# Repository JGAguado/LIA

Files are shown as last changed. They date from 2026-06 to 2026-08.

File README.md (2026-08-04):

[](LICENSE)
[][maintenance]
[][meshtastic]
[][docs]

<p align="center">
    <picture>
      <source media="(prefers-color-scheme: dark)" srcset="https://raw.githubusercontent.com/JGAguado/LIA/main/website/src/assets/brand/Primary%20dark.png">
      <source media="(prefers-color-scheme: light)" srcset="https://raw.githubusercontent.com/JGAguado/LIA/main/website/src/assets/brand/Primary%20light.png">
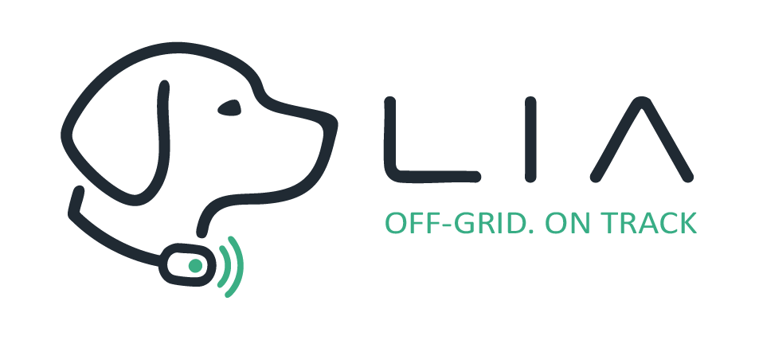
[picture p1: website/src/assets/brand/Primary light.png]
LIA logo
      
    </picture>
</p>

**LIA** is an open-source, low-power pet and asset tracker built on top of [Meshtastic](https://meshtastic.org/) and LoRa mesh networking. It's designed to be a compact, long-range, subscription-free tracking device that keeps working off-grid — no cell coverage, no monthly fee, no cloud dependency.

📖 **[Read the full documentation](https://jgaguado.github.io/LIA/)**

<p align="center">
    <a href="https://youtu.be/8NeL7x7pOoo">
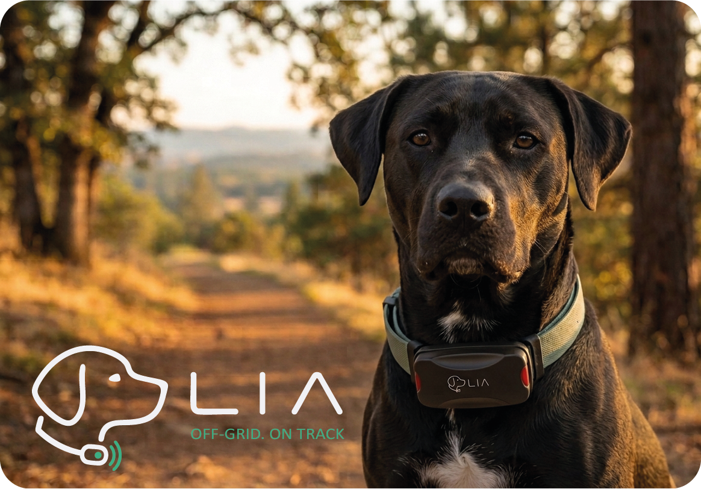
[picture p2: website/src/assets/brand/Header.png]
LIA demo video — click to watch on YouTube
      
    </a>
</p>

---

## Features

- Long-range LoRa communication over the open Meshtastic protocol
- GPS/GNSS location tracking, sent only as a direct message to a predefined target node — not visible to the wider public mesh
- A physical 3-position mode switch: continuous tracking (LED on, position every 30s), a low-power sleep cycle (wake roughly once a minute, get a fix, report it, sleep again), or fully OFF (cuts power to the MCU while still allowing the battery to charge)
- A text-command interface over the mesh: query position/battery on demand, toggle charge/motion notifications, override the status LED — see [Meshtastic Configuration](https://jgaguado.github.io/LIA/docs/firmware/meshtastic-configuration/)
- Deep-sleep, low-power firmware with real hardware wake sources (timer, mode-switch flip, charger plug-in)
- Subscription-free — no cloud backend required
- Fully open hardware: schematics, PCB layout, BOM, and enclosure CAD
- Compact, collar-mountable, waterproof-by-design enclosure — in three variants, see below

## Hardware Stack

**Core components**

- ESP32-S3-MINI-1 (MCU, Wi-Fi/BLE)
- SX1262 LoRa transceiver
- u-blox SAM-M10Q GNSS module
- MAX17048 battery fuel gauge

**Two hardware revisions, one firmware**

Both revisions carry the same reworked LSM6DSOXTR 6-axis IMU and run the identical `lia_v1` firmware — the only difference is the battery/enclosure:

- **V1.0** — 18650 Li-ion cell (3500 mAh) with magnetic pogo charging.
- **V1.1** — a 50×37×4 mm pouch cell (1000 mAh) instead, trading capacity for a much more compact enclosure.

**Antennas**

- Internal FPC LoRa antenna, or alternatively a standard omnidirectional linear 868/915 MHz antenna (e.g. [Seeed's LoRa Antenna Kit](https://www.seeedstudio.com/LoRa-Antenna-Kit-for-reTerminal-DM-p-5714.html))
- Ceramic GNSS patch antenna

See [Hardware documentation](https://jgaguado.github.io/LIA/docs/hardware/pcb/) for full details, and [Enclosure](https://jgaguado.github.io/LIA/docs/hardware/enclosure/) for the enclosure variants that pair with these boards.

## Software Stack

- [Meshtastic](https://meshtastic.org/) firmware
- [Astro](https://astro.build/) + [Starlight](https://starlight.astro.build/) + [Tailwind CSS](https://tailwindcss.com/) for this documentation site (fully static, no backend, no analytics, no cookies)

## Repository Structure

```
LIA/
├── website/       Astro + Starlight documentation & marketing site
├── firmware/       Meshtastic-based firmware (board variants, services, drivers, build tooling)
├── hardware/       KiCad project, PCB renders, schematics, BOM, production files
├── enclosure/       Enclosure CAD (gitignored native files), STEP/STL exports, renders — V1.0-Detachable/, V1.0-Fixed/, V1.1-Fixed/
├── mobile/         Companion mobile app (planned)
├── scripts/       Repo maintenance and tooling scripts
├── .github/       CI/CD workflows, issue & PR templates
├── LICENSE
├── CONTRIBUTING.md
├── CODE_OF_CONDUCT.md
└── README.md
```

## Quick Start

**Browse the docs:** https://jgaguado.github.io/LIA/

**Run the website locally:**

```sh
cd website
npm install
npm run dev
```

**Hardware:** open [`hardware/kicad/LIA.kicad_pro`](hardware/kicad/LIA.kicad_pro) in [KiCad](https://www.kicad.org/) 8+.

**Enclosure:** three versions — [`enclosure/V1.0-Detachable/`](enclosure/V1.0-Detachable), [`enclosure/V1.0-Fixed/`](enclosure/V1.0-Fixed), [`enclosure/V1.1-Fixed/`](enclosure/V1.1-Fixed) — each with its own `step/`/`stl/` exports and `drawings/`; no CAD license required to view or print them. See [Enclosure docs](https://jgaguado.github.io/LIA/docs/hardware/enclosure/) for what differs between them.

**Firmware:** see [`firmware/README.md`](firmware/README.md) and the [Getting Started guide](https://jgaguado.github.io/LIA/docs/getting-started/).

## Contributing

Contributions are welcome across hardware, firmware, mechanical design, and documentation. See [CONTRIBUTING.md](CONTRIBUTING.md) for how to get set up, and [CODE_OF_CONDUCT.md](CODE_OF_CONDUCT.md) for community guidelines.

## License

LIA is released under **[CC BY-NC-SA 4.0](LICENSE)** (Attribution-NonCommercial-ShareAlike). Personal, educational, and community use is welcome; commercial use requires permission from the maintainers. See the [License page](https://jgaguado.github.io/LIA/docs/license/) for details.

## Roadmap
- [x] Draft project requirements and design goals
- [x] Complete first hardware revision (V1.0) and a second, more compact revision (V1.1)
- [x] Complete first enclosure revisions — V1.0-Detachable, V1.0-Fixed, and V1.1-Fixed
- [x] Manufacture and assemble first batch of boards
- [x] Smoke-test and validate hardware (radio, GPS, charging, battery gauge, IMU)
- [x] Release first firmware — see [Development History](https://jgaguado.github.io/LIA/docs/development-history/) for the phase-by-phase log
- [x] Release initial documentation
- [x] Field trial: real-world tracking validation over an extended period
- [x] Measured (not estimated) battery runtime numbers

## Disclaimer

LIA is an experimental open-source project and should not be considered a guaranteed real-time safety tracking solution.

[license-shield]: https://img.shields.io/badge/License-CC%20BY--NC--SA%204.0-lightgrey.svg?style=for-the-badge
[maintenance-shield]: https://img.shields.io/badge/maintainer-J.%20G.%20Aguado-2e48a7.svg?style=for-the-badge
[maintenance]: https://github.com/JGAguado
[meshtastic-shield]: https://img.shields.io/badge/Powered%20by-Meshtastic-67EA94.svg?style=for-the-badge
[meshtastic]: https://meshtastic.org/
[docs-shield]: https://img.shields.io/badge/Documentation-online-2e48a7.svg?style=for-the-badge
[docs]: https://jgaguado.github.io/LIA/

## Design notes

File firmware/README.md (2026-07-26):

# LIA Firmware

Meshtastic-based firmware for the LIA pet tracker (ESP32-S3-MINI-1-N8). See
[`AGENTS.md`](AGENTS.md) for the full hardware spec, architecture, and
phase-by-phase roadmap, [`docs/phase-status.md`](docs/phase-status.md) for
detailed, evidence-quoted validation notes against that roadmap, and the
[Development History](https://jgaguado.github.io/LIA/docs/development-history/)
page on the docs site for the same story told chronologically.

## One board variant, two hardware revisions

There is a single firmware/board variant, `lia_v1`, and it's the correct
build for every LIA board. It requires a solder rework crossing `SDA`/`SCL`
back on the LSM6DSOXTR IMU's connection (miswired as manufactured, which
caused I2C bus errors) before I2C -- and therefore the IMU and the MAX17048
battery gauge -- can be enabled; both hardware revisions in circulation now
have that rework done. Do not assume I2C works on an unreworked board.

The two hardware revisions, **V1.0** and **V1.1**, are a **battery/enclosure
distinction only** (see
[Battery](https://jgaguado.github.io/LIA/docs/firmware/battery/) and
[Enclosure](https://jgaguado.github.io/LIA/docs/hardware/enclosure/)) -- V1.0
takes an 18650 3500mAh cell, V1.1 a 5023450 1000mAh cell. Nothing about the
firmware differs between them; there is no `lia_v2` variant.

## Repository layout

```
firmware/
├── AGENTS.md                        Hardware spec, architecture, and roadmap (read this first)
├── board/                           LiaBoard: peripheral power, RED LED, BMS switch, charger status
├── drivers/                         ImuMotionDriver -- talks to the LSM6DSOXTR directly (see below)
├── services/
│   ├── MeshTargets.h                Shared target NodeNum (kLiaTargetNode) -- see "Provisioning" below
│   ├── TrackerService.h/.cpp        Position broadcasts + the BMS state machine + manual LED override
│   ├── ChargeStatusService.h/.cpp   "Charging"/"Device charged" notifications
│   └── CommandService.h/.cpp        Text-command interface -- GPS, BATTERY, IMU/CHG/STB/LED ON/OFF, HELP
├── docs/                            Phase validation notes
├── tools/
│   ├── build.ps1                    Build/flash helper (-Upload -Port)
│   ├── gps_test/                    Standalone GPS bring-up test (no Meshtastic)
│   └── battery_test/                Standalone MAX17048 bring-up test (no Meshtastic)
└── meshtastic/                       Overlay applied on top of a Meshtastic firmware checkout
    ├── boards/lia_v1.json
    ├── variants/esp32s3/lia_v1/    (variant.h, pins_arduino.h, platformio.ini)
    └── extra_variants/lia_v1/     (variant.cpp -- init hooks + deep-sleep wake sources)
```

Meshtastic's own firmware (`meshtastic/firmware` on GitHub) is **not**
vendored into this repository — it's a large, independently-versioned
project. Building for LIA means applying the files under `meshtastic/`,
`board/`, `drivers/`, and `services/` on top of a checkout of it, the same
way any out-of-tree Meshtastic board variant is built.

## Building

`tools/build.ps1` automates the steps below (clone-if-missing, checkout the
pinned tag, copy the overlay, `pio run`). From a **native PowerShell**
session (not Git Bash/MSYS -- the ESP-IDF toolchain this platform pulls in
refuses to run under MSYS):

```powershell
cd firmware/tools
./build.ps1                              # builds lia_v1 -- correct for both V1.0 and V1.1 boards
./build.ps1 -Upload -Port COM7            # build and flash in one step
```

Or manually:

1. Clone Meshtastic's firmware repository and check out a tagged release
   (`main` is a moving development branch):

   ```powershell
   git -c core.longpaths=true clone --recurse-submodules --depth 1 `
     --branch v2.7.26.54e0d8d https://github.com/meshtastic/firmware.git meshtastic-firmware
   ```

   `core.longpaths=true` is required on Windows -- some paths inside this
   repo exceed 260 characters.

2. Copy this repo's overlay into the checkout:

   ```powershell
   Copy-Item firmware/meshtastic/boards/lia_v1.json meshtastic-firmware/boards/
   New-Item -ItemType Directory -Force meshtastic-firmware/variants/esp32s3/lia_v1
   Copy-Item firmware/meshtastic/variants/esp32s3/lia_v1/* meshtastic-firmware/variants/esp32s3/lia_v1/
   New-Item -ItemType Directory -Force meshtastic-firmware/src/platform/extra_variants/lia_v1
   Copy-Item firmware/meshtastic/extra_variants/lia_v1/* meshtastic-firmware/src/platform/extra_variants/lia_v1/
   New-Item -ItemType Directory -Force meshtastic-firmware/src/lia
   Copy-Item firmware/board/*.h, firmware/board/*.cpp meshtastic-firmware/src/lia/
   Copy-Item firmware/drivers/*.h, firmware/drivers/*.cpp meshtastic-firmware/src/lia/
   New-Item -ItemType Directory -Force meshtastic-firmware/src/lia/services
   Copy-Item firmware/services/*.h, firmware/services/*.cpp meshtastic-firmware/src/lia/services/
   ```

3. Build:

   ```powershell
   cd meshtastic-firmware
   pio run -e lia_v1
   ```

4. Flash:

   ```powershell
   pio run -e lia_v1 -t upload --upload-port <PORT>
   ```

## Provisioning

Set `device.role = TRACKER`. Everything LIA-specific (position broadcasts,
charge-status messages, and every `CommandService` command/reply) is a
direct message to a single hardcoded target node (`MeshTargets.h`'s
`kLiaTargetNode`, derived from that node's MAC), not a channel broadcast --
building your own copy means editing that constant to your own target
node's NodeNum first. See
[Meshtastic Configuration](https://jgaguado.github.io/LIA/docs/firmware/meshtastic-configuration/)
for why.

## Standalone bring-up tests

Two small, Meshtastic-free PlatformIO projects under `tools/` isolate
specific hardware questions from the rest of the firmware's complexity:

- **`tools/gps_test/`** -- powers the GNSS module and prints whatever it's
  decoded every 10 seconds.
- **`tools/battery_test/`** -- prints the MAX17048's charge percentage and
  cell voltage every 2 seconds via two independently-computed read paths
  side by side. This is what isolated a real gauge-reading bug (see
  [Battery](https://jgaguado.github.io/LIA/docs/firmware/battery/)).

Each has its own `platformio.ini` and README.

## Resolved hardware assumptions

These were open questions at some point during development and are noted
here for anyone reading history/commits rather than the current code:

- **BMS switch polarity** -- resolved in favor of `AGENTS.md`'s convention
  (HIGH = continuous, LOW = sleep-cycle) over an earlier, differently-worded
  planning doc.
- **Charger status polarity** (`CHG`/`STBY`) -- resolved against the actual
  TP4056 wiring: `CHG` active-low while charging, `STBY` pulled high
  externally while charging and pulled low by an internal switch on
  completion.
- **RED LED polarity** -- resolved against real hardware: the channel
  lights when driven high, not low as originally assumed.
- **I2C bus errors on `lia_v1`** -- resolved via a solder rework crossing
  `SDA`/`SCL` back on the IMU's connection; see "One board variant, two
  hardware revisions" above.

Still open: **SX1262 DIO2/DIO3** (`SX126X_DIO2_AS_RF_SWITCH`,
`SX126X_DIO3_TCXO_VOLTAGE 1.8`) are inherited from the Wio-SX1262 module's
reference design, not independently confirmed against LIA's own schematic.

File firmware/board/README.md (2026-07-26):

# LiaBoard

Hardware abstraction for the peripherals on LIA's board that stock Meshtastic
has no concept of. Sits between the `lia_v1` board variant and the rest of
the firmware, per `firmware/AGENTS.md`'s architecture:

```
Meshtastic Core -> Board Definition -> LiaBoard -> Drivers -> TrackerService
```

## What it owns

| Method | Backing pin | Notes |
| --- | --- | --- |
| `enablePeripherals()` / `disablePeripherals()` | `LIA_PIN_PPC` (GPIO21) | Gates power to the SX1262 and SAM-M10Q. Must be enabled before either is touched. |
| `setRedLed(uint8_t)` | `LIA_PIN_LED_RED` (GPIO40) | Active-high PWM, 0 = off / 255 = full brightness (see "Open questions"). |
| `isCharging()` | `LIA_PIN_CHG` (GPIO1) | TP4056 `CHRG`, open-drain active-low. |
| `isChargeComplete()` | `LIA_PIN_STBY` (GPIO2) | True when `STBY` reads LOW -- pulled HIGH externally while charging, pulled LOW by an internal N-MOSFET on completion (confirmed 2026-07-22, see "Open questions" below). |
| `isBmsHigh()` | `LIA_PIN_BMS` (GPIO15) | Mode-switch reading. HIGH = continuous/no-sleep, LOW = wake-every-minute sleep cycle -- see `TrackerService` (Phase 6). The switch is physically 3-position; the third (OFF) cuts power to the regulator feeding the ESP32-S3 entirely (battery still charges), so there's no firmware state for it -- `isBmsHigh()` only ever runs while the switch is already in one of the other two positions. |

It deliberately does **not** touch the SX1262 or SAM-M10Q themselves (that's
stock Meshtastic, driven by the pin `#define`s in
[`variant.h`](../meshtastic/variants/esp32s3/lia_v1/variant.h)), and never
touches the green/blue LED channels -- unavailable on this PCB revision (see
`firmware/AGENTS.md` "Hardware Constraints"). It also doesn't touch I2C: no
LIA-specific code is needed there either -- see "Open questions" below and
`firmware/services/README.md` for how the MAX17048 battery gauge (and the
LSM6DSOXTR IMU) get picked up automatically by stock Meshtastic.

## Wiring into Meshtastic

`LiaBoard` is a Meyer's singleton (`LiaBoard::instance()`) rather than a
global, per the "No globals" coding standard. It's driven from
[`extra_variants/lia_v1/variant.cpp`](../meshtastic/extra_variants/lia_v1/variant.cpp):

- `earlyInitVariant()` calls `begin()` then `enablePeripherals()`. This runs
  *before* `initSPI()` and before Meshtastic's own radio/GPS init (which
  happens later, inside `setupModules()`) -- PPC must already be high by
  then, so this cannot be done from `lateInitVariant()` (confirmed against
  `src/main.cpp` and `src/platform/extra_variants/README.md` in the
  Meshtastic checkout: `lateInitVariant()` runs *after* the LoRa radio is
  initialized).
- Deep-sleep power-down (`disablePeripherals()`) is wired to Meshtastic's
  `notifyDeepSleep` observable (Phase 6). This fires for any deep sleep path
  system-wide, not just `TrackerService`'s own `doDeepSleep()` calls --
  confirmed this actually runs for LIA: Meshtastic only *skips* calling
  `notifyDeepSleep` when `shouldLoraWake()` is true, which is only the case
  for `ROUTER`/`ROUTER_LATE` roles (`sleep.cpp`), not `TRACKER`.
  **Registration point matters**: `RadioInterface::init()` and
  `GPS::setup()` *each also* register their own `notifyDeepSleep` observer
  (to command the SX1262/GNSS to standby gracefully over SPI/UART while
  still powered), both before `lateInitVariant()` runs. `Observable` fires
  observers in registration order, so `armDeepSleepHook()` (which does the
  actual `.observe()` call) must be called from `lateInitVariant()`, *not*
  from `begin()`/`earlyInitVariant()` -- registering earlier cuts PPC before
  those graceful commands can reach the hardware. Confirmed by a real crash
  (`SX126xInterface::setStandby()` failing with `RadioLib err=-707` once PPC
  had already gone low first) before this was fixed.

## Open questions

- ~~**I2C bus errors.**~~ As-manufactured, SDA/SCL were crossed on the
  LSM6DSOXTR IMU's connection, causing bus errors -- `variant.h` originally
  forbade defining `I2C_SDA`/`I2C_SCL` at all. This unit has since had a
  solder rework crossing them back (2026-07-22); `variant.h` now defines
  those macros (GPIO4/5). **This does not apply to an unreworked board** --
  don't assume I2C works without the same rework.
- ~~**RED LED polarity.**~~ Resolved 2026-07-22: `setRedLed()` was assumed
  common-anode (channel lights when driven LOW) and inverted its duty cycle
  accordingly. Real hardware showed the LED ON while BMS read LOW (which
  calls `setRedLed(0)`, intending OFF) -- the channel actually lights when
  driven HIGH, so the inversion was removed. Confirmed against
  `TrackerService`'s already-independently-confirmed BMS branching (send
  cadence, sleep triggering), so the mismatch was isolated to the LED driver,
  not the BMS read.
- ~~**BMS polarity.**~~ Resolved 2026-07-19: follow `firmware/AGENTS.md`
  (Phase 6) as the authoritative source -- BMS HIGH is continuous/no-sleep,
  BMS LOW is the wake-every-minute sleep cycle. `MOD.md`'s opposite polarity
  ("BMS high = Tracker mode" = the sleepy behaviour) is not used.
- ~~**Charger status polarity.**~~ Resolved 2026-07-22: `isCharging()` is
  `CHG` active-low (an internal N-MOSFET pulls it low while charging;
  external pull-up otherwise) -- matches the original datasheet assumption,
  unchanged. `isChargeComplete()` is `STBY` active-low (external pull-up
  holds it HIGH while charging; an internal N-MOSFET pulls it LOW on
  completion) -- this briefly went through an incorrect active-HIGH flip
  earlier in Phase 7 (per an instruction that didn't match the actual
  wiring) before being corrected back to active-low against the real board
  behaviour.
- **GPS fix-wait timeout for the BMS-low sleep cycle** (`TrackerService.h`'s
  `kFixWaitTimeoutMs`, currently 90s) is a real tradeoff (battery vs. fresh
  position) not yet validated against actual cold/warm-fix timing outdoors --
  see the website's power-management.md "GPS fix timeout" note.

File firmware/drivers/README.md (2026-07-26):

# Drivers

## ImuMotionDriver

Talks to the LSM6DSOXTR IMU (`lia_v1` only) directly via `Adafruit_LSM6DSOX`,
bypassing Meshtastic's own `AccelerometerThread`/motion-sensor support:
`ScanI2CTwoWire` resolves this chip's `WHO_AM_I` (`0x6C`) to its `QMI8658`
device type, which `AccelerometerThread` has no `case` for at all -- it
silently falls through to `disable()`, so stock Meshtastic never actually
drives this sensor. `Adafruit_LSM6DSOX` is the correct match instead: `0x6C`
is exactly that class's expected chip ID.

Owned by `CommandService` (not a Meyer's singleton like `LiaBoard` -- nothing
else needs to reach it), which starts/stops it on the `IMU ON`/`IMU OFF`
commands (see `../services/README.md`). Arms a real hardware interrupt on
`LIA_PIN_IMU_INT` rather than polling the sensor's status register: the ISR
only sets a flag (I2C isn't interrupt-safe), consumed from a normal task
context to send the actual "Activity detected" mesh message.

## What's still handled elsewhere

- **SX1262 radio** and **SAM-M10Q GNSS** -- stock Meshtastic behaviour,
  switched on purely by the pin `#define`s in
  [`../meshtastic/variants/esp32s3/lia_v1/variant.h`](../meshtastic/variants/esp32s3/lia_v1/variant.h).
  Meshtastic already contains a full SX1262 (RadioLib) and NMEA/UBX GPS
  stack.
- **Peripheral power, status LED, mode switch, charger status** -- owned by
  [`../board/LiaBoard.*`](../board/README.md), since none of them are stock
  Meshtastic concepts but all are simple enough (plain GPIO/PWM) not to
  warrant a separate driver class.
- **MAX17048 battery gauge** -- no dedicated driver class; `CommandService`
  reads it directly with `Adafruit_I2CDevice`/`Adafruit_BusIO_Register` (see
  `../services/README.md` for why, and `../tools/battery_test/` for the
  standalone test that isolated a real reading bug).

If a future phase needs a peripheral that doesn't fit either of those
buckets, it belongs here as its own subdirectory with a `README.md`,
`examples`, and `tests`, per `firmware/AGENTS.md`'s repository layout.

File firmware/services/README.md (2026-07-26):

# Services

## Battery gauge + IMU (I2C)

`variant.h` defines `I2C_SDA`/`I2C_SCL`, which is enough for stock
Meshtastic's `Wire.begin(I2C_SDA, I2C_SCL)` + `i2cScanner->scanPort()`
(`src/main.cpp`) to detect both parts at boot -- confirmed via the boot log
(`MAX17048 found at address 0x36`, `QMI8658 found at address 0x6b`, `2 I2C
devices found`). This only works because of a solder rework crossing
SDA/SCL back on the IMU's connection (2026-07-22) -- see `board/README.md`
"Open questions" for why the bus was unusable before that.

Detection stops there for the IMU, though: `ScanI2CTwoWire` resolves the
LSM6DSOXTR's `WHO_AM_I` (0x6C) to its `QMI8658` device type, and
`AccelerometerThread` (`motion/AccelerometerThread.h`) has no `case` for
that type at all -- it silently falls through to `disable()`. So unlike the
gauge, stock Meshtastic never actually drives this IMU. `CommandService`'s
`ImuMotionDriver` (`drivers/ImuMotionDriver.*`) talks to it directly instead,
via `Adafruit_LSM6DSOX` (0x6C matches that class's expected chip ID exactly,
unlike the `Adafruit_LSM6DS3TRC` class Meshtastic's own `LSM6DS3Sensor.cpp`
uses for a different chip ID).

Similarly, `CommandService`'s `BATTERY` command reads the `Adafruit_MAX1704X`
gauge directly rather than through `powerStatus->getBatteryChargePercent()`:
`Power::setup()` runs its own battery-source detection *before* `main.cpp`'s
I2C scan populates the sensor map that detection depends on, so it always
sees "not ready yet" at boot and locks in a 101% ("no battery, external
power") fallback that never gets corrected later -- confirmed on real
hardware (2026-07-22), even though the gauge is genuinely present and
working.

## MeshTargets.h

Shared configuration used by every service that reports to the configured
target node: `kLiaTargetNode` (NodeNum, per `firmware/AGENTS.md` "Target
Node") lives in `MeshTargets.h` -- the one place it's defined, so
`TrackerService`, `ChargeStatusService`, and `CommandService` can't drift
apart. Everything LIA-specific is a direct message (`p->to = kLiaTargetNode`)
to this node, never a channel broadcast -- per explicit instruction
(2026-07-26), superseding an earlier design that routed everything through a
channel found by name (`kLiaChannelName`/`ChannelLookup.h/.cpp`, both
removed). That design worked but required out-of-band channel setup and
failed closed silently when misconfigured; a direct message already
requires knowing/pairing with the target node and is commonly
PKI-encrypted by the official app to that node's identity key, so it isn't
a weaker bar than possessing a channel's PSK.

## TrackerService

Owns periodic mesh transmissions and the tracker/beacon state machine, per
`firmware/AGENTS.md`'s architecture. Sends the current GPS position
(`meshtastic_Position`, port `POSITION_APP`) as a unicast, built from the
global `localPosition` (`NodeDB.h`) the same way stock `PositionModule.cpp`
does -- skips the send if there's no fix yet (lat/lon both zero) rather than
sending a meaningless (0,0). The destination is `kLiaTargetNode`
(`MeshTargets.h`).

### Direct-message targeting

Position packets are sent as a direct message to `kLiaTargetNode`, never a
broadcast on any channel. Meshtastic encrypts per-channel (not
per-recipient) and `PositionModule` processes any overheard position packet
promiscuously regardless of its `to` field, so broadcasting on any channel
would let *any* node holding that channel's PSK map this device -- a direct
message to a specific node, commonly PKI-encrypted by the official
app/firmware, restricts visibility to that one node instead, per explicit
instruction (2026-07-26; see "MeshTargets.h" above for why this replaced an
earlier private-channel design).

Behaviour switches on `LiaBoard::instance().isBmsHigh()` (Phase 6):

- **HIGH ("continuous")**: RED LED solid on, send every 30s
  (`kContinuousIntervalMs`), never sleeps.
- **LOW ("sleep-cycle")**: send once, then deep sleep for a minute
  (`kSleepCycleMs`) via `doDeepSleep()`. `LiaBoard`'s `notifyDeepSleep`
  observer cuts PPC (both SX1262 and GPS power, shared rail) before power-off.
  The next wake is a full reboot -- construction and `runOnce()` start fresh,
  so no state survives between wakes except what's in `localPosition`
  (persisted by the GPS subsystem, not us). Waits up to `kFixWaitTimeoutMs`
  (90s) for a fix before giving up on the cycle and sleeping anyway, rather
  than hunting indefinitely and draining the battery.

### Manual LED override

`setManualLed(bool on)` (reached via `TrackerService::instance()`, used by
`CommandService`'s `LED ON`/`LED OFF`) sets the LED immediately and a
one-way flag that makes `runOnce()` stop driving it from BMS state from then
on. There is no "back to automatic" command -- a fresh boot (e.g. after the
BMS-LOW sleep cycle's reboot) starts back in automatic mode, since the flag
isn't persisted.

Requires the device to be configured with `device.role = TRACKER` (not the
default) for the sleep behaviour to work as intended -- confirmed against
`PowerFSM.cpp` and `sleep.cpp`: stock Meshtastic only auto-adds its own
competing light-sleep timers for non-tracker roles ("sleep will be initiated
through the modules" for trackers), and `notifyDeepSleep` (which
`LiaBoard` needs to cut PPC) is only skipped for `ROUTER` roles. Setting the
role is a runtime app/CLI config change, not something this firmware hardcodes
(matching "configurable through the official Meshtastic application").

Phase history: Phase 2 introduced it inline in
`extra_variants/lia_v1/variant.cpp` as a fixed "LIA Radio Test" text payload;
Phase 3.5 moved it here as a proper `SinglePortModule` + `OSThread`; Phase 5
replaced the text payload with the real position; Phase 6 added the BMS
state machine and deep sleep.

Constructed once from `lateInitVariant()` (`new TrackerService();`) --
nothing else needs to reference the instance, so no global pointer is kept
(MeshModule/OSThread both self-register on construction).

## ChargeStatusService

Reports `LiaBoard`'s charger status to `kLiaTargetNode` as a direct message
(`TEXT_MESSAGE_APP`) -- Phase 7, per explicit instruction (2026-07-22) to
send messages instead of the RED LED breathing/off behaviour
`firmware/AGENTS.md` originally specified for this phase (see
`firmware/AGENTS.md` "Phase 7").

Polls `LiaBoard::instance().isCharging()` / `isChargeComplete()` every 3s
(`kPollIntervalMs`) and sends edge-triggered, not on every poll: `"Charging"`
once when `isCharging()` goes false->true, `"Device charged"` once when
`isChargeComplete()` goes false->true. Neither message repeats while its
condition stays asserted.

`isChargeComplete()`'s `STBY` read is active-low (see `board/README.md`
"Open questions" for the actual pull-up/N-MOSFET wiring) -- it briefly went
through an incorrect active-HIGH flip earlier in this phase before being
corrected back against the real board behaviour.

Constructed once from `lateInitVariant()` (`new ChargeStatusService();`) --
same self-registration pattern as `TrackerService`, no global pointer kept.

## CommandService

Responds to short text commands, per explicit instruction (2026-07-22).

Accepts a command only if it arrives as a direct message addressed to us
specifically (`mp.to == nodeDB->getNodeNum()`) -- per explicit instruction
(2026-07-26), superseding an earlier design that also (or instead) gated on
a private channel found by name. A DM sent through the official app is
commonly PKI-encrypted, which bypasses the channel/PSK system entirely and
reports `channel=0` no matter which channel was open when it was sent --
confirmed on real hardware (2026-07-22). Being addressed directly to our
node already requires the sender to know/have paired with us, and PKI
authenticates to their actual identity key, so this isn't a weaker bar than
channel-PSK possession.

Commands (case-insensitive and whitespace-normalized -- extra/mixed spaces
or tabs between the two words of an ON/OFF command still match, e.g. "led
 off" or "Led  Off" both match `LED OFF`; unrecognized text is silently
ignored, since a DM to this device may carry normal chat too):

| Command | Behaviour |
| --- | --- |
| `GPS` | Replies with the current `localPosition` lat/lon, or "No GPS fix yet". |
| `BATTERY` | Replies with the MAX17048's charge percentage (see "Battery gauge + IMU" above for why this reads the gauge directly). |
| `IMU ON` | Starts `ImuMotionDriver` (begin()s the sensor + arms its GPIO interrupt on first use) and polls it every 250ms; sends "Activity detected" once per motion event as a direct message to `kLiaTargetNode` (same destination `TrackerService`/`ChargeStatusService` use, not a reply to whoever sent `IMU ON`). |
| `IMU OFF` | Detaches the interrupt; stops polling. |
| `CHG ON` / `CHG OFF` | Toggles `ChargeStatusService::instance()->setChargingNotificationsEnabled()`. |
| `STB ON` / `STB OFF` | Toggles `ChargeStatusService::instance()->setChargeCompleteNotificationsEnabled()`. |
| `LED ON` / `LED OFF` | Calls `TrackerService::instance()->setManualLed()` -- see `TrackerService`'s own doc below for the one-way-override caveat. |
| `HELP` | Replies with the command list. |

Commands originally used an underscore (`IMU_ON`) and were briefly
concatenated with no separator (`IMUON`) before settling on a space, per
explicit instruction (2026-07-24) -- real usage showed people naturally
type "Led off" with a space.

Replies to a command go back as a direct message to whoever sent it
(`isPromiscuous = true` so the module sees all traffic on its port, but only
messages addressed directly to us are acted on -- see above).

`ChargeStatusService::instance()`/`TrackerService::instance()` are
self-registering static pointers set in each class's own constructor (not a
lazily-constructed Meyer's singleton like `LiaBoard`, since their
construction *timing* matters -- both must happen from `lateInitVariant()`,
in a specific order (`TrackerService`, then `ChargeStatusService`, then
`CommandService`) -- the same pattern Meshtastic's own globals (`nodeDB`,
`service`, `screen`, ...) already use.

Constructed once from `lateInitVariant()`, after `TrackerService` and
`ChargeStatusService` (`new CommandService();`) -- no global pointer kept,
nothing else needs to reach this one.

### Battery gauge reading confirmed correct (2026-07-24)

`BATTERY` kept reporting ~0-1% even after the no-reset fix above. Built a
standalone `firmware/tools/battery_test/` project (no Meshtastic -- see its
README) to compare the no-reset raw register read against the stock
`Adafruit_MAX17048` library side by side, isolated from any
Meshtastic-specific interaction. Both paths agreed exactly and neither
improved over ~28s of samples (ruling out "just needs time to reconverge
after reset"), while `VCELL` read a stable ~2.95-2.96V -- confirmed
independently with a multimeter at ~3.0V, within normal measurement
tolerance. A LiPo cell at ~3.0V is close to a typical low-voltage cutoff, so
a near-0% state of charge is a genuinely correct reading, not a bug -- no
further code change was needed.

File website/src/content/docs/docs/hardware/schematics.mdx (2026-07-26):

---
title: Schematics
description: Full schematic PDF for the LIA main board.
---

import PdfEmbed from '../../../../components/PdfEmbed.astro';

The schematic below is exported directly from the KiCad project in [`hardware/kicad/`](https://github.com/JGAguado/LIA/tree/main/hardware/kicad).

<PdfEmbed src="/LIA/files/LIA-schematic.pdf" title="LIA schematic" />

## Reference designs

Some subcircuits (battery charging, buck-boost regulation) are adapted from published reference designs. Source references are kept locally under `hardware/schematics/references/`, which isn't published in the repository (third-party datasheets/reference material, not LIA's own original work).

:::caution
The schematic is a work in progress and has not yet been through a formal design review. If you build from it, double-check power and charging circuitry before connecting a battery.
:::

See also: [PCB](/LIA/docs/hardware/pcb/) and [BOM](/LIA/docs/hardware/bom/).

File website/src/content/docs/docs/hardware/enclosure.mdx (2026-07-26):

---
title: Enclosure
description: LIA's enclosure designs — three collar-mounted, gasket-sealed shells for the two board revisions.
---

import { Tabs, TabItem } from '@astrojs/starlight/components';
import Gallery from '../../../../components/Gallery.astro';
import StlViewer from '../../../../components/StlViewer.astro';

import v10dAssembly1 from '../../../../../../enclosure/V1.0-Detachable/renders/assembly-1.jpg';
import v10dAssembly2 from '../../../../../../enclosure/V1.0-Detachable/renders/assembly-2.jpg';
import v10dExplode from '../../../../../../enclosure/V1.0-Detachable/renders/explode-view.jpg';
import v10fAssembly1 from '../../../../../../enclosure/V1.0-Fixed/renders/assembly-1.jpg';
import v10fAssembly2 from '../../../../../../enclosure/V1.0-Fixed/renders/assembly-2.jpg';
import v10fExplode from '../../../../../../enclosure/V1.0-Fixed/renders/explode-view.jpg';
import v11fAssembly1 from '../../../../../../enclosure/V1.1-Fixed/renders/assembly-1.jpg';
import v11fAssembly2 from '../../../../../../enclosure/V1.1-Fixed/renders/assembly-2.jpg';
import v11fExplode from '../../../../../../enclosure/V1.1-Fixed/renders/explode-view.jpg';

There are three enclosure designs, tracking two board revisions and two mounting styles. All three clip onto a standard collar strap and have a separate window over the status LED.

:::note
**V1.0** and **V1.1** are identical at the firmware/electronics level. The only difference between them is the battery they're built around (see [Battery](/LIA/docs/firmware/battery/)), which is what actually drives the enclosure split below.
:::

| Version | Fits board | Battery | Mounting |
| --- | --- | --- | --- |
| **V1.0-Detachable** | V1.0 | 18650 Li-ion, 3500 mAh | Detachable — clips onto a separate collar piece via a plug-latch mechanism |
| **V1.0-Fixed** | V1.0 | 18650 Li-ion, 3500 mAh | Fixed — mounts directly on the collar, not easily detachable |
| **V1.1-Fixed** | V1.1 | 50×37×4 mm pouch cell, 1000 mAh | Fixed — mounts directly on the collar, same style as V1.0-Fixed |

The bigger 18650 cell needs more internal volume, which is what the V1.0 designs are sized for; V1.1-Fixed is built around the smaller, thinner pouch cell instead, trading capacity for a noticeably more compact shell. V1.0-Fixed and V1.1-Fixed share the fixed, non-detachable mounting style — V1.0-Detachable is the only one with the separate, detachable collar piece.

<Tabs>
  <TabItem label="V1.0-Detachable">

Detachable: the board enclosure clips onto a separate collar piece through a plug-latch mechanism, so the tracker can be removed from the collar without undoing the collar strap itself. Sized for the 18650 cell.

<Gallery
  id="enclosure-v10d-renders"
  images={[
    { src: v10dAssembly1, alt: 'V1.0-Detachable enclosure assembly render, closed' },
    { src: v10dAssembly2, alt: 'V1.0-Detachable enclosure assembly render, alternate angle' },
    { src: v10dExplode, alt: 'V1.0-Detachable enclosure exploded view showing internal parts' },
  ]}
/>

Drag to rotate, scroll to zoom.

<div style="display: grid; grid-template-columns: repeat(auto-fit, minmax(14rem, 1fr)); gap: 1.5rem; margin: 1.5rem 0;">
  <StlViewer src="/LIA/generated/stl/v1.0-detachable/Top_enclosure.stl" label="Top shell" />
  <StlViewer src="/LIA/generated/stl/v1.0-detachable/Bottom_enclosure.stl" label="Bottom shell" />
  <StlViewer src="/LIA/generated/stl/v1.0-detachable/Window.stl" label="Window" />
  <StlViewer src="/LIA/generated/stl/v1.0-detachable/Top_collar.stl" label="Collar top" />
  <StlViewer src="/LIA/generated/stl/v1.0-detachable/Bottom_collar.stl" label="Collar bottom" />
  <StlViewer src="/LIA/generated/stl/v1.0-detachable/Latch.stl" label="Latch" />
</div>

  </TabItem>
  <TabItem label="V1.0-Fixed">

Compatible with the V1.0 board (same 18650 cell), but the shell mounts directly on the collar instead of clipping onto a separate detachable piece — no plug-latch mechanism, no separate collar part.

<Gallery
  id="enclosure-v10f-renders"
  images={[
    { src: v10fAssembly1, alt: 'V1.0-Fixed enclosure assembly render, closed' },
    { src: v10fAssembly2, alt: 'V1.0-Fixed enclosure assembly render, alternate angle' },
    { src: v10fExplode, alt: 'V1.0-Fixed enclosure exploded view showing internal parts' },
  ]}
/>

Drag to rotate, scroll to zoom.

<div style="display: grid; grid-template-columns: repeat(auto-fit, minmax(14rem, 1fr)); gap: 1.5rem; margin: 1.5rem 0;">
  <StlViewer src="/LIA/generated/stl/v1.0-fixed/Top_enclosure.stl" label="Top shell" />
  <StlViewer src="/LIA/generated/stl/v1.0-fixed/Bottom_enclosure.stl" label="Bottom shell" />
  <StlViewer
    src="/LIA/generated/stl/v1.0-fixed/Bottom_enclosure_2.stl"
    label="Bottom shell, alternate"
  />
  <StlViewer src="/LIA/generated/stl/v1.0-fixed/Window.stl" label="Window" />
  <StlViewer src="/LIA/generated/stl/v1.0-fixed/Top_collar.stl" label="Collar top" />
  <StlViewer src="/LIA/generated/stl/v1.0-fixed/Bottom_collar.stl" label="Collar bottom" />
  <StlViewer src="/LIA/generated/stl/v1.0-fixed/Latch.stl" label="Latch" />
  <StlViewer src="/LIA/generated/stl/v1.0-fixed/Antenna_elbow.stl" label="Antenna elbow" />
</div>

  </TabItem>
  <TabItem label="V1.1-Fixed">

Compatible with the V1.1 board and its smaller 50×37×4 mm / 1000 mAh pouch cell, which allows a noticeably more compact shell than the 18650-based V1.0 designs — the tradeoff is less capacity, so shorter runtime between charges (see [Power Management](/LIA/docs/firmware/power-management/)). Mounts directly on the collar, same fixed style as V1.0-Fixed.

<Gallery
  id="enclosure-v11f-renders"
  images={[
    { src: v11fAssembly1, alt: 'V1.1-Fixed enclosure assembly render, closed' },
    { src: v11fAssembly2, alt: 'V1.1-Fixed enclosure assembly render, alternate angle' },
    { src: v11fExplode, alt: 'V1.1-Fixed enclosure exploded view showing internal parts' },
  ]}
/>

Drag to rotate, scroll to zoom.

<div style="display: grid; grid-template-columns: repeat(auto-fit, minmax(14rem, 1fr)); gap: 1.5rem; margin: 1.5rem 0;">
  <StlViewer src="/LIA/generated/stl/v1.1-fixed/Top_enclosure.stl" label="Top shell" />
  <StlViewer src="/LIA/generated/stl/v1.1-fixed/Bottom_enclosure.stl" label="Bottom shell" />
  <StlViewer src="/LIA/generated/stl/v1.1-fixed/Window.stl" label="Window" />
  <StlViewer src="/LIA/generated/stl/v1.1-fixed/Collar_bridge.stl" label="Collar bridge" />
  <StlViewer src="/LIA/generated/stl/v1.1-fixed/Antenna_elbow.stl" label="Antenna elbow" />
</div>

  </TabItem>
</Tabs>

See also: [Assembly](/LIA/docs/hardware/assembly/) and [Downloads](/LIA/docs/downloads/).

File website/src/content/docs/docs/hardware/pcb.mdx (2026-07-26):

---
title: PCB
description: LIA's main board — layout, renders, and design files.
---

import Gallery from '../../../../components/Gallery.astro';
import isometric1 from '../../../../../../hardware/pcb/renders/Isometric_1.png';
import isometric2 from '../../../../../../hardware/pcb/renders/Isometric_2.png';
import top from '../../../../../../hardware/pcb/renders/Top.png';
import bottom from '../../../../../../hardware/pcb/renders/Bottom.png';
import layout from '../../../../../../hardware/pcb/renders/Layout.png';

LIA's main board is designed in [KiCad](https://www.kicad.org/) and built around an ESP32-S3-MINI-1 module, an SX1262 LoRa transceiver, and a u-blox SAM-M10Q GNSS module.

<Gallery
  id="pcb-renders"
  images={[
    { src: layout, alt: 'PCB component layout' },
    { src: top, alt: 'PCB top copper layer' },
    { src: bottom, alt: 'PCB bottom copper layer' },
    { src: isometric1, alt: 'PCB isometric render, front' },
    { src: isometric2, alt: 'PCB isometric render, angled' },
  ]}
/>

## Core components

| Function | Part |
| --- | --- |
| MCU + Wi-Fi/BLE  | ESP32-S3-MINI-1-N8 |
| LoRa transceiver | [Wio-SX1262](https://www.seeedstudio.com/Wio-SX1262-LF-Wireless-Module-p-6659.html) |
| GNSS | u-blox SAM-M10Q |
| Power | 18650 (V1.0) or 5023450 pouch cell (V1.1) Li-ion + USB-C charging — see [Battery](/LIA/docs/firmware/battery/) |

## Antennas

- YFNF868F3AM FPC LoRa antenna (868MHz), the default on-board option — or alternatively, a standard omnidirectional linear antenna for the 868/915MHz band, plugged into the same connector on the SX1262 module (see [Assembly](/LIA/docs/hardware/assembly/)), such as [Seeed's LoRa Antenna Kit](https://www.seeedstudio.com/LoRa-Antenna-Kit-for-reTerminal-DM-p-5714.html)
- Ceramic GNSS patch antenna

## Design files

The full KiCad project lives under [`hardware/kicad/`](https://github.com/JGAguado/LIA/tree/main/hardware/kicad) in the repository, and a 3D model export is available at [`hardware/pcb/LIA_PCB.step`](https://github.com/JGAguado/LIA/tree/main/hardware/pcb). See [Downloads](/LIA/docs/downloads/) for direct links.

See also: [Schematics](/LIA/docs/hardware/schematics/) and [BOM](/LIA/docs/hardware/bom/).

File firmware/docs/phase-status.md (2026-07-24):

# Phase status

Tracks each roadmap phase in `../AGENTS.md` against its Definition of Done
(deliverables complete, user validation pass, no regressions, docs updated).
"User validation" always requires physical hardware and is out of reach for
an AI agent -- those boxes can only be checked by whoever has the board in
hand.

| Phase | Code deliverables | User validation |
| --- | --- | --- |
| 0 -- Board Bring-up | Done, flashed and confirmed booting on real hardware (COM4) | Done (agent-verified via serial log; see below) |
| 1 -- PPC Validation | Done -- indirectly confirmed: GPS and radio both respond over their buses, which requires PPC/power to be up (see below) | Multimeter check still pending, but functionally demonstrated |
| 2 -- SX1262 Integration | Done, verified end-to-end on real hardware (see below) | Done -- user paired via the official app, set the region, and confirmed receiving "LIA Radio Test" on the destination node |
| 3 -- Radio Validation | N/A (physical range/sleep-wake test only) | Stable RF communication confirmed (real TX + real RX with rxSNR=6/rxRSSI=-49 from a 39-node mesh, see Phase 5 notes); range/sleep-wake walk test still pending |
| 3.5 -- TrackerService | Done, confirmed sending every 30s on real hardware (see below) | N/A |
| 4 -- SAM-M10Q Integration | Done -- nothing to build, stock Meshtastic auto-detects the module (`GNSS_MODEL_UBLOX10`) and handles NMEA/UBX via the Phase 0 pin config | Cold/warm fix timing and PPC power-cycling still need outdoor testing |
| 5 -- GPS + Meshtastic | Done, `TrackerService` now sends real `meshtastic_Position` packets (see below) | GPS icon / actual position receipt still pending an outdoor fix |
| 6 -- Tracker Behaviour | Done, both BMS-HIGH and BMS-LOW paths confirmed on real hardware across multiple full sleep/wake cycles (see below) | Toggle-without-reflashing confirmed for BMS LOW; HIGH<->LOW toggle-while-running not yet explicitly re-tested |
| 7 -- Charging Behaviour | Not started | Pending |
| 8 -- Deep Sleep | Partially done as a side effect of Phase 6 (RTC-timer wake via `doDeepSleep`, confirmed repeatable); BMS-wake and USB-wake sources still pending | Pending |
| 9 -- Power Validation | N/A (physical measurement only) | Pending |
| 10 -- Field Trial | N/A (physical trial only) | Pending |

## Phase 0 notes

- PlatformIO `lia_v1` environment created under `../meshtastic/`.
- `LiaBoard` singleton created under `../board/`, wired via
  `earlyInitVariant()` so PPC is high before Meshtastic's own SPI/radio init
  runs.
- Build verified clean against a fresh `meshtastic/firmware @
  v2.7.26.54e0d8d` checkout: `pio run -e lia_v1` succeeded (4m36s), producing
  a flashable `firmware-lia_v1-2.7.26.54e0d8d.factory.bin`. RAM 40.3% (132024
  / 327680 B), Flash 62.8% (2098013 / 3342336 B). One fix was needed along
  the way: `pins_arduino.h` had to declare `SDA`/`SCL` pin constants even
  though I2C is unused, because Arduino-ESP32's `Wire.cpp` references them
  unconditionally at compile time -- this does not initialize or scan the
  bus (see the comment in `pins_arduino.h`).
- **Flashed to real hardware and confirmed booting**, via the agent (see
  `AGENTS.md` "Flashing & Validation Workflow"): a board was connected on
  COM4 (ESP32-S3, 8MB flash, USB-Serial/JTAG, MAC 38:44:be:c8:16:84 -- matches
  our board config exactly). `pio run -e lia_v1 -t upload --upload-port COM4`
  succeeded, and a serial capture showed a clean boot: NodeInfo broadcast,
  packet history, AES128 key expansion, and the radio subsystem correctly
  gating TX with `lora tx disabled: Region unset` (expected -- no region
  configured yet). No crash, no reboot loop.

## Phase 2 notes

- Added `LiaTestModule` (`SinglePortModule` + `OSThread`, in
  `extra_variants/lia_v1/variant.cpp`) sending "LIA Radio Test" as a unicast
  to NodeNum `0xDCE6D663` (the low 32 bits of target MAC `E7:25:DC:E6:D6:63`,
  matching `NodeDB.cpp`'s own derivation) every 30s, instantiated from
  `lateInitVariant()`.
- **First on-device test crashed** (`Guru Meditation Error: LoadProhibited`,
  reboot loop). Diagnosed with `xtensa-esp32s3-elf-addr2line` against the
  built `.elf` rather than guessing from logs alone:
  1. First fix (necessary but not sufficient): `runOnce()` dereferenced the
     global `airTime` before it's constructed. `lateInitVariant()` runs
     right after `initLoRa()` in `main.cpp`, but `airTime = new AirTime()`
     doesn't happen until ~40 lines later -- `router` and `service` are
     already valid by then, `airTime` isn't. Added a null guard.
  2. Real root cause (found after the crash persisted, addr2line pointed
     straight at it): `earlyInitVariant()`'s `LOG_INFO(...)` call was crashing
     in `RedirectablePrint::log()`. `earlyInitVariant()` is the *second* call
     in `setup()` (right after `waitUntilPowerLevelSafe()`), well before the
     console/logging subsystem is up -- logging that early isn't safe on this
     platform. Removed the log call from `earlyInitVariant()`; moved the
     equivalent confirmation line into `lateInitVariant()`, which is known-
     good (Phase 0's boot log already showed plenty of successful logging
     from that point on).
- Both fixes are in and the build is clean. On-device confirmation was
  temporarily blocked by 4 consecutive esptool write-timeouts on COM4 (the
  Windows USB/serial stack got wedged by the rapid crash/reboot cycling, not
  a build or hardware fault) -- a physical USB replug (user's step) cleared
  it immediately, same port/serial number.
- **Confirmed working on real hardware** after the replug: clean boot, no
  crash, and the serial log shows the full pipeline succeeding:
  ```
  [LiaTest] Setting next hop for packet with dest dce6d663 to 0
  [LiaTest] send - lora tx disabled: Region unset
  [LiaTest] LiaTestModule: sent "LIA Radio Test" to 0xdce6d663
  ```
  Destination NodeNum matches the derivation exactly. Gated on "Region
  unset" is correct/expected Meshtastic behavior, not a bug -- actual RF
  transmission needs a region set first (regulatory, see `firmware`'s
  lora.md-equivalent guidance) which hasn't been done since that's a
  real-world RF-emission decision, not a build step.
- Bonus signal for Phase 1/4: the log also shows the GPS module actively
  responding over UART (NAK on a powersave command, but real two-way
  traffic, then "GNSS module configuration saved!") -- since GPS is on the
  PPC-gated rail alongside the SX1262, this is de facto evidence PPC control
  is working, ahead of an actual multimeter check.
- **User confirmed real end-to-end delivery**: paired with the official
  Meshtastic app, set the region, and received "LIA Radio Test" on the
  destination node (MAC `E7:25:DC:E6:D6:63`). This is genuine, independent
  confirmation from the receiving side of the link, not just our own serial
  log.

## Phase 3.5 notes

- Moved the sender out of `extra_variants/lia_v1/variant.cpp` into
  `services/TrackerService.{h,cpp}` (same `SinglePortModule` + `OSThread`
  logic, renamed `LiaTestModule` -> `TrackerService`, module name "Tracker").
  `lateInitVariant()` now just does `new TrackerService();`. Build succeeded
  clean (including both new files) on the first try -- no new bugs, since
  this was a pure move/rename of already-verified code.
- On-device reflash hit a *different* USB hiccup first: `ClearCommError
  failed (PermissionError...)` on connect. `Get-PnpDevice` showed the board's
  USB composite device and JTAG/serial debug interface both `Status: OK`,
  but the `Ports` (COM4) sub-interface specifically `Status: Unknown` -- same
  class of Windows USB-serial wedge as the Phase 2 episode, not a build
  problem. Cleared by another physical replug.
- **Confirmed working on real hardware**: two sends 31s apart
  (`uptime 31.307s` then `62.211s`, matching the 30000ms return from
  `runOnce()`), both logged as `[Tracker] TrackerService: sent "LIA Radio
  Test" to 0xdce6d663`. No crash.
- New (unrelated to our code) warning observed in this capture:
  `SX126x AGC reset: calibration did not complete within 50ms`, from stock
  RadioLib. Not a crash and didn't block the send, but worth watching once a
  region is set and real RF is active -- possibly related to the Wio-SX1262
  TCXO timing assumption already flagged in `variant.h` for Phase 2.

## Phase 4 notes

No new code. `src/gps/GPS.cpp` already auto-probes and identifies the
SAM-M10Q as `GNSS_MODEL_UBLOX10`, then runs stock NMEA/UBX handling -- all
switched on purely by the `GPS_RX_PIN`/`GPS_TX_PIN`/`HAS_GPS` defines already
in `variant.h` since Phase 0. The "powersave" NAK observed in earlier
captures is a benign quirk in that stock code path (not ours to patch, per
"never edit Meshtastic core").

## Phase 5 notes

- `TrackerService`'s constructor now uses `meshtastic_PortNum_POSITION_APP`
  instead of `TEXT_MESSAGE_APP`. `runOnce()` builds a `meshtastic_Position`
  from the global `localPosition` (`NodeDB.h`, kept current by the GPS
  subsystem) and `pb_encode_to_bytes`s it into the packet payload, matching
  stock `PositionModule.cpp`'s own pattern exactly. Skips the send (logging
  `TrackerService: no GPS fix yet, skipping send`) when latitude/longitude
  are both still zero -- the same guard stock Meshtastic uses, since a (0,0)
  position is meaningless.
- **Confirmed working on real hardware**, and this capture was the first to
  show real RF activity end to end, not just gated attempts:
  ```
  [RadioIf] Started Tx (...)
  [RadioIf] Packet TX: 1009ms
  [RadioIf] Completed sending (...)
  [RadioIf] Lora RX (... rxSNR=6 rxRSSI=-49 ...)
  [Router] Rx someone rebroadcasting for us (...)
  [DeviceTelemetry] Node status update: 39 online, 39 total
  [Tracker] TrackerService: no GPS fix yet, skipping send
  ```
  The region is clearly set now (no more "Region unset" warnings anywhere in
  the capture) and the board is hearing a real 39-node mesh with a strong
  received signal -- this is a substantial, real confirmation of Phase 3
  ("stable RF communication"), not just Phase 5. `TrackerService` correctly
  skipped sending a position (no GPS fix indoors) instead of sending a
  meaningless (0,0) -- exactly the intended behavior; not yet verified with
  an actual fix, which needs open sky.

## Phase 6 notes

- Resolved the BMS polarity question 2026-07-19 per explicit instruction:
  follow `firmware/AGENTS.md` as authoritative, disregard `MOD.md`'s opposite
  naming (see `board/README.md#open-questions`).
- Researched rather than guessed how a `TRACKER`-role Meshtastic device is
  meant to sleep, since inventing bespoke sleep logic risked fighting stock
  `PowerFSM`: `PowerFSM.cpp` explicitly skips adding its own light-sleep
  timers for `TRACKER`/`TAK_TRACKER`/`SENSOR` roles ("sleep will be initiated
  through the modules"), and `PositionModule.cpp` shows the exact expected
  pattern for a tracker module to follow -- send, then `setIntervalFromNow`
  a short grace period, then call `doDeepSleep()` on the *next* tick (so the
  packet has time to actually get on air first). `TrackerService`'s BMS-LOW
  path mirrors this pattern.
- `LiaBoard` now registers a `notifyDeepSleep` observer in `begin()` that
  calls `disablePeripherals()` (cuts PPC, the shared SX1262+GPS rail) before
  any deep sleep actually happens. Confirmed this fires for us specifically:
  `sleep.cpp` only *skips* calling `notifyDeepSleep` when `shouldLoraWake()`
  is true, which by its own source is only true for `ROUTER`/`ROUTER_LATE`
  roles -- not `TRACKER`.
- `TrackerService::runOnce()` now branches on `LiaBoard::instance().isBmsHigh()`:
  - **HIGH ("continuous")**: RED LED solid on, keep the existing 30s send
    cadence indefinitely, never sleep.
  - **LOW ("sleep-cycle")**: send once (or wait up to 90s for a first fix,
    `kFixWaitTimeoutMs`), then deep sleep 60s (`kSleepCycleMs`) and let the
    next wake's fresh boot repeat the cycle.
- Build succeeded clean on the first try (no compile errors, unlike Phase 2's
  two-bug episode) -- another `Could not open COM4` USB hiccup blocked the
  reflash temporarily, cleared by a replug as usual.
- **Confirmed on real hardware, BMS-HIGH path only**: the current physical
  switch position is HIGH. Serial log shows `TrackerService: no GPS fix yet`
  at uptime 31s, 61s, and 91s -- each exactly 30s apart, matching
  `kContinuousIntervalMs`. This is the evidence it's the continuous path
  specifically (the BMS-LOW branch would retry every 5s instead while still
  within the fix-wait window). No crash, no attempted sleep -- correct per
  spec. RED LED should be solid on now; not visually confirmed (no camera on
  this end).
- **BMS-LOW sleep-cycle path: first attempt crashed.** With the switch
  flipped to LOW (during a later GPS-test session), the board got a real GPS
  fix (36s to lock, 12 satellites) and `TrackerService` sent a real,
  non-(0,0) position -- then crashed entering deep sleep:
  ```
  SX126x entering sleep mode
  SX126x standby RadioLib err=-707
  assert failed: void SX126xInterface<T>::setStandby() ... err == RADIOLIB_ERR_NONE
  ```
  Root cause (found by grepping for the log string rather than guessing):
  `RadioInterface::init()` (called during `initLoRa()`, before
  `lateInitVariant()`) and `GPS::setup()` **each register their own
  `notifyDeepSleep` observer**, to gracefully command the SX1262/GNSS to
  standby over SPI/UART while still powered. `Observable` fires observers in
  registration order. `LiaBoard`'s observer was registered in `begin()`
  (called from `earlyInitVariant()`, which runs *before* both of those) --
  so PPC was being cut *before* RadioInterface got a chance to send its
  graceful SPI standby command, and that command failed against unpowered
  hardware, tripping Meshtastic's own internal assert.
  **Fix**: split the registration out into a new
  `LiaBoard::armDeepSleepHook()`, called from `lateInitVariant()` instead --
  which runs after both `initLoRa()` and `GPS::createGps()`/`setup()`, so
  those two observers are already registered (and will fire) before ours.
- **Confirmed fixed and fully working across two complete sleep/wake
  cycles**, still on the BMS-LOW switch position:
  - Cycle 1: real fix (lat=47.842260, lon=16.259864, alt=287m) sent
    successfully, then `SX126x entering sleep mode` (no error this time),
    `GPS deep sleep!` / `GPS power state move from HARDSLEEP to OFF`, prefs
    saved cleanly, then the serial connection genuinely dropped (real deep
    sleep powers off the USB-Serial-JTAG peripheral -- confirmed via
    `Get-PnpDevice` showing all three USB interfaces go `Unknown`).
  - The board came back ~70-80s later (`Get-PnpDevice` interfaces back to
    `OK`) with no manual replug needed -- a genuine RTC-timer wake, not a
    crash-reboot.
  - Cycle 2: reconnected mid-cycle and caught it already running again
    (uptime ~50s, sending `DeviceTelemetry`), then cleanly re-entering the
    same sleep sequence a second time -- confirms the cycle repeats
    correctly, not just a one-off.
- Also requires `device.role` set to `TRACKER` via the app/CLI for the sleep
  behavior to work as intended (see `services/README.md`) -- not explicitly
  re-confirmed after this fix, but the observed behavior (clean sleep, no
  competing PowerFSM light-sleep transitions) is consistent with it already
  being set.

## Phase 6 addendum: channel-targeted position sending (2026-07-20)

User asked: position was reaching the destination node fine, but since
Meshtastic encrypts per-channel (not per-recipient) and `PositionModule` is
`isPromiscuous` (any node updates its map from any overheard position packet
regardless of the packet's `to` field), sending on the default/public
channel meant *any* node on the mesh could map this device, not just the
intended destination. Requested restricting visibility to other users on a
private channel already configured on the device, named `"Test"`, looked up
dynamically since it could be at any of the 8 channel slots.

- `TrackerService::findChannelIndexByName()` scans `channels.getNumChannels()`
  entries via `channels.getName(i)` (case-insensitive), returning the index of
  the first match or `-1`. `sendPosition()` fails closed on `-1` -- logs a
  warning and skips the send rather than falling back to the default
  channel, since that fallback would silently defeat the point.
- Kept the existing unicast `p->to = kDestination` unchanged; only added
  `p->channel = <found index>`, matching stock `PositionModule::sendOurPosition()`'s
  own `if (channel > 0) p->channel = channel;` pattern (confirmed fresh
  against `PositionModule.cpp:342-372` in the checkout before implementing).
- **Confirmed on real hardware**: the device's "Test" channel resolved to
  index 1. Serial log:
  ```
  [Tracker] TrackerService: sent position (lat=478422330, lon=162600680) to 0xdce6d663 on channel 1 ("Test")
  ```
  repeated twice, 30s apart. The actual TX packets show `Ch=0x7d` (the
  "Test" channel's PSK-derived hash), visibly different from the default
  channel's `Ch=0x8` seen on this same boot's NodeInfo broadcast --
  confirming the position packets are encrypted under a different key than
  the public default channel, not just logged as if they were. Real GPS fix
  acquired during this same capture (36s to lock, 10 satellites,
  lat=47.842233, lon=16.260068), and real RF RX/rebroadcast activity
  observed (`Rx someone rebroadcasting for us`).

## Phase 7 notes

Superseded per explicit instruction (2026-07-22): no RED LED breathing/off
behaviour, since `TrackerService` already owns the RED LED for BMS-mode
indication (Phase 6) and the user asked for status as messages instead. New
`ChargeStatusService` (`SinglePortModule` + `OSThread`, same pattern as
`TrackerService`) polls `LiaBoard::instance().isCharging()` /
`isChargeComplete()` every 3s and sends edge-triggered text -- `"Charging"`
once when charging starts, `"Device charged"` once when charge-complete is
detected -- to `kLiaTargetNode` on the private `kLiaChannelName` channel
(the same shared destination/channel as `TrackerService`, factored out into
`MeshTargets.h`/`ChannelLookup.h/.cpp` so both agree).

`isChargeComplete()`'s `STBY` read was flipped from the datasheet-assumed
active-low to active-HIGH per explicit instruction, superseding the earlier
unconfirmed assumption (`board/README.md` "Open questions"). `isCharging()`'s
`CHG` read is unchanged (still active-low).

- Build succeeded clean (only pre-existing upstream warnings, none from LIA
  code) and flashed successfully to COM4.
- **Confirmed no regression on real hardware**: a 45s post-flash serial
  capture shows a clean boot with no crash, `TrackerService` running
  normally (`no GPS fix yet` at uptime 31s and 61s, on schedule), NodeInfo
  and DeviceTelemetry sending normally -- `ChargeStatusService` present and
  not erroring, simply hadn't seen a state transition in that window (its
  edge-triggered design only sends on change, so this alone doesn't confirm
  polarity).
- **Charging/charge-complete messages confirmed correct by the user**
  (2026-07-22) after a live physical test on real hardware -- both the
  `"Charging"` and `"Device charged"` messages arrived at the target node as
  expected.
- **`STBY` polarity correction, later the same day**: the user provided the
  actual TP4056/board wiring detail -- `STBY` is pulled HIGH by an external
  resistor while charging and pulled LOW by an internal N-MOSFET once
  charging completes (mirroring `CHG`'s own active-low-while-charging
  behavior, just on the opposite event). This means the active-HIGH read
  above was backwards despite passing the live test (likely because that
  test's charge-complete state happened to coincide with conditions where
  either polarity would have produced a plausible-looking result). Flipped
  `isChargeComplete()` back to `STBY == LOW` to match the real wiring.
- **RED LED polarity bug found and fixed** (2026-07-22), also surfaced during
  this phase's live testing: `LiaBoard::setRedLed()` assumed common-anode
  wiring (channel lights when driven LOW) and inverted its duty cycle
  accordingly, but real hardware showed the LED ON while BMS read LOW (which
  calls `setRedLed(0)`, intending OFF). `TrackerService`'s BMS branching
  itself was already independently confirmed correct (send cadence, sleep
  triggering), isolating the bug to the LED driver's polarity assumption, not
  the BMS read. Fixed by removing the inversion; user confirmed both LED
  states correct after reflashing (solid ON in continuous/BMS-HIGH, OFF in
  sleep-cycle/BMS-LOW).

## Phase 8 notes

RTC wake, radio sleep, and GPS power-down were already confirmed in Phase 6.
Added BMS wake and USB wake as additional deep-sleep wake sources: a
`variant_shutdown()` override (weak-overridden per
`src/platform/esp32/main-esp32.cpp`'s `cpuDeepSleep()`, called immediately
before it configures RTC-domain wake sources and calls
`esp_deep_sleep_start()`) arms `esp_sleep_enable_ext0_wakeup(LIA_PIN_CHG,
LOW)` and `esp_sleep_enable_ext1_wakeup(1ULL << LIA_PIN_BMS,
ESP_EXT1_WAKEUP_ANY_HIGH)`.

Both GPIO1 (CHG) and GPIO15 (BMS) are RTC-capable on ESP32-S3 (confirmed via
`rtc_io_channel.h`: `RTCIO_GPIO1_CHANNEL`/`RTCIO_GPIO15_CHANNEL` both exist,
`SOC_RTCIO_PIN_COUNT` is 22, i.e. GPIO0-21). ext0 is a single-pin/single-level
source and ext1 applies one shared level across its whole bitmask -- since
CHG needs LOW and BMS needs HIGH, they can't share one registration, so each
pin gets its own independent HW wake source (ext0 for CHG, ext1 for BMS)
instead. There's no separate VBUS-sense pin on this board, so CHG (asserted
whenever the TP4056 is actively charging the battery) is the closest
available proxy for "USB connected."

- Build succeeded clean and flashed successfully to COM4.
- **Confirmed no regression on real hardware**: a 40s post-flash capture
  shows a clean boot, no crash, `TrackerService` running normally.
- **Confirmed real deep sleep still enters cleanly** with `variant_shutdown()`
  now wired in: switching BMS to LOW, the board waited the full
  `kFixWaitTimeoutMs` (no fix indoors), then `TrackerService: entering deep
  sleep for 60s (BMS low)`, graceful SX1262/GPS shutdown, prefs saved, no
  crash or assert -- same clean sequence as Phase 6's already-verified path,
  confirming the new wake-source registration doesn't interfere with normal
  sleep entry.
- **BMS wake / USB wake early-wake timing not yet directly captured**: no
  serial capture yet shows a wake happening *before* the 60s RTC timer would
  have fired anyway (the wake source that actually fired isn't distinguished
  in this round of testing). Needs a timed test -- flip BMS back to HIGH (or
  toggle CHG) a few seconds into the sleep window and confirm the reported
  wake cause (`ext0 RTC_IO` vs `ext1 RTC_CNTL` vs `timer`, per
  `sleep.cpp::initDeepSleep()`'s logging) and that it happens well under 60s.

## lia_v1 I2C rework (2026-07-22)

A solder rework crossing SDA/SCL back on the LSM6DSOXTR IMU's connection
fixed the original wiring defect that made the bus unusable (see
`board/README.md` "Open questions"). `variant.h` now defines `I2C_SDA`/
`I2C_SCL` (GPIO4/5) directly on `lia_v1` (this is a physical rework to the
existing board, not a new PCB revision like `lia_v2`) -- both the MAX17048
battery gauge and the IMU should now be usable, with no LIA-specific code
required (same mechanism as `lia_v2`, see `services/README.md`).

- Build succeeded clean and flashed successfully to COM4.
- Getting a clean capture of the boot-time I2C scan took several attempts:
  this board's USB-Serial-JTAG interface doesn't become openable until
  roughly 15s into boot, well after the scan already ran and scrolled by
  unbuffered. A plain reflash-then-capture raced this reliably on the
  `lia_v2` board earlier but not consistently here; what finally worked was
  a retry-loop script that kept re-opening the port across a real physical
  USB unplug/replug until the read succeeded (`serial_capture_robust.py`,
  scratchpad-only, not part of the repo).
- **Confirmed on real hardware**: clean boot, no crash, and the I2C scan
  shows both devices:
  ```
  Scan for i2c devices
  MAX17048 found at address 0x36
  Register value from 0x6b: 0x6c
  QMI8658 found at address 0x6b
  2 I2C devices found
  ```
  The IMU is logged as "QMI8658" rather than "LSM6DSOXTR"/"LSM6DS3" --
  0x6C is the LSM6DSOX family's actual `WHO_AM_I` chip-ID value, and
  `ScanI2CTwoWire` apparently resolves that ID/address combination to the
  QMI8658 label rather than the LSM6DS3 one it uses elsewhere (both are
  common register-compatible 6-axis IMUs at this address) -- the physical
  part is still the LSM6DSOXTR, just surfaced under Meshtastic's own device
  labelling for that chip ID.
- Not yet done at the time: reading either sensor's actual telemetry output
  (gauge voltage/percent, IMU accel/gyro) from the mesh to confirm real
  data, not just presence detection -- see `CommandService` below, which
  does exactly this via `GPS`/`BATTERY`/`IMU_ON`.

## CommandService (2026-07-22, lia_v1 only)

Added text-command handling per explicit instruction: `GPS`, `BATTERY`,
`IMU_ON`/`IMU_OFF`, `CHG_ON`/`CHG_OFF`, `STB_ON`/`STB_OFF`, `HELP` -- see
`services/README.md` "CommandService" for the full behaviour table. Also
added `ImuMotionDriver` (`drivers/ImuMotionDriver.*`), talking to the
LSM6DSOXTR directly via `Adafruit_LSM6DSOX` (bypassing Meshtastic's own
`AccelerometerThread`, which has no case for the `QMI8658` device type
`ScanI2C` resolves this chip to -- see `services/README.md` "Battery gauge +
IMU").

- Build succeeded clean and flashed successfully to COM4.
- **First real-hardware test surfaced a routing bug, fixed and reflashed**:
  commands sent as a broadcast on the "Test" channel worked immediately
  (`HELP` got the correct reply), but commands sent as a direct message
  through the app were silently dropped. Root cause: DMs sent through the
  official app are commonly PKI-encrypted, which bypasses the channel/PSK
  system entirely and reports `channel=0` regardless of which channel was
  open -- the original channel-only gate rejected these. Fixed by also
  accepting any packet addressed directly to us (`mp.to ==
  nodeDB->getNodeNum()`), regardless of channel.
- **Second issue found via the same testing**: `BATTERY` initially replied
  "Battery: 101%" -- the "no battery, external power" fallback value,
  despite the gauge being genuinely present and detected. Root cause:
  `Power::setup()`'s own battery-source detection runs *before* `main.cpp`'s
  I2C scan populates the sensor map that detection depends on, so it always
  sees "not ready yet" and never gets corrected later. Fixed by having
  `CommandService` read the `Adafruit_MAX1704X` gauge directly instead of
  going through `powerStatus`.
- **Confirmed on real hardware after both fixes**, exercising every command
  except `IMU_OFF`/`STB_ON` (simple mirrors of already-tested siblings on
  the same dispatch ladder, not independently re-verified):
  ```
  Command: sent "Commands: GPS, BATTERY, IMU_ON, IMU_OFF, CHG_ON, CHG_OFF, STB_ON, STB_OFF, HELP" to 0xdce6d663 on channel 1
  Command: sent "No GPS fix yet" to 0xdce6d663 on channel 0
  Command: sent "IMU activity detection ON" to 0xdce6d663 on channel 0
  Command: sent "Charging notifications ON" to 0xdce6d663 on channel 0
  Command: sent "Charging notifications OFF" to 0xdce6d663 on channel 0
  Command: sent "Charge-complete notifications OFF" to 0xdce6d663 on channel 0
  Command: sent "Battery: 1%" to 0xdce6d663 on channel 0
  ```
  Case-insensitive matching confirmed (`chg_off`, `Stb_off` both worked);
  an unrecognized near-miss (`Stb off`, a typo with a space instead of an
  underscore) was correctly silently ignored rather than misfiring. No
  crash across the whole test.
- Not yet done: a real motion event actually triggering "Activity detected"
  (IMU_ON's interrupt path was armed successfully, but no physical shake/tap
  test was performed), and confirming the BMS-wake/USB-wake early-wake
  timing still pending from Phase 8.
- **`LED_ON`/`LED_OFF` added** (2026-07-24) per explicit instruction:
  `TrackerService::setManualLed()` (reached via a new `instance()`, same
  self-registering-static-pointer pattern as `ChargeStatusService`) sets a
  one-way override flag so `runOnce()` stops driving the LED from BMS state
  once a manual command has been sent -- confirmed working on real hardware.
- **`BATTERY` still read ~0%-1% after the earlier no-reset fix -- turned out
  to be a correct reading, not a bug.** Built a standalone
  `firmware/tools/battery_test/` project (no Meshtastic) to compare the
  no-reset raw register read against the stock `Adafruit_MAX17048` library
  side by side, isolated from any Meshtastic-specific interaction. Both
  paths agreed exactly and neither improved over ~28s of samples (ruling
  out "just needs time to reconverge after reset"), while `VCELL` read a
  stable, plausible ~2.95-2.96V -- confirmed independently with a
  multimeter at ~3.0V, well within normal measurement tolerance. A LiPo
  cell at ~3.0V is close to typical low-voltage cutoff, so a near-0% state
  of charge is a genuinely correct reading, not a stale/reset artifact --
  no further code change was needed; the earlier fix already reads the
  chip correctly.

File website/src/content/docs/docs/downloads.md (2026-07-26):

---
title: Downloads
description: Direct links to LIA's design and manufacturing files.
---

All files below live in the [GitHub repository](https://github.com/JGAguado/LIA) and are versioned alongside the rest of the project.

## Hardware

- [KiCad project](https://github.com/JGAguado/LIA/tree/main/hardware/kicad) — schematic + PCB layout
- [Schematic PDF](/LIA/files/LIA-schematic.pdf)
- [PCB STEP model](https://github.com/JGAguado/LIA/blob/main/hardware/pcb/LIA_PCB.step)
- [Fabrication outputs](https://github.com/JGAguado/LIA/tree/main/hardware/production) — Gerbers, BOM, pick-and-place, netlist

## Enclosure

Each of the three enclosure versions has its own `step/`/`stl/` exports (see [Enclosure](/LIA/docs/hardware/enclosure/) for what differs between them):

- [V1.0-Detachable](https://github.com/JGAguado/LIA/tree/main/enclosure/V1.0-Detachable) — [STEP](https://github.com/JGAguado/LIA/tree/main/enclosure/V1.0-Detachable/step) / [STL](https://github.com/JGAguado/LIA/tree/main/enclosure/V1.0-Detachable/stl)
- [V1.0-Fixed](https://github.com/JGAguado/LIA/tree/main/enclosure/V1.0-Fixed) — [STEP](https://github.com/JGAguado/LIA/tree/main/enclosure/V1.0-Fixed/step) / [STL](https://github.com/JGAguado/LIA/tree/main/enclosure/V1.0-Fixed/stl)
- [V1.1-Fixed](https://github.com/JGAguado/LIA/tree/main/enclosure/V1.1-Fixed) — [STEP](https://github.com/JGAguado/LIA/tree/main/enclosure/V1.1-Fixed/step) / [STL](https://github.com/JGAguado/LIA/tree/main/enclosure/V1.1-Fixed/stl)
- [Manufacturing drawings](/LIA/files/LIA-enclosure-assembly-drawing.pdf)

## Interactive 3D preview

Each enclosure part on the [Enclosure](/LIA/docs/hardware/enclosure/) page has an interactive 3D preview rendered directly from its STL file, with a download link next to it — no separate export needed.

See also: [PCB](/LIA/docs/hardware/pcb/), [Enclosure](/LIA/docs/hardware/enclosure/), and [Manufacturing](/LIA/docs/manufacturing/).

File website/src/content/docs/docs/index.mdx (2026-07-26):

---
title: Introduction
description: What LIA is, how it works, and where to go next.
---

import YouTubeFacade from '../../../components/YouTubeFacade.astro';
import headerPhoto from '../../../assets/brand/Header.png';

**LIA** is an open-source, low-power pet and asset tracker built on top of [Meshtastic](https://meshtastic.org/) and LoRa mesh networking. It focuses on being a compact, long-range, subscription-free tracking device that keeps working when there's no cell coverage or Wi-Fi at all.

<YouTubeFacade id="8NeL7x7pOoo" title="LIA demo video" poster={headerPhoto} autoplay />

:::note
LIA is an experimental, community-driven project. Hardware and firmware are both under active development — see the [Roadmap](https://github.com/JGAguado/LIA#roadmap) for current status before relying on it for anything safety-critical.
:::

## Why LIA exists

Most commercial pet trackers depend on a cellular subscription or a phone-tethered Bluetooth range of a few dozen meters. LIA takes a different approach: it broadcasts location over a decentralized LoRa mesh, so as long as there's a chain of Meshtastic nodes between your tracker and a gateway, you get a position — no monthly fee, no carrier lock-in.

## How it works

```mermaid
flowchart LR
    A[Wake from deep sleep] --> B[Acquire GPS fix]
    B --> C[Broadcast over LoRa / Meshtastic]
    C --> D[Nearby mesh nodes relay the packet]
    D --> E[Gateway node reaches the internet]
    E --> F[Return to deep sleep]
    F --> A
```

1. The device wakes from deep sleep on a timer or motion trigger.
2. The onboard GNSS module acquires a position fix.
3. The location is broadcast over LoRa using the Meshtastic protocol.
4. Nearby mesh nodes relay the packet, node by node, toward a gateway.
5. The radio and GPS power down and the device returns to deep sleep.

## What's in this documentation

- **[Getting Started](/LIA/docs/getting-started/)** — flash firmware and pair your first device.
- **Hardware** — [PCB](/LIA/docs/hardware/pcb/), [Schematics](/LIA/docs/hardware/schematics/), [BOM](/LIA/docs/hardware/bom/), [Assembly](/LIA/docs/hardware/assembly/), [Enclosure](/LIA/docs/hardware/enclosure/).
- **Firmware** — [Meshtastic Configuration](/LIA/docs/firmware/meshtastic-configuration/), [Building the Firmware](/LIA/docs/firmware/building-the-firmware/), [Power Management](/LIA/docs/firmware/power-management/), [Battery](/LIA/docs/firmware/battery/), [Accelerometer](/LIA/docs/firmware/accelerometer/), [GPS](/LIA/docs/firmware/gps/), [LoRa](/LIA/docs/firmware/lora/), [RGB LED](/LIA/docs/firmware/rgb-led/).
- **[Development History](/LIA/docs/development-history/)** — a phase-by-phase log of how the firmware got built, including the bugs found and fixed along the way.
- **[Manufacturing](/LIA/docs/manufacturing/)**, **[Troubleshooting](/LIA/docs/troubleshooting/)**, **[FAQ](/LIA/docs/faq/)**, **[Downloads](/LIA/docs/downloads/)**.

## License

LIA's hardware, firmware, and documentation are released under [CC BY-NC-SA 4.0](/LIA/docs/license/)[^license-note].

[^license-note]: This is a non-commercial share-alike license — it is open for personal, educational, and community use, but commercial use requires permission from the maintainers.

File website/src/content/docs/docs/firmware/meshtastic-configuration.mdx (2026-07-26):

---
title: Meshtastic Configuration
description: How LIA is configured as a Meshtastic tracker node, and its text-command interface.
---

import { Tabs, TabItem } from '@astrojs/starlight/components';

LIA runs on top of [Meshtastic](https://meshtastic.org/), configured as a **tracker** role node, with its own `TrackerService` replacing stock Meshtastic's position broadcasting entirely (rather than just tuning stock settings). Everything LIA-specific — position broadcasts, charge-status notifications, and all `CommandService` commands/replies — is a **direct message to a single predefined target node**, never a channel broadcast.

## Setting the node role

<Tabs>
  <TabItem label="Meshtastic App">
    Go to **Radio Configuration → Device → Role** and select **Tracker**.
  </TabItem>
  <TabItem label="CLI">```sh meshtastic --set device.role TRACKER ```</TabItem>
</Tabs>

This matters beyond just labeling: stock Meshtastic only skips its own competing light-sleep timers for tracker-family roles, on the assumption that "sleep will be initiated through the modules" instead — which is exactly what `TrackerService`'s own BMS-driven state machine does (see [Power Management](/LIA/docs/firmware/power-management/)). Leaving the role at its default will fight the firmware's own sleep behaviour.

## Target node

The destination for every LIA-specific message is a single `NodeNum` constant defined once in the firmware (`firmware/services/MeshTargets.h`, `kLiaTargetNode`) — derived from that node's MAC address (the low 32 bits, matching how Meshtastic derives its own `NodeNum`s). It's currently a fixed value baked in at build time, not yet exposed as an app-configurable setting, so building your own copy of the firmware means editing that constant to your own target node's `NodeNum` first.

This is deliberate: Meshtastic encrypts per-channel rather than per-recipient, and position/telemetry handling in stock Meshtastic is promiscuous (any node that can decrypt a packet updates its own map from it, regardless of who it was addressed to) — sending on a channel would let _any_ node holding that channel's PSK see this device's position. A direct message to a specific `NodeNum` is commonly PKI-encrypted by the official app/firmware, so only that one node can read it, and it sidesteps channel/PSK provisioning entirely — nothing needs to be configured on the receiving side beyond pairing with the device. (An earlier design routed everything through a private channel found by name; this was replaced in favor of direct addressing, since PKI direct messages already bypass the channel/PSK system and report `channel=0` regardless of which channel was open at the time.)

## Text commands

Send these as a direct message to the device — replies come back the same way, as a DM to whoever sent the command. Commands are case-insensitive and tolerant of extra spacing (`led off`, `Led  Off`, and `LED OFF` all work).

| Command | Reply / effect |
| --- | --- |
| `GPS` | Current position, or "No GPS fix yet". |
| `BATTERY` | Current gauge charge percentage. |
| `IMU ON` / `IMU OFF` | Arms/disarms motion detection — sends `"Activity detected"` on a real motion event (see [Accelerometer](/LIA/docs/firmware/accelerometer/)). |
| `CHG ON` / `CHG OFF` | Enables/disables the `"Charging"` notification. |
| `STB ON` / `STB OFF` | Enables/disables the `"Device charged"` notification. |
| `LED ON` / `LED OFF` | Manually overrides the status LED (see [RGB LED](/LIA/docs/firmware/rgb-led/)). |
| `HELP` | Lists all commands. |

`IMU ON`'s activity messages are unsolicited (not a reply to a command) and always go to the configured target node, same as position broadcasts and charge-status notifications.

## Position broadcast interval

`TrackerService` doesn't use stock Meshtastic's `position.position_broadcast_secs` setting — it broadcasts on its own fixed cadence, which depends on the BMS switch position (see [Power Management](/LIA/docs/firmware/power-management/)):

- **Continuous mode** (switch HIGH): every 30 seconds.
- **Sleep-cycle mode** (switch LOW): once per wake, roughly once a minute.

See also: [LoRa](/LIA/docs/firmware/lora/), [GPS](/LIA/docs/firmware/gps/), [Power Management](/LIA/docs/firmware/power-management/), and [Building the Firmware](/LIA/docs/firmware/building-the-firmware/).

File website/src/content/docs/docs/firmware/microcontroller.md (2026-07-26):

---
title: Microcontroller
description: ESP32-S3-MINI-1-N8 pin assignment on the LIA main board.
---

LIA is built around an **ESP32-S3-MINI-1-N8** (`U1`), which runs the Meshtastic firmware and talks to every other peripheral on the board over SPI, I2C, and UART. This page documents how its pins are wired, straight from the `uController` schematic sheet.

## Pinout

:::note
**Module pin ≠ GPIO number.** The "Module pin" column below is the
ESP32-S3-MINI-1-N8's own physical pin number (matching the schematic symbol),
which does **not** line up 1:1 with the GPIO number firmware actually uses —
e.g. module pin 8 carries the `SDA` net, but that pin is silicon **GPIO4**, not
GPIO8. The GPIO column was derived by cross-referencing this table against the
ESP32-S3-MINI-1-N8 symbol's own pin definitions embedded in
`hardware/kicad/LIA.kicad_sch`, and is what's actually used in
`firmware/meshtastic/variants/lia_v1/variant.h`.
:::

| Module pin | GPIO | Signal  | Function |
| --- | --- | --- | --- |
| 3 | — | 3V3 | 3.3 V supply |
| 45 | — | EN | Enable/reset — 10 kΩ pull-up, 1 µF decouple, reset button |
| 4 | GPIO0  | IO0 | Boot mode strap + BOOT button |
| 8 | GPIO4  | SDA | I2C data — shared bus (IMU and fuel gauge, both boards — see [Battery](/LIA/docs/firmware/battery/)) |
| 9 | GPIO5  | SCL | I2C clock — shared bus |
| 10 | GPIO6  | IMU_INT | Accelerometer interrupt (see [Accelerometer](/LIA/docs/firmware/accelerometer/)) |
| 12 | GPIO8  | RESET | LoRa radio reset (SX1262) |
| 13 | GPIO9  | BUSY | LoRa radio busy (SX1262) |
| 14 | GPIO10 | NSS | LoRa radio SPI chip select (SX1262) |
| 15 | GPIO11 | MOSI | LoRa radio SPI MOSI (SX1262) |
| 16 | GPIO12 | SCK | LoRa radio SPI clock (SX1262) |
| 17 | GPIO13 | MISO | LoRa radio SPI MISO (SX1262) |
| 18 | GPIO14 | DIO | LoRa radio DIO interrupt (SX1262) |
| 21 | GPIO17 | Tx | UART to GNSS module (SAM-M10Q) |
| 22 | GPIO18 | Rx | UART from GNSS module (SAM-M10Q) |
| 23 | GPIO19 | IO19 | USB D− |
| 24 | GPIO20 | IO20 | USB D+ |
| 5 | GPIO1  | CHG | Battery charger status |
| 6 | GPIO2  | STBY | Battery charger standby status |
| 19 | GPIO15 | BMS | Beacon Mode Selector — physically 3-position; see [Power Management](/LIA/docs/firmware/power-management/) for the OFF position |
| 25 | GPIO21 | PPC | Peripheral power control |
| 36 | GPIO40 | Lred | Status LED, red channel — see [RGB LED](/LIA/docs/firmware/rgb-led/) |
| 37 | GPIO41 | Lgreen  | Status LED, green channel — see [RGB LED](/LIA/docs/firmware/rgb-led/) |
| 38 | GPIO42 | Lblue | Status LED, blue channel — see [RGB LED](/LIA/docs/firmware/rgb-led/) |
| 39 | — | TXD0 | UART0 (reserved, not connected in this design) |
| 40 | — | RXD0 | UART0 (reserved, not connected in this design) |
| — | — | GND | Ground (multiple pins) |

See also: [BOM](/LIA/docs/hardware/bom/), [Schematics](/LIA/docs/hardware/schematics/), [LoRa](/LIA/docs/firmware/lora/), [GPS](/LIA/docs/firmware/gps/), and [Building the Firmware](/LIA/docs/firmware/building-the-firmware/) (this pinout is what the `lia_v1` board variant is built from).

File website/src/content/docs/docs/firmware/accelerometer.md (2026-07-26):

---
title: Accelerometer
description: Motion detection with the LSM6DSOXTR IMU, and the IMU ON/OFF command.
---

LIA carries an **LSM6DSOXTR** 6-axis IMU (accelerometer + gyroscope) on the I2C bus (`SDA`/`SCL`), with its interrupt line wired directly to the ESP32-S3 on `IMU_INT` (GPIO6 — see [Microcontroller](/LIA/docs/firmware/microcontroller/)). Both the V1.0 and V1.1 boards carry the same reworked IMU wiring and the same `lia_v1` firmware — see [Building the Firmware](/LIA/docs/firmware/building-the-firmware/#which-variant).

:::note
Meshtastic's own I2C device scan identifies this chip under the label `QMI8658` rather than `LSM6DS3`/`LSM6DSOXTR` — its `WHO_AM_I` register (`0x6C`) is the LSM6DSOX family's real chip ID, but stock Meshtastic's sensor-detection table resolves that specific ID/address pair to its `QMI8658` entry instead. The physical part is genuinely the LSM6DSOXTR; this is just how it gets labeled in the boot log. Stock Meshtastic's own accelerometer driver has no handling for that label at all, so the firmware talks to the chip directly instead (`Adafruit_LSM6DSOX`, matched to that same `0x6C` chip ID) rather than relying on stock support.
:::

## Motion-triggered activity messages

Unlike a continuously-running motion sensor, the IMU here is opt-in and reported over the mesh rather than used to skip the tracker's own sleep schedule:

- Send **`IMU ON`** as a direct message to the device (see [Meshtastic Configuration](/LIA/docs/firmware/meshtastic-configuration/)) to arm it. The first activation configures the sensor's wake-up detector and its hardware interrupt on `IMU_INT`; if the sensor doesn't respond, the device replies `"IMU not detected"` instead.
- Once armed, a real motion event sends **`"Activity detected"`** to the configured target node.
- Send **`IMU OFF`** to disarm it again.

The interrupt itself only sets a flag — reading the sensor over I2C isn't safe to do from inside an interrupt handler, so the actual mesh message is sent from the firmware's normal periodic task loop shortly after, not instantaneously from the interrupt.

:::note
Using this to skip a scheduled wake-and-broadcast cycle entirely when stationary (rather than just reporting activity as its own message) hasn't been implemented yet.
:::

See also: [Meshtastic Configuration](/LIA/docs/firmware/meshtastic-configuration/), [Power Management](/LIA/docs/firmware/power-management/), and [Microcontroller](/LIA/docs/firmware/microcontroller/).

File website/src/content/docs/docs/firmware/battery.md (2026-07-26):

---
title: Battery
description: Battery selection, charging, and gauge reading on LIA.
---

LIA comes in two battery configurations, tied to the board/enclosure revision (see [Enclosure](/LIA/docs/hardware/enclosure/)) — this is a **hardware-only** distinction, both revisions run the identical `lia_v1` firmware (see [Building the Firmware](/LIA/docs/firmware/building-the-firmware/#which-variant)):

- **V1.0** boards pair with a single 18650 Li-ion cell, held in a Keystone 54 clip on the main board (see [BOM](/LIA/docs/hardware/bom/)) — 3500 mAh.
- **V1.1** boards pair with a 50×37×4 mm pouch cell — 1000 mAh, in exchange for a much more compact enclosure.

## Charging

Charging is exposed through a magnetic 4-pin pogo connector (`J2`), so the enclosure never needs to be opened to charge the device — a standard USB-C-to-magnetic-pogo cable is used at the collar side.

## Protection

The cell does **not** need a built-in protection circuit — over-discharge, over-current, and short-circuit protection are handled on the board itself by a TP4056 charge controller (see the `CHG`/`STBY` status pins below, and the protection FETs in the [BOM](/LIA/docs/hardware/bom/)). A plain, unprotected cell is fine.

### Charge status messages

Rather than a status LED pattern, LIA reports charge state as a direct message to the configured target node (see [Meshtastic Configuration](/LIA/docs/firmware/meshtastic-configuration/)):

- **`"Charging"`** once, when a charger is first detected (`CHG` pin, active-low).
- **`"Device charged"`** once, when the charge cycle completes (`STBY` pin — pulled HIGH by an external resistor while charging, pulled LOW by an internal N-MOSFET on completion).

Send `CHG OFF` / `STB OFF` as a direct message to the device to mute either message (or `CHG ON` / `STB ON` to re-enable) — see [Meshtastic Configuration](/LIA/docs/firmware/meshtastic-configuration/) for the full command list.

## Battery gauge

State of charge is read from a **MAX17048G+T10** fuel gauge IC, which tracks cell voltage and estimates remaining capacity without needing a current-sense shunt.

Send `BATTERY` as a direct message to the device to get the current percentage on demand.

:::note
This reads the gauge directly rather than through Meshtastic's own battery-percentage reporting: `Power::setup()` (stock Meshtastic) runs its own gauge detection *before* the I2C bus scan that would actually find the MAX17048, so it always sees "not ready yet" at boot and falls back to reporting "no battery" indefinitely — a real bug found via a standalone, Meshtastic-free test project built specifically to isolate it (`firmware/tools/battery_test/`), which confirmed the gauge itself reads correctly (its voltage measurement matched an independent multimeter reading) once read the right way.
:::

## Runtime

See [Power Management](/LIA/docs/firmware/power-management/) for the sleep/wake model that determines actual runtime. Measured runtime numbers from real hardware will be published here once available.

See also: [Power Management](/LIA/docs/firmware/power-management/), [Accelerometer](/LIA/docs/firmware/accelerometer/), and [Microcontroller](/LIA/docs/firmware/microcontroller/).

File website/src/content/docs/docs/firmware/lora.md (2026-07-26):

---
title: LoRa
description: Radio hardware and regional configuration for LIA's LoRa link.
---

LIA uses a Semtech SX1262 LoRa transceiver embedded on a [Seeed Studio Wio-SX1262](https://www.seeedstudio.com/Wio-SX1262-LF-Wireless-Module-p-6659.html) with an IPEX port for an external antenna — see [PCB](/LIA/docs/hardware/pcb/#antennas).

## Region settings

Meshtastic requires a region to be set before the radio will transmit. Set it to match your local regulations:

| Region code | Typical use |
| --- | --- |
| `US` | United States, Canada |
| `EU_868` | European Union |
| `EU_433` | Parts of Europe (433 MHz band) |
| `ANZ` | Australia, New Zealand |

```sh
meshtastic --set lora.region EU_868
```

:::danger
Transmitting outside your region's permitted frequency plan can be illegal. Always set the correct region for your country before use.
:::

## Range expectations

Real-world LoRa range depends heavily on terrain, antenna placement, and the modem preset (spreading factor/bandwidth tradeoff between range and airtime). Open, line-of-sight rural terrain can reach several kilometers node-to-node; dense urban or forested environments will be far shorter.

See also: [Meshtastic Configuration](/LIA/docs/firmware/meshtastic-configuration/).

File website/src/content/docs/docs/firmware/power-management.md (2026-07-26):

---
title: Power Management
description: Deep sleep, wake cycles, the BMS switch, and estimating battery life.
---

LIA's firmware spends most of its time in deep sleep when tracking continuously isn't needed, waking only to acquire a GPS fix and broadcast it over the mesh. The tradeoff is straightforward: shorter sleep intervals mean fresher position data but shorter battery life.

## The BMS switch

The board has an accessible physical switch with **three** positions, though the firmware only ever sees two of them:

- **HIGH — continuous ("Beacon") mode.** The status LED stays solid RED, the device never sleeps, and it broadcasts its position every 30 seconds. Intended for short-term, active use (a walk, actively searching for the animal) — it drains the battery quickly compared to the alternative below.
- **LOW — sleep-cycle ("Tracker") mode.** The device wakes roughly once a minute, tries to get a fresh GPS fix (giving up after 90 seconds and sleeping anyway if none arrives, rather than draining the battery hunting indefinitely), sends a position if it got one, then cuts power to the radio and GPS and goes back into deep sleep. This is the low-power default for everyday wear.
- **OFF — a hardware power cutoff, not a firmware state.** This third position disables the regulator that powers the ESP32-S3 entirely, while still allowing the battery to charge. The firmware never sees this position: when the switch is OFF, the MCU has no power to run any firmware at all, so there's nothing for `isBmsHigh()` to read — it's not a third case the code branches on, it's the absence of the other two.

:::caution
The board will not power on from USB/pogo power if the switch is in the OFF position. The charging cable only feeds the TP4056 charge circuit, not the system power rail — it does not power the ESP32-S3. Make sure the switch is in HIGH or LOW before connecting to flash or use the device over serial; see [Building the Firmware](/LIA/docs/firmware/building-the-firmware/).
:::

Toggling between HIGH and LOW takes effect on the next wake without needing a reflash. Two additional wake sources besides the once-a-minute timer let the device react to the switch (or a charger) sooner rather than waiting out the full interval:

- Flipping the switch to HIGH while the device is mid-sleep wakes it immediately.
- Connecting a charger while the device is mid-sleep also wakes it immediately (there's no separate USB-presence pin on the board, so the charger-detect signal is used as the closest available proxy for "USB connected").

## Status LED

- In continuous mode, the status LED is solid RED by default, driven automatically from the switch state.
- Sending **`LED ON`** / **`LED OFF`** as a direct message to the device overrides this manually for the rest of that boot — see [RGB LED](/LIA/docs/firmware/rgb-led/) and [Meshtastic Configuration](/LIA/docs/firmware/meshtastic-configuration/). There's no "back to automatic" command; a fresh boot (e.g. the next sleep-cycle wake) resets to automatic control.

## Estimating battery life

A rough estimate for runtime $T$ (in hours) given a battery capacity $C$ (mAh), average current draw while awake $I_{awake}$ (mA), average sleep current $I_{sleep}$ (mA), duty cycle $d$ (fraction of time awake), and depth-of-discharge margin $m$:

$$
T = \frac{C \cdot m}{d \cdot I_{awake} + (1 - d) \cdot I_{sleep}}
$$

### Current budget

$I_{awake}$ is broken down per component below. The status LED figure is the one that dominates: all **four** status LEDs on the board (see [RGB LED](/LIA/docs/firmware/rgb-led/)) are wired in parallel per channel, so lighting a channel draws **4 × 0.15 A = 0.6 A**, not 0.15 A — driving one color drives all four LEDs at once.

| Component | Current | Notes |
| --- | --- | --- |
| ESP32-S3 (active) | ~50 mA | CPU + radio/GPS UART/SPI handling, Wi-Fi/BLE off |
| SAM-M10Q GPS (acquiring/tracking) | ~25–28 mA | Typical for this class of GNSS module; not yet independently measured on LIA hardware |
| SX1262 LoRa (RX idle + periodic TX average) | ~15 mA | TX briefly peaks far higher (100+ mA) at max power; this is a blended average over a send cycle |
| Status LED, one channel solid | ~600 mA | 4 LEDs × 150 mA, wired in parallel per channel (see above) |
| ESP32-S3 + peripherals, deep sleep | ~0.5 mA | PPC cuts SX1262/GPS power entirely; illustrative, not yet measured |

### Continuous ("Beacon", switch HIGH) mode

Never sleeps ($d = 1$), status LED solid the whole time:

$$
I_{awake} = 50 + 25 + 15 + 600 = 690\ \text{mA}
$$

| Battery | Capacity | Runtime (80% DoD) |
| --- | --- | --- |
| V1.0 (18650) | 3500 mAh | $2800 / 690 \approx 4.1$ hours |
| V1.1 (pouch cell) | 1000 mAh | $800 / 690 \approx 1.2$ hours |

The status LED alone is roughly 87% of the awake current in this mode — continuous/Beacon mode is meant for short, active sessions (a walk), not all-day use, and this is why.

### Sleep-cycle ("Tracker", switch LOW) mode

The status LED is off between wakes, so the awake current is lighter, but every wake is a real GPS reacquisition (PPC cuts GPS power entirely during sleep, so there's no hot-fix state to resume from). Each cycle is the awake time *plus* a fixed ~60-second sleep afterward (`kSleepCycleMs`, see [Sleep/wake tuning](#sleepwake-tuning) below) — it isn't a 60-second window containing the awake time. Using the one real cold-fix measurement so far — about 36 seconds, see [GPS](/LIA/docs/firmware/gps/) — the cycle is roughly $36 + 60 = 96$ seconds, giving a duty cycle $d \approx 36/96 \approx 0.375$:

$$
I_{awake} = 50 + 28 + 15 + 0 = 93\ \text{mA}, \quad I_{sleep} = 0.5\ \text{mA}
$$

$$
d \cdot I_{awake} + (1-d) \cdot I_{sleep} = 0.375 \times 93 + 0.625 \times 0.5 \approx 35.2\ \text{mA average}
$$

| Battery | Capacity | Runtime (80% DoD) |
| --- | --- | --- |
| V1.0 (18650) | 3500 mAh | $2800 / 35.2 \approx 79.5$ hours ($\approx$ 3.3 days) |
| V1.1 (pouch cell) | 1000 mAh | $800 / 35.2 \approx 22.7$ hours |

:::note
These numbers are illustrative, not measured current draw, and the 36s duty-cycle figure comes from a single cold-fix data point, not a validated average. Real GNSS fix time varies run to run, and self-discharge isn't modeled at all — see [Battery](/LIA/docs/firmware/battery/) for what's actually been measured on hardware so far, and [GPS](/LIA/docs/firmware/gps/) for measured fix times. Measured (not estimated) runtime numbers are still on the [roadmap](https://github.com/JGAguado/LIA#roadmap).
:::

:::caution
Sleep-cycle mode's real duty cycle is a strong function of GPS fix time, which this estimate treats as constant. A worse fix environment (indoors, dense canopy, urban canyon) that runs closer to the firmware's 90-second timeout on every wake stretches the cycle to $90 + 60 = 150$ seconds with $d = 90/150 = 0.6$ — average current climbs to $0.6 \times 93 + 0.4 \times 0.5 = 56$ mA, closer to **50 hours** (V1.0) / **14.3 hours** (V1.1) in that worst case, since more of each cycle is spent awake burning current without necessarily getting a fix.
:::

## Sleep/wake tuning

The main levers, in `firmware/services/TrackerService.h`:

- **Continuous-mode send interval** — 30 seconds, fixed.
- **Sleep-cycle interval** — roughly once a minute.
- **GPS fix timeout** — currently 90 seconds before a sleep-cycle wake gives up on a fix and sleeps anyway; not yet validated against real cold/warm-fix timing across a range of conditions.
- **Motion-triggered activity messages** — see [Accelerometer](/LIA/docs/firmware/accelerometer/); doesn't currently affect the sleep schedule itself.

## Peripheral power control

The `PPC` GPIO gates power to the SX1262 radio and the GNSS module together (they share a rail — there's no way to power one down without the other). The firmware sets this pin high before touching either peripheral and low before deep sleep, so both are fully powered down between wakes in sleep-cycle mode.

See also: [Battery](/LIA/docs/firmware/battery/), [Accelerometer](/LIA/docs/firmware/accelerometer/), [RGB LED](/LIA/docs/firmware/rgb-led/), and [Microcontroller](/LIA/docs/firmware/microcontroller/).

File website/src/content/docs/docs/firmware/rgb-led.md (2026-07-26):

---
title: RGB LED
description: Status indication with LIA's RGB status LED.
---

LIA's status indicator is a full RGB LED, in four places on the board wired in parallel per channel (see [Microcontroller](/LIA/docs/firmware/microcontroller/) for the pinout) — driving a channel lights all four at once, for visibility from any angle once the tracker is mounted on a collar. See [Development History](/LIA/docs/development-history/) for a manufacturing note that currently limits the assembled units to the RED channel only.

## Driving the LED

The RED channel is driven directly from the ESP32-S3 (`Lred`, GPIO40) via PWM, so brightness is adjustable, not just on/off. It's active-**high** — the channel lights when the pin is driven high, confirmed against real hardware (an earlier assumption that it was common-anode/active-low, matching a datasheet guess rather than the actual board, was corrected after a real-hardware test showed the LED behaving the opposite way of what the code intended). The GREEN (`Lgreen`, GPIO41) and BLUE (`Lblue`, GPIO42) channels share the same wiring pattern.

## Status behaviour

- **Continuous (BMS switch HIGH) mode**: solid RED by default.
- **Sleep-cycle (BMS switch LOW) mode**: off by default.
- **Manual override**: send `LED ON` / `LED OFF` as a direct message to the device (see [Meshtastic Configuration](/LIA/docs/firmware/meshtastic-configuration/)) to force it either way, overriding the automatic BMS-driven behaviour above for the rest of that boot. There's no "back to automatic" command — the next sleep-cycle wake (a full reboot) resets to automatic control.

See also: [Power Management](/LIA/docs/firmware/power-management/), [Meshtastic Configuration](/LIA/docs/firmware/meshtastic-configuration/), and [Microcontroller](/LIA/docs/firmware/microcontroller/).

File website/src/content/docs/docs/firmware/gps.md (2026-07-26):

---
title: GPS
description: GNSS positioning on LIA.
---

LIA uses a [u-blox SAM-M10Q](https://www.u-blox.com/en/product/sam-m10q-module) GNSS module with a ceramic patch antenna, supporting GPS, Galileo, GLONASS, and BeiDou constellations concurrently.

## Fix behavior

- **Cold fix** (no recent almanac/ephemeris data) can take up to a minute or more under open sky — measured at roughly 36 seconds to first lock (10 satellites) on real hardware outdoors.
- **Warm/hot fix** (waking shortly after a previous fix) is typically much faster, since the module retains almanac data across LIA's short deep-sleep cycles.
- Fix time and accuracy both suffer under tree canopy or near buildings — expect degraded performance in dense woods, which is a common real-world case for a pet tracker.
- Indoors, expect no fix at all — the firmware correctly reports "no fix" rather than sending a stale or meaningless position (see [Power Management](/LIA/docs/firmware/power-management/) for how the sleep-cycle mode handles waiting for a fix before giving up on that cycle).

## Troubleshooting a missing fix

1. Confirm the GNSS antenna is connected and not obstructed by metal (including some batteries).
2. Test outdoors with a clear view of the sky before assuming a hardware fault.
3. Check [Troubleshooting](/LIA/docs/troubleshooting/) for more.

See also: [Power Management](/LIA/docs/firmware/power-management/) and [PCB](/LIA/docs/hardware/pcb/).

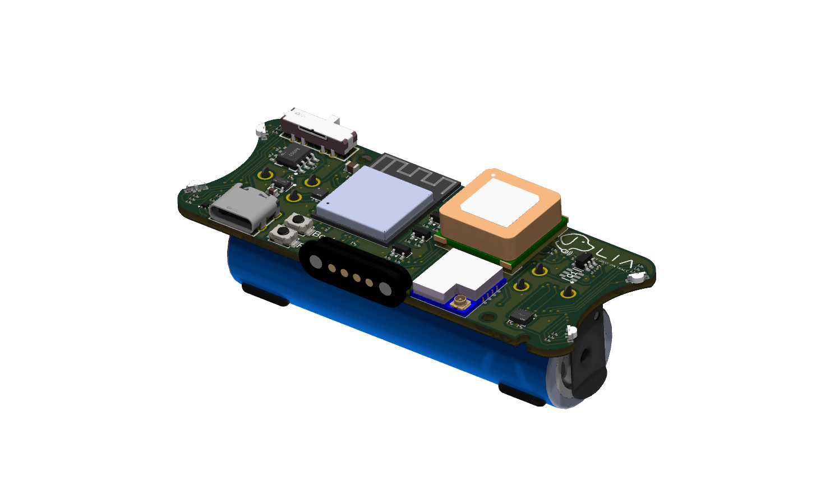
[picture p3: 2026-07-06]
hardware/pcb/renders/Isometric_2.png

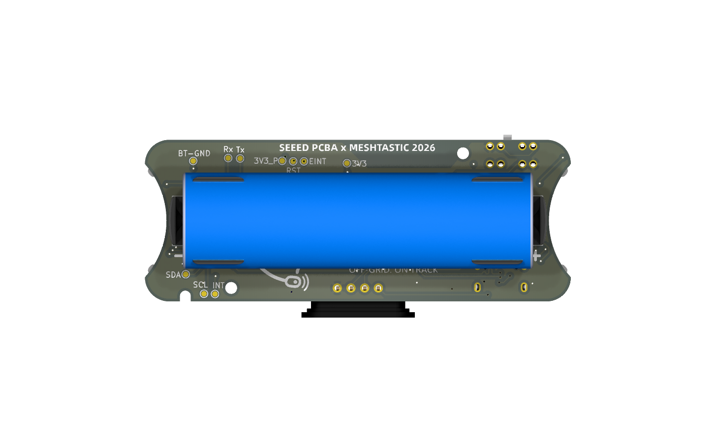
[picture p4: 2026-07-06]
hardware/pcb/renders/Top.png

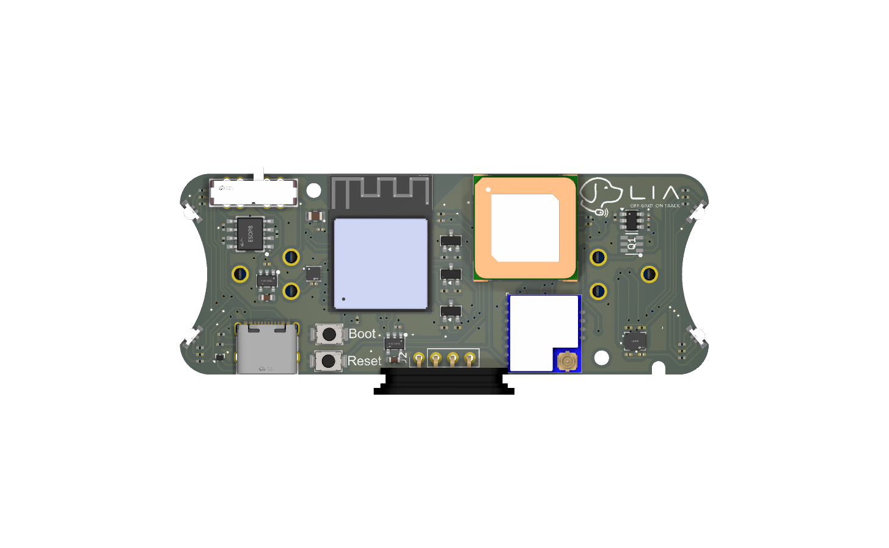
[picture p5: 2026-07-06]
hardware/pcb/renders/Bottom.png

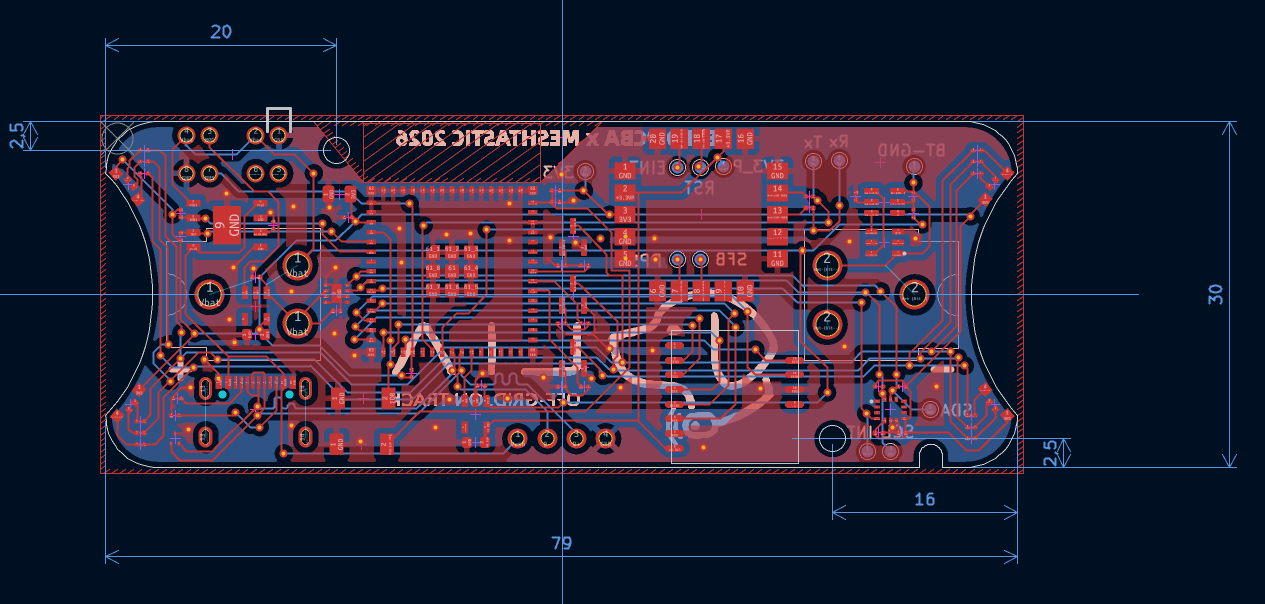
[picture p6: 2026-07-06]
hardware/pcb/renders/Layout.png

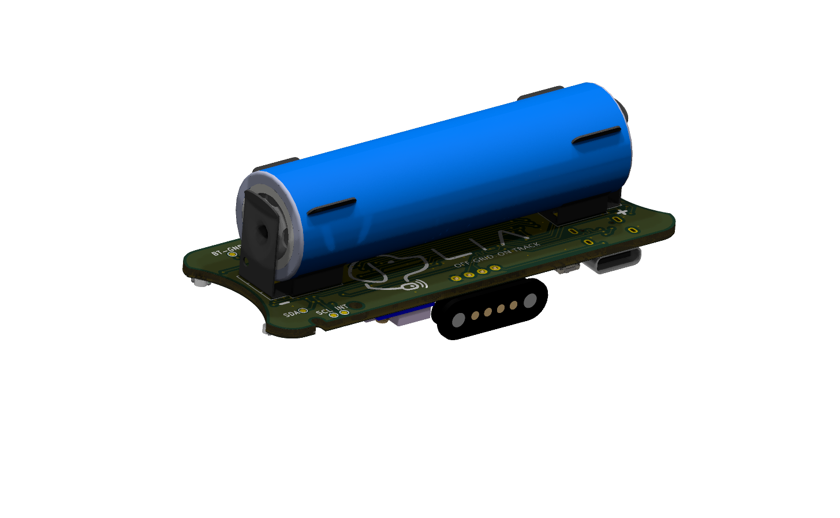
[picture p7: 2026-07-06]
hardware/pcb/renders/Isometric_1.png

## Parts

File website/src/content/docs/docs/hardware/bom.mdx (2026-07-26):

---
title: BOM
description: Bill of materials for the LIA main board.
---

import IbomEmbed from '../../../../components/IbomEmbed.astro';

The interactive BOM below is generated directly from the KiCad project with [InteractiveHtmlBom](https://github.com/openscopeproject/InteractiveHtmlBom) — it stays in sync automatically whenever `hardware/pcb/bom/ibom.html` is regenerated from KiCad, no manual copy step needed. Click a row to highlight the matching part on the board.

<IbomEmbed src="/LIA/generated/bom/ibom.html" title="LIA interactive BOM" />

## Related files

- [`hardware/production/bom.csv`](https://github.com/JGAguado/LIA/blob/main/hardware/production/bom.csv) — full bill of materials
- [`hardware/production/positions.csv`](https://github.com/JGAguado/LIA/blob/main/hardware/production/positions.csv) — pick-and-place positions
- [`hardware/production/designators.csv`](https://github.com/JGAguado/LIA/blob/main/hardware/production/designators.csv) — designator-to-footprint map

See also: [PCB](/LIA/docs/hardware/pcb/) and [Manufacturing](/LIA/docs/manufacturing/).

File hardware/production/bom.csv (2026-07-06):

Designator | Footprint | Quantity | Value | LCSC Part #
3V3, 3V3_P1, BT-GND1, EINT1, INT1, PPS1, RST1, RX1, SCL1, SDA1, SFB1, TX1 | TestPoint_Pad_D1.0mm | 12 | TestPoint
BT1 | BatteryClip_Keystone_54_D16-19mm | 1 | Battery
C1 | 0805 | 1 | 22uF
C10, C11, C8, C9 | 0201 | 4 | 0.1uF
C2 | 0201 | 1 | 1uF
C3 | 0201 | 1 | 4.7uF
C4, C6 | 0201 | 2 | 2.2uF
C5, C7 | 0603 | 2 | 10uF
J2 | POGO-MAG-4P-FEM | 1 | POGO-4P-FEM
LED1, LED2, LED3, LED4 | LED-SMD_4P-L3.2-W1.1_TJ-S3210SW5TCGLC2R2G-A5 | 4 | ~
PB1 | SW-SMD_L3.9-W3.0-P4.45 | 1 | TS-1187A-B-A-B | C318884
PB2 | SW-SMD_L3.9-W3.0-P4.45 | 1 | TS-1187A-B-A-B | C115357
Q1 | SOT-23-6_L2.9-W1.6-P0.95-LS2.8-BL | 1 | 8205A | C351449
Q2, Q3, Q4 | SOT-23 | 3 | AO3400A
R1, R10, R11, R23, R24, R26, R31, R4, R5, R9 | 0201 | 10 | 10k
R12 | 0201 | 1 | 1k
R13 | 0201 | 1 | 100
R14, R15, R17, R18, R20, R21, R29, R30 | 0201 | 8 | 22R
R16, R19, R28, R8 | 0201 | 4 | 68R
R2, R3 | 0201 | 2 | 5.1k
R22, R25, R27 | 0201 | 3 | 100R
R6, R7 | 0201 | 2 | 22
SW1 | SW-TH_SSSS223900 | 1 | ~
U1 | XCVR_ESP32-S3-MINI-1-N8 | 1 | ESP32-S3-MINI-1-N8 | C2913206
U10 | SOT-23-6 | 1 | DW01A
U11, U7 | TSOT-23-5_L2.9-W1.6-P0.95-LS2.8-BL | 2 | RT9080-33GJ5 | C841192
U12 | LGA-14L_L3.0-W2.5-P0.50-TL | 1 | ~ | C481766
U2 | XCVR_SAM-M10Q-00B | 1 | SAM-M10Q-00B
U3 | MODULE12P-1.27-11X11.6MM | 1 | Wio-SX1262
U5 | Texas_DRT-3 | 1 | TPD2EUSB30
U6 | USB-C-SMD_TYPE-C-6PIN-2MD-073 | 1 | TYPE-C_16PIN_2MD(073) | C2765186
U8 | ESOP-8_L4.9-W3.9-P1.27-LS6.0-BL-EP | 1 | TP4056 | C16581
U9 | DFN-8_L2.0-W2.0-P0.50-BL-EP | 1 | MAX17048G+T10 | C2682616

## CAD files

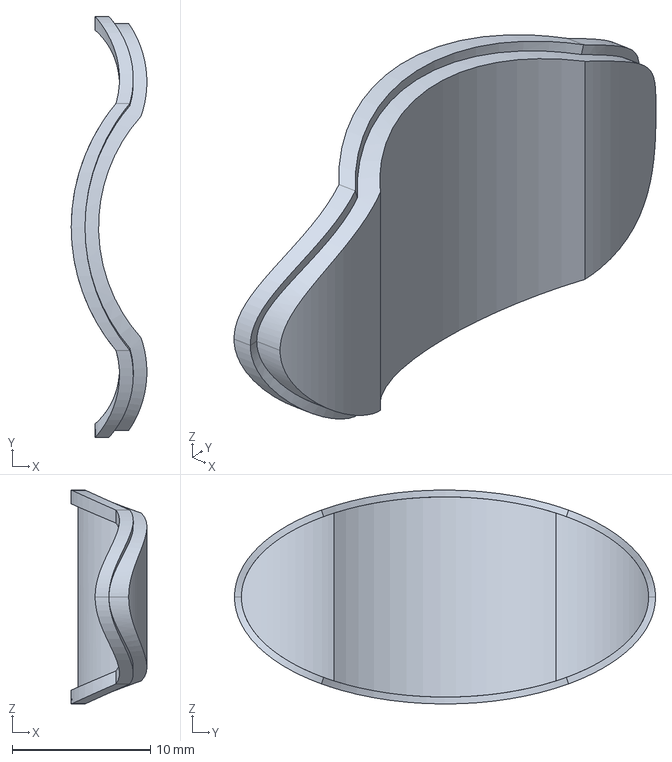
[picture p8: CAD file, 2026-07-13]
enclosure/V1.0-Detachable/step/Window.stp
5.48 x 30.5 x 15.5 mm

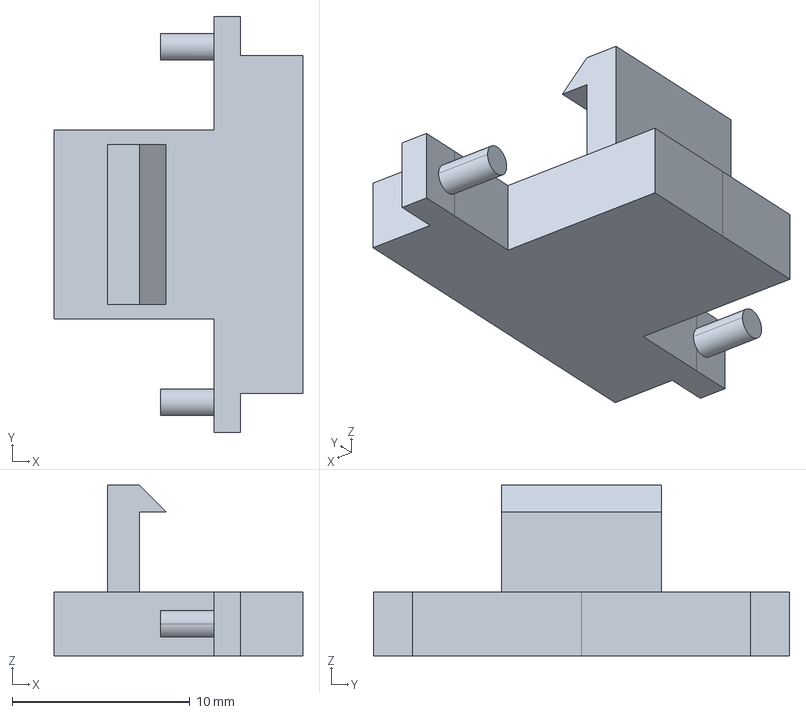
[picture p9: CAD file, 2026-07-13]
enclosure/V1.1-Fixed/step/Latch.stp
14.0 x 23.4 x 9.60 mm

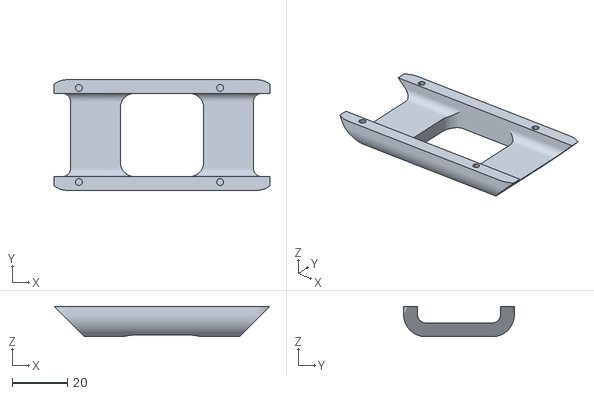
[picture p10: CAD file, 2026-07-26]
enclosure/V1.1-Fixed/stl/Collar_bridge.stl
78.0 x 40.0 x 11.0

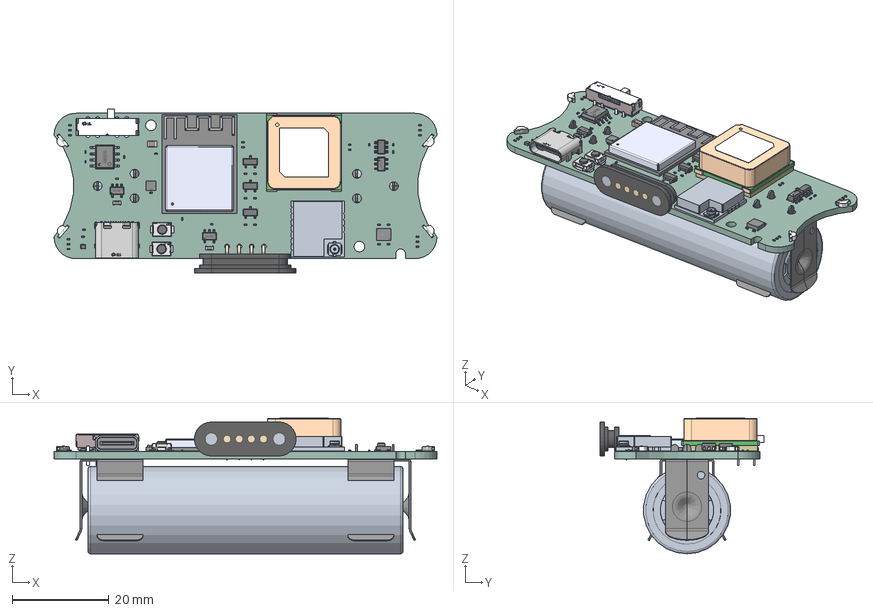
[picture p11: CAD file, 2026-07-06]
hardware/pcb/LIA_PCB.step
79.0 x 33.9 x 28.0 mm
R_0201_0603Metric x 31
SOT-23-6_L2.9-W1.6-H1.5-LS2.8-P0.95
SW-SMD_L3.9-W2.9-H2.0-LS4.8 x 2
C_0201_0603Metric x 8
SW-TH_SSSS223900
C_0603_1608Metric x 2
LIA 1.12
Texas_DRT-3
C_0805_2012Metric
SOT-23 x 3
USB-C-SMD_TYPE-C-6PIN-2MD-073
SOT-23-6
LED-SMD_4P-L3.2-W1.1_TJ-S3210SW5TCGLC2R2G-A5 x 4
SAM-M10Q-00B
LGA-14_L2.5-W3.0-H0.9-P0.50
TSOT-23-5_L2.9-W1.6-P0.95-LS2.8-BL x 2
DFN-8_L2.0-W2.0-P0.50-BL-EP
ESP32-S3-MINI-1-N8
ESOP-8_L4.9-W3.9-P1.27-LS6.0-BL-EP
BatteryClip_Keystone_54_D16-19mm x 2
LIA 1.68
LIA_PCB

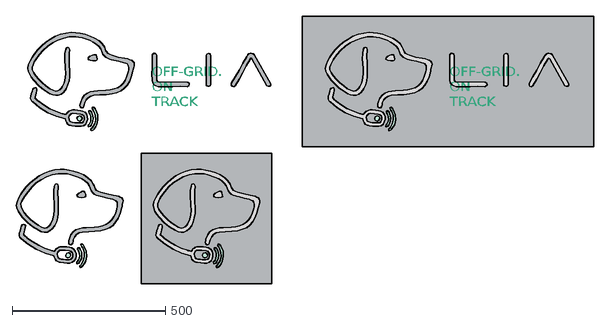
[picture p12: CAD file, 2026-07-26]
website/src/assets/brand/Styleguide.dxf
OFF-GRID. ON TRACK

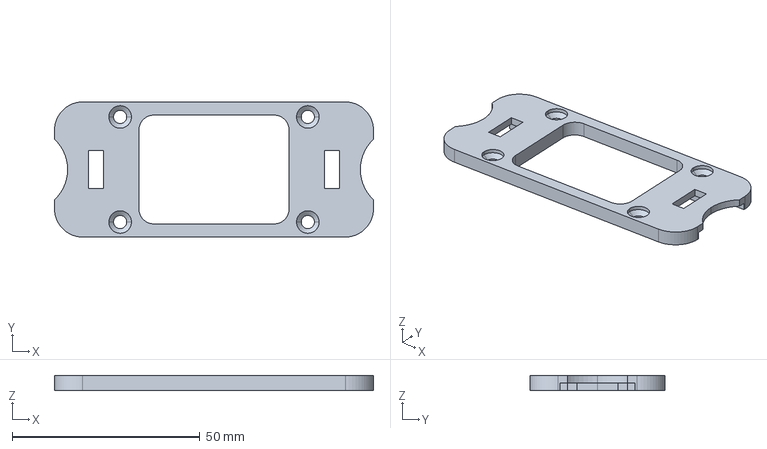
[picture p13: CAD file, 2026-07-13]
enclosure/V1.0-Detachable/step/Top_collar.stp
85.0 x 36.0 x 4.00 mm

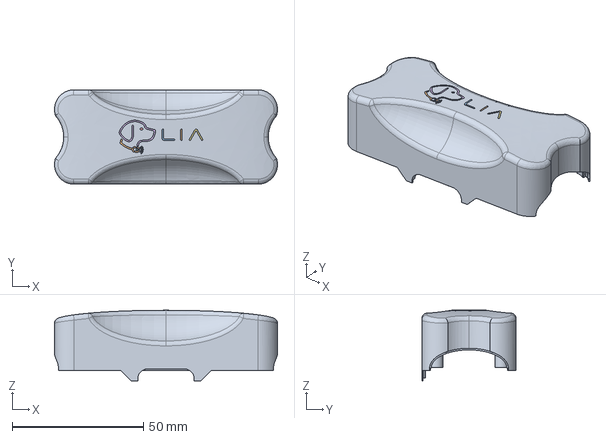
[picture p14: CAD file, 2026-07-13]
enclosure/V1.1-Fixed/step/Top_enclosure.stp
85.0 x 36.0 x 26.9 mm

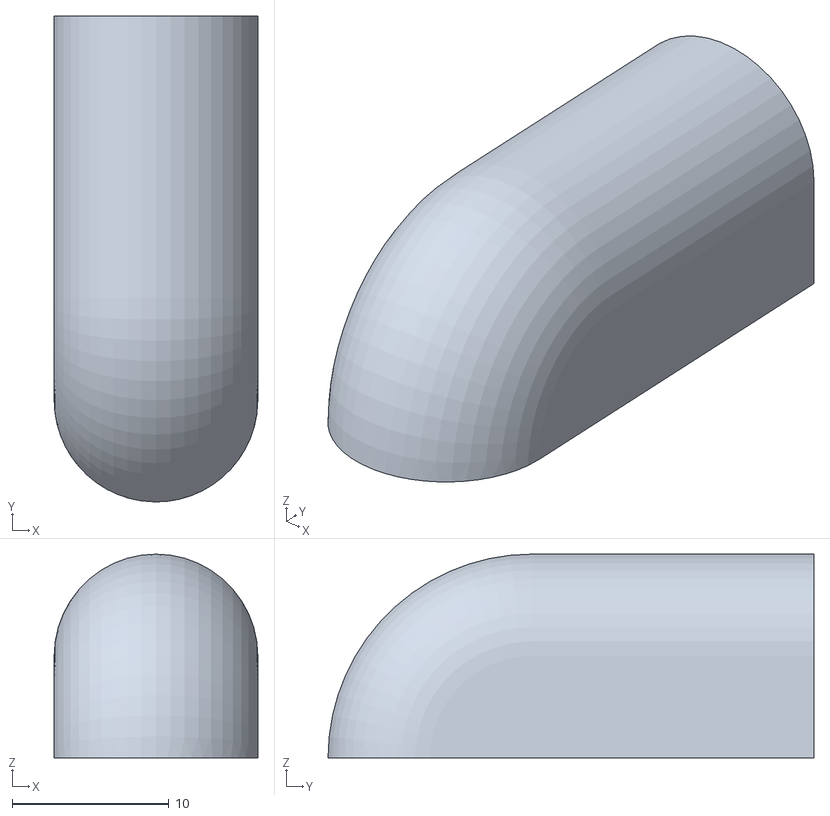
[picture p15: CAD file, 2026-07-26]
enclosure/V1.1-Fixed/stl/Antenna_elbow.stl
13.0 x 31.0 x 13.0

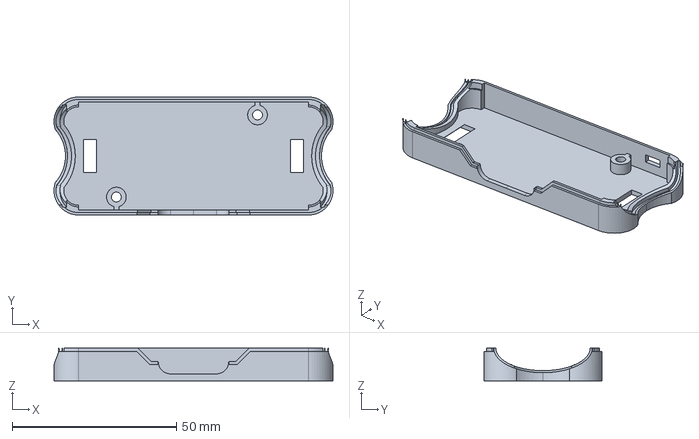
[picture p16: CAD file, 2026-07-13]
enclosure/V1.0-Detachable/step/Bottom_enclosure.stp
85.0 x 36.0 x 10.0 mm

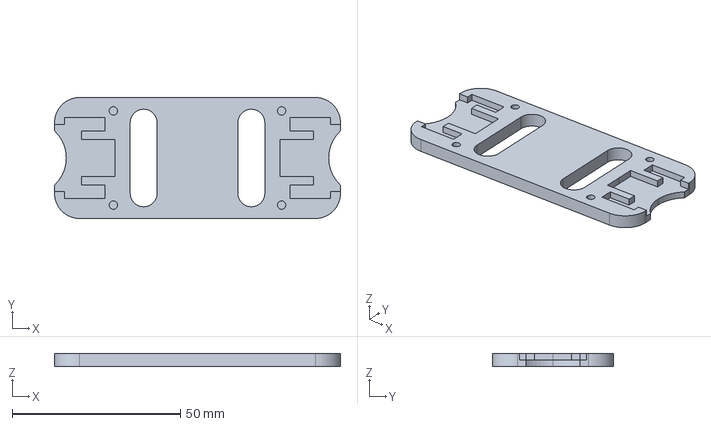
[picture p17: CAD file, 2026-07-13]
enclosure/V1.1-Fixed/step/Bottom_collar.stp
85.0 x 36.0 x 4.00 mm

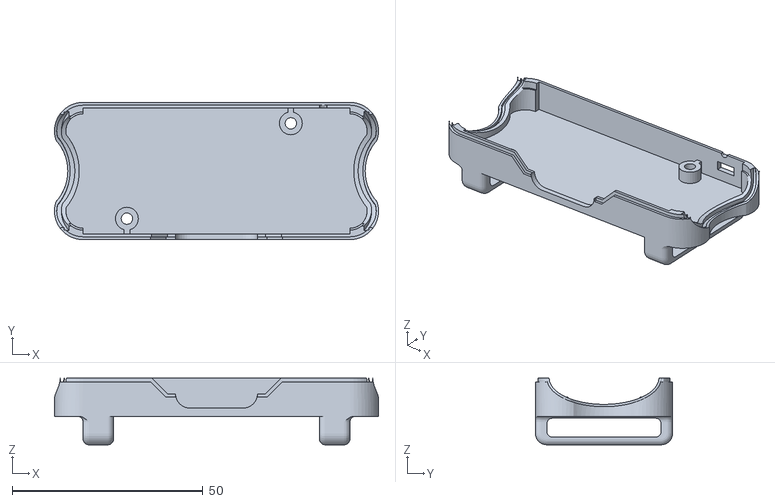
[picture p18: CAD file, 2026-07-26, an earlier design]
enclosure/V1.0-Fixed/stl/Bottom_enclosure_2.stl
85.0 x 36.0 x 17.5

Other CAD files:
enclosure/V1.0-Detachable/stl/Bottom_collar.stl
enclosure/V1.0-Detachable/stl/Bottom_enclosure.stl
enclosure/V1.0-Detachable/stl/Latch.stl
enclosure/V1.0-Detachable/stl/Top_collar.stl
enclosure/V1.0-Detachable/stl/Top_enclosure.stl
enclosure/V1.0-Detachable/stl/Window.stl
enclosure/V1.0-Fixed/stl/Bottom_collar.stl
enclosure/V1.0-Fixed/stl/Bottom_enclosure.stl
enclosure/V1.0-Fixed/stl/Latch.stl
enclosure/V1.0-Fixed/stl/Top_collar.stl
enclosure/V1.0-Fixed/stl/Top_enclosure.stl
enclosure/V1.0-Fixed/stl/Window.stl
enclosure/V1.1-Fixed/stl/Bottom_enclosure.stl
enclosure/V1.1-Fixed/stl/Top_enclosure.stl
enclosure/V1.1-Fixed/stl/Window.stl
hardware/pcb/LIA_PCB.stl

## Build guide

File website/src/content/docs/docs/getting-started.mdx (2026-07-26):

---
title: Getting Started
description: Flash firmware onto a LIA board and pair it with the Meshtastic app.
---

This guide gets a LIA board running Meshtastic firmware and visible in the Meshtastic companion app. It assumes you already have an assembled board — see [Assembly](/LIA/docs/hardware/assembly/) if you're starting from bare PCBs.

## What you'll need

- A LIA board (see [Hardware](/LIA/docs/hardware/pcb/) for build files)
- A USB-C cable or a magnetic 4-pin connector (like [Seeed's T1000](https://www.seeedstudio.com/USB-Cable-Type-A-to-4P-with-magnetic-type-Black-1000mm-p-5977.html))
- The [Meshtastic Android or iOS app](https://meshtastic.org/docs/software/) installed on your phone

## 1. Flash the firmware

LIA runs stock [Meshtastic](https://meshtastic.org/) firmware for the ESP32-S3 target, plus a LIA-specific `lia_v1` board variant layered on top that adds support for the mode switch, status LED, charger status, battery gauge, IMU, and text-command interface — the same `lia_v1` build is correct for both V1.0 and V1.1 boards (see [Building the Firmware](/LIA/docs/firmware/building-the-firmware/#which-variant)).

:::caution
The [Meshtastic Web Flasher](https://flasher.meshtastic.org/) only offers stock, generic ESP32-S3 firmware — it has no `lia_v1` target and doesn't know about LIA's board-specific peripherals, so it isn't usable here. Go straight to **[Building the Firmware](/LIA/docs/firmware/building-the-firmware/)** for the full build-and-flash procedure.
:::

:::caution
The board's mode switch has a third, OFF position that cuts power to the ESP32-S3 entirely (see [Power Management](/LIA/docs/firmware/power-management/)). USB/pogo power alone won't turn the board on if the switch is OFF — it only charges the battery. Make sure the switch is in either of its other two positions before connecting to flash or use the device over serial.
:::

:::tip
If the board doesn't show up as a serial port, install the [CP210x](https://www.silabs.com/developer-tools/usb-to-uart-bridge-vcp-drivers) or native USB CDC driver for your OS first.
:::

## 2. Pair with the app

1. Open the Meshtastic app and add a new device over Bluetooth.
2. Select your LIA device from the scan list.
3. Once connected, confirm it reports a GPS fix — see [GPS](/LIA/docs/firmware/gps/) if it doesn't.

:::tip
Set the device role to **Tracker** and note the node ID of the phone/node you want LIA to report to — LIA sends position broadcasts and text-command replies as direct messages to a single hardcoded target node, not a channel broadcast, so that node must be configured in the firmware before flashing — see [Meshtastic Configuration](/LIA/docs/firmware/meshtastic-configuration/) for exactly what's required and why.
:::

## 3. Confirm mesh connectivity

Send `HELP` as a direct message to the device. A reply listing the available commands confirms the LoRa radio, antenna, and firmware command handling are all working end-to-end — see [Meshtastic Configuration](/LIA/docs/firmware/meshtastic-configuration/) for the full command list.

## Next steps

- Tune radio and region settings in [LoRa](/LIA/docs/firmware/lora/).
- Configure sleep/wake behavior in [Power Management](/LIA/docs/firmware/power-management/).
- Something not working? Check [Troubleshooting](/LIA/docs/troubleshooting/).

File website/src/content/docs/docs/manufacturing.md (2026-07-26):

---
title: Manufacturing
description: How LIA boards are fabricated and assembled.
---

LIA's PCB is designed for turnkey fabrication and assembly through a standard PCBA service (with the idea of using [Seeed Studio Fusion service](https://www.seeedstudio.com/fusion.html)).

## Fabrication outputs

The files needed to order a fabrication/assembly run are generated from KiCad's fabrication toolkit and published under [`hardware/production/`](https://github.com/JGAguado/LIA/tree/main/hardware/production):

- Gerbers and drill files (`LIA.zip`)
- `bom.csv` — bill of materials
- `positions.csv` — pick-and-place coordinates
- `designators.csv` — designator/footprint reference

## Enclosure manufacturing

The enclosure is composed of parts designed for CNC machining and/or 3D printing (resin/FDM) from the STEP/STL exports under each version's own `step/`/`stl/` folder — see [Downloads](/LIA/docs/downloads/#enclosure) for direct links to all three. No production-scale manufacturing process (injection molding, tooling) has been defined yet — this is still a prototype-stage design.

:::note
If you fabricate a batch of boards or enclosures and want to document your process (fab house, settings, yield), please contribute it back — see [Contributing](/LIA/docs/contributing/).
:::

See also: [BOM](/LIA/docs/hardware/bom/) and [Downloads](/LIA/docs/downloads/).

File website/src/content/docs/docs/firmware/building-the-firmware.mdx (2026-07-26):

---
title: Building the Firmware
description: Build and flash the LIA Meshtastic board variant instead of stock firmware.
---

import { Tabs, TabItem, Steps } from '@astrojs/starlight/components';

Stock Meshtastic firmware runs on LIA hardware fine using a generic ESP32-S3 target, but it has no way to know about LIA-specific peripherals — peripheral power gating, the status LED, the mode switch, the charger status pins, the battery gauge, or the IMU. The `lia_v1` board variant and its support code, under [`firmware/`](https://github.com/JGAguado/LIA/tree/main/firmware) in this repository, exists to fill that gap.

## Which variant

There is a single board variant, `lia_v1`, and it's the correct build for **both** the V1.0 and V1.1 boards. The LSM6DSOXTR IMU's `SDA`/`SCL` lines were originally crossed as manufactured, which caused I2C bus errors — a solder rework crossing them back fixes this, and both hardware revisions now ship with that rework done, so both have a working IMU and MAX17048 battery gauge over I2C. V1.0 and V1.1 are a **hardware-only** distinction (18650 3500mAh vs. 5023450 1000mAh battery, and a corresponding enclosure difference — see [Enclosure](/LIA/docs/hardware/enclosure/) and [Battery](/LIA/docs/firmware/battery/)); there is no firmware difference and no separate board variant for V1.1.

## What's involved

Meshtastic's own firmware build (`meshtastic/firmware` on GitHub) isn't vendored into this repository — it's a large, independently-versioned project. Building for LIA means applying this repo's overlay on top of a checkout of it:

- [`firmware/meshtastic/variants/esp32s3/lia_v1/`](https://github.com/JGAguado/LIA/tree/main/firmware/meshtastic/variants/esp32s3/lia_v1) — `variant.h` (GPIO pin mapping, derived from the schematic — see [Microcontroller](/LIA/docs/firmware/microcontroller/)), `pins_arduino.h`, and `platformio.ini` for that board environment.
- [`firmware/meshtastic/extra_variants/lia_v1/variant.cpp`](https://github.com/JGAguado/LIA/tree/main/firmware/meshtastic/extra_variants/lia_v1) — hooks into Meshtastic's `earlyInitVariant()`/`lateInitVariant()`/`variant_shutdown()` extension points to initialize `LiaBoard` and construct `TrackerService`, `ChargeStatusService`, and `CommandService`.
- [`firmware/board/`](https://github.com/JGAguado/LIA/tree/main/firmware/board) — `LiaBoard`, the hardware abstraction for peripheral power gating, the status LED, the mode switch, and charger status.
- [`firmware/drivers/`](https://github.com/JGAguado/LIA/tree/main/firmware/drivers) — `ImuMotionDriver`, talking to the LSM6DSOXTR directly (stock Meshtastic's own accelerometer support doesn't drive this specific chip — see [Accelerometer](/LIA/docs/firmware/accelerometer/)).
- [`firmware/services/`](https://github.com/JGAguado/LIA/tree/main/firmware/services) — `TrackerService` (position broadcasts + the BMS state machine), `ChargeStatusService` (charge-status messages), `CommandService` (the text-command interface), plus the shared `MeshTargets.h` target-node definition.

No core Meshtastic files are patched — everything hooks in via the extension points above.

## Build steps

`firmware/tools/build.ps1` automates all of this (clone-if-missing, checkout the pinned tag, copy the overlay, `pio run`). Run it from a **native PowerShell** session, not Git Bash/MSYS — the ESP-IDF toolchain this platform pulls in refuses to run under MSYS.

<Steps>

1. Build (`lia_v1` is the only variant — the correct build for both V1.0 and V1.1 boards):

   ```powershell
   cd firmware/tools
   ./build.ps1
   ```

2. Build and flash in one step:

   ```powershell
   ./build.ps1 -Upload -Port COM7
   ```

</Steps>

Or manually, following the same steps the script automates:

<Steps>

1. Clone Meshtastic's firmware repository and check out the pinned tag (`main` is a moving development branch):

   ```powershell
   git -c core.longpaths=true clone --recurse-submodules --depth 1 `
     --branch v2.7.26.54e0d8d https://github.com/meshtastic/firmware.git meshtastic-firmware
   ```

   `core.longpaths=true` is required on Windows — some paths inside this repo exceed 260 characters.

2. Copy this repo's overlay into the checkout:

   ```powershell
   Copy-Item firmware/meshtastic/boards/lia_v1.json meshtastic-firmware/boards/
   New-Item -ItemType Directory -Force meshtastic-firmware/variants/esp32s3/lia_v1
   Copy-Item firmware/meshtastic/variants/esp32s3/lia_v1/* meshtastic-firmware/variants/esp32s3/lia_v1/
   New-Item -ItemType Directory -Force meshtastic-firmware/src/platform/extra_variants/lia_v1
   Copy-Item firmware/meshtastic/extra_variants/lia_v1/* meshtastic-firmware/src/platform/extra_variants/lia_v1/
   New-Item -ItemType Directory -Force meshtastic-firmware/src/lia
   Copy-Item firmware/board/*.h, firmware/board/*.cpp meshtastic-firmware/src/lia/
   Copy-Item firmware/drivers/*.h, firmware/drivers/*.cpp meshtastic-firmware/src/lia/
   New-Item -ItemType Directory -Force meshtastic-firmware/src/lia/services
   Copy-Item firmware/services/*.h, firmware/services/*.cpp meshtastic-firmware/src/lia/services/
   ```

3. Build:

   ```powershell
   cd meshtastic-firmware
   pio run -e lia_v1
   ```

4. Flash:

   ```powershell
   pio run -e lia_v1 -t upload --upload-port <PORT>
   ```

</Steps>

:::tip
If PlatformIO's own package/tool environment (`~/.platformio/penv`) is in a broken state (Python version mismatch, failed `pip`/`uv` install), delete that folder and let PlatformIO recreate it on the next `pio run` — it's PlatformIO's own internal tool venv, not your project.
:::

## Standalone bring-up tests

Two small, Meshtastic-free PlatformIO projects under [`firmware/tools/`](https://github.com/JGAguado/LIA/tree/main/firmware/tools) isolate specific hardware questions from the rest of the firmware's complexity, useful when debugging just the GPS or the battery gauge in isolation:

- **[`gps_test/`](https://github.com/JGAguado/LIA/tree/main/firmware/tools/gps_test)** — powers the GNSS module and prints whatever it's decoded every 10 seconds.
- **[`battery_test/`](https://github.com/JGAguado/LIA/tree/main/firmware/tools/battery_test)** — prints the MAX17048's charge percentage and cell voltage every 2 seconds, via two independently-computed read paths side by side (this is what isolated a real gauge-reading bug — see [Battery](/LIA/docs/firmware/battery/)).

Each has its own `platformio.ini` and README with build/flash instructions.

## Provisioning after flashing

Set the device role to `TRACKER` and note the target node LIA sends everything to (position broadcasts, charge-status messages, and CommandService replies are all direct messages to a single hardcoded node — see [Meshtastic Configuration](/LIA/docs/firmware/meshtastic-configuration/) for exactly what's required and why).

See also: [Getting Started](/LIA/docs/getting-started/), [Meshtastic Configuration](/LIA/docs/firmware/meshtastic-configuration/), and [Microcontroller](/LIA/docs/firmware/microcontroller/).

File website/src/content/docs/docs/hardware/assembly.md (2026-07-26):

---
title: Assembly
description: Putting an assembled PCB into the LIA enclosure.
---

## Prerequisites

- An assembled LIA PCB (see [PCB](/LIA/docs/hardware/pcb/) and [BOM](/LIA/docs/hardware/bom/))
- A printed or manufactured enclosure (see [Enclosure](/LIA/docs/hardware/enclosure/))
- An 18650 Li-ion cell
- External LoRa antenna (FPC LoRa antenna or alternative omnidirectional antenna, and GNSS patch antenna) — see [PCB](/LIA/docs/hardware/pcb/#antennas)

## Tracking unit assembly

1. Seat the 18650 cell in the battery clip, observing polarity and clip the antenna to the SX1262 module.
2. Flash and smoke-test the board **before** enclosing it — see [Getting Started](/LIA/docs/getting-started/).
3. Route the LoRa antenna, along the inside of the top shell (the stock FPC antenna or the alternative omnidirectional antenna — see [PCB](/LIA/docs/hardware/pcb/#antennas) — both use the same connector).
4. Lower the PCB into the bottom shell onto its standoffs.
5. Fit the top shell and side windows, then close and screw top and bottom shells of the tracker enclosure.
6. Confirm the status LEDs are visible through the window and the board still gets a GPS/mesh fix once sealed.

See also: [Manufacturing](/LIA/docs/manufacturing/).

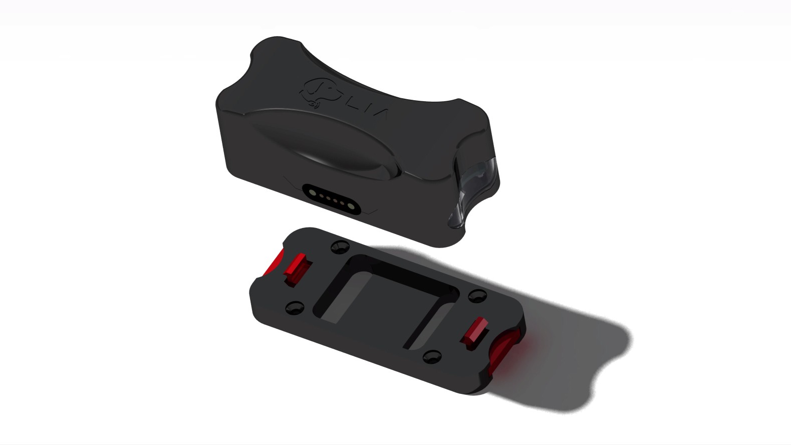
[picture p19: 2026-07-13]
enclosure/V1.0-Detachable/renders/assembly-1.jpg

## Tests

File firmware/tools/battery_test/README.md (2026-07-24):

# Battery gauge bring-up test

Standalone MAX17048 test for LIA v1 -- no Meshtastic, no LoRa, no GPS.
Isolates a real-hardware bug where `CommandService`'s `BATTERY` command
always reports ~0% regardless of actual charge state (see
`firmware/docs/phase-status.md`). Deliberately independent of
`firmware/meshtastic/` -- this is a plain Arduino sketch, not a Meshtastic
build, so it has no dependency on a Meshtastic checkout.

Prints two independently-computed readings side by side every 2s over
native-USB serial (115200 baud):

- **`[raw]`** -- a direct SOC/VCELL register read via `Adafruit_I2CDevice` +
  `Adafruit_BusIO_Register`, never calling `Adafruit_MAX17048::begin()`
  (which sends the chip a hardware reset command, `0x5400`, before every
  use). Same approach `CommandService::batteryPercent()` uses.
- **`[library]`** -- the stock `Adafruit_MAX17048` class, `begin()`'d once at
  setup (so its one-time reset happens before any readings are taken, same
  as it would in Meshtastic).

## Build & flash

From this directory (`firmware/tools/battery_test/`), with the board
connected:

```powershell
pio run -e lia_v1 -t upload --upload-port <PORT>
```

## Reading the output

```
Adafruit_MAX17048::begin() -> OK
Chip ID: 0x..., IC version: 0x...
t=2s [raw] SOC=xx.xx% VCELL=x.xxxxV  [library] SOC=xx.xx% VCELL=x.xxxxV
t=4s [raw] SOC=xx.xx% VCELL=x.xxxxV  [library] SOC=xx.xx% VCELL=x.xxxxV
```

- `Adafruit_MAX17048::begin() -> FAILED`, or no `Chip ID`/`IC version` line
  -- the gauge isn't responding on I2C at all (wiring, address, or power
  rail problem). Neither `[raw]` nor `[library]` can be trusted.
- `VCELL` reading a plausible battery voltage (roughly 3.0-4.2V for a LiPo)
  while `SOC` stays near 0% -- the chip sees a real battery but its
  charge-percentage algorithm hasn't produced a sensible estimate. If
  `[library]`'s `SOC` climbs toward a plausible value over the first
  samples while `[raw]` does not, that confirms the reset-then-immediate-read
  theory (the fix already applied to `CommandService`: read without
  resetting, and expect it to already be correct from the first sample).
  If **both** stay stuck near 0% indefinitely, the reset-timing theory is
  wrong and the real cause is something else (needs `quickStart()`, a
  hibernation/config register in a bad state, or the chip has never been
  calibrated against this specific cell).
- `VCELL` reading ~0V too -- not a percentage-calculation problem at all;
  check the physical battery connection to the gauge's sense pins.

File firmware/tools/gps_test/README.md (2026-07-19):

# GPS bring-up test

Standalone SAM-M10Q test for LIA v1 -- no Meshtastic, no LoRa, no LED.
Powers the GNSS module (PPC high) and prints whatever
[TinyGPSPlus](https://github.com/mikalhart/TinyGPSPlus) has decoded over
native-USB serial (115200 baud) every 10 seconds. Deliberately independent of
`firmware/meshtastic/` -- this is a plain Arduino sketch, not a Meshtastic
build, so it has no dependency on a Meshtastic checkout.

Useful for isolating GPS antenna/wiring/fix-time questions (open-sky cold fix,
sensitivity to obstruction) from the rest of the tracker firmware.

## Build & flash

From this directory (`firmware/tools/gps_test/`), with the board connected:

```powershell
pio run -e lia_v1 -t upload --upload-port <PORT>
```

## Reading the output

```
t=40s fix=no sats=4 hdop=-1.0 charsProcessed=1832 sentencesWithFix=0 failedChecksum=0
t=50s fix=yes sats=7 hdop=1.2 lat=41.123456 lon=2.123456 alt=45.3m age=87ms utc=2026-07-19_17:32:04 charsProcessed=2417 sentencesWithFix=3 failedChecksum=0
```

- `charsProcessed` staying near 0 forever -> the module isn't talking at all
  (check wiring/baud, `LIA_PIN_PPC`/GPS UART pins in `firmware/AGENTS.md`).
- `charsProcessed` climbing but `sentencesWithFix` stuck at 0 -> talking fine,
  just no fix yet (needs open sky, or more time for a cold fix).
- `failedChecksum` climbing -> noisy/wrong wiring or wrong baud rate.

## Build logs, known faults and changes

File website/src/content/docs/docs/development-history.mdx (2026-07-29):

---
title: Development History
description: A phase-by-phase log of how LIA's firmware got built, including the bugs found along the way.
---

import Gallery from '../../../components/Gallery.astro';
import BuildGallery from '../../../components/BuildGallery.astro';

import iicFix1 from '../../../assets/photos/IIC fix/1.jpg';
import iicFix2 from '../../../assets/photos/IIC fix/2.jpg';
import iicFix3 from '../../../assets/photos/IIC fix/3.jpg';
import iicFix4 from '../../../assets/photos/IIC fix/4.jpg';

This is a running, chronological log of LIA's firmware development — written like a blog rather than a spec, because a lot of what's interesting here is _what went wrong and why_, not just what shipped. The formal phase roadmap this follows lives in [`firmware/AGENTS.md`](https://github.com/JGAguado/LIA/blob/main/firmware/AGENTS.md); the day-to-day validation notes behind each entry live in [`firmware/docs/phase-status.md`](https://github.com/JGAguado/LIA/blob/main/firmware/docs/phase-status.md).

## Phase 0-1 — Board bring-up and peripheral power

The first firmware milestone was the boring-but-essential one: a PlatformIO project for the `lia_v1` board variant that builds, flashes, and boots to a working USB serial console. Peripheral power control (`PPC`) came next — the SX1262 radio and the SAM-M10Q GPS module share a power rail, gated by a single GPIO, and both need it driven high before anything talks to them.

## Phase 2 — Getting the radio talking (and two real crashes)

Turning the board into an actual Meshtastic node — SPI to the SX1262, a periodic "LIA Radio Test" broadcast — hit two genuine firmware bugs on the very first flash, both root-caused with `addr2line` against the built ELF rather than guessing from log output alone:

1. A null-pointer dereference: the test module's periodic callback read a global (`airTime`) that Meshtastic's own `main.cpp` hadn't constructed yet at the point our hook ran.
2. A more subtle one: a single `LOG_INFO()` call placed too early in boot (before the console/logging subsystem itself was initialized) crashed inside Meshtastic's own logging code. The fix was just moving that log line later — but finding _why_ a seemingly-harmless print statement crashed the board took real investigation.

Once fixed, the destination node received "LIA Radio Test" for real, confirmed independently from the receiving side via the official Meshtastic app.

## Phase 3.5-5 — TrackerService and real GPS positions

The ad-hoc test sender got formalized into `TrackerService`, then upgraded to send actual GPS positions instead of a fixed string once the SAM-M10Q was confirmed working (it turned out to need no custom code at all — stock Meshtastic already auto-detects and drives it). Verified against a real 39-node mesh with genuine RF round-trips, not just local logs.

## Phase 6 — The BMS switch, and a deep-sleep crash

This is where the physical mode switch (`BMS`) got wired up: switch HIGH means continuous tracking (LED on, broadcast every 30 seconds, never sleep); switch LOW means a low-power cycle (wake roughly once a minute, get a fix, send it, sleep again).

Getting the sleep half of this working on real hardware surfaced a genuine crash: deep sleep uses an observer pattern where multiple parts of the firmware register interest in "we're about to sleep, do your cleanup." LIA's own power-gating hook was registering _too early_ — before the radio and GPS drivers had registered their own graceful-shutdown hooks — so peripheral power was being cut before those drivers could tell their chips to standby cleanly. The radio's own internal assertion caught the resulting SPI failure. The fix was purely about _when_ to register the hook, not what it does; confirmed across two full real sleep/wake cycles afterward.

## Standalone GPS test, and a private channel for position

Once the tracker was sending real positions, the next question was privacy: Meshtastic encrypts per-channel rather than per-recipient, and position handling is promiscuous by design (any node that can decrypt a packet updates its own map from it, regardless of who it was addressed to). Sending on the default public channel meant _any_ node on the mesh could see this device's location. The fix was to send only on a private channel — named `Test`, looked up dynamically by name rather than a hardcoded index — so only people who'd been given that channel's key could see it. This same channel became the backbone for everything LIA-specific added afterward.

Around the same time, a small standalone PlatformIO project (`firmware/tools/gps_test/`) — no Meshtastic, just TinyGPSPlus and a serial print every 10 seconds — was built to get an outdoor cold-fix confirmation independent of the rest of the firmware's complexity: a real fix in about 36 seconds, 10 satellites.

## Phase 7 — Charging status, and a wiring lesson

The original plan for charge status was a breathing/solid/off LED pattern. That got superseded by a more useful design: text messages (`"Charging"`, `"Device charged"`) sent to the private channel instead, since the LED was already spoken for by the BMS indicator.

The `STBY` pin's polarity (which level means "charge complete") went through a real correction here. An initial assumption had it backwards; a live hardware test happened to _look_ like it passed anyway, which is exactly the kind of false confidence a single test can give you. It was the actual TP4056 charge-controller wiring — an external pull-up holds `STBY` high while charging, an internal switch pulls it low on completion — that settled it for good, once that detail was worked out precisely.

## Phase 8 — Waking early instead of waiting

The low-power sleep cycle originally only woke on its own once-a-minute timer. Phase 8 added two more ways to wake immediately instead of waiting out the interval: flipping the BMS switch, or plugging in a charger — both wired as real hardware interrupts (ESP32 RTC-domain wake sources), armed right before every deep sleep.

## An LED polarity bug, found by testing the thing it was supposed to fix

While confirming Phase 7 on real hardware, the RED LED's actual behavior didn't match its intended behavior — inverted, as if the wiring assumption behind the LED driver code was backwards. Since the BMS state machine driving it had already been independently proven correct (by its send/sleep timing, unrelated to the LED at all), the bug was isolated cleanly to the LED driver's own polarity assumption. Fixed by removing an unnecessary inversion, confirmed by eye afterward.

## The wrong LED part

The board's status indicator was designed around a true RGB LED (LCSC part `C397052`), but the first assembled batch has a different part soldered in its place: a two-color Red/Green LED (`C601680`), sharing the same 4-pin footprint but not the same die. Of that part's two colors, only Red ended up wired to a firmware-driven channel, so the assembled units only ever show RED regardless of what the design intends the LED to be capable of. This is a sourcing/assembly mistake to correct in a future PCB spin, not a firmware bug.

## A second hardware revision, and a rework that unified them

A second physical board arrived with its accelerometer IC (an LSM6DSOXTR, sharing the I2C bus with a MAX17048 battery gauge) desoldered entirely — the original board's `SDA`/`SCL` lines to that chip had been crossed as manufactured, which caused I2C bus errors badly enough that I2C had to be left disabled on the original board altogether. Removing the IMU sidestepped the problem rather than fixing it, freeing the bus for the gauge alone. This became `lia_v2`, a second PlatformIO board variant sharing all the same LIA-specific firmware — the only difference is which pins get defined for I2C.

Later, the original board got a solder rework crossing `SDA`/`SCL` back correctly, fixing the wiring defect at its source rather than working around it. With that rework applied, `lia_v1` also got I2C enabled, and — since the LSM6DSOXTR/MAX17048 chips report a chip-ID collision that Meshtastic's own detection labels under a different sensor name (`QMI8658`) than what stock Meshtastic actually knows how to drive — a small dedicated driver (`ImuMotionDriver`) was added to talk to the real chip directly rather than relying on stock support that silently doesn't apply here. Both boards ended up physically identical shortly after, once the same rework was applied to the second board too — at which point `lia_v2` as a separate firmware variant no longer served any purpose and was retired; a single `lia_v1` build now covers both, and the hardware-only battery/enclosure distinction between them is tracked instead as V1.0/V1.1 (see [Battery](/LIA/docs/firmware/battery/) and [Enclosure](/LIA/docs/hardware/enclosure/)).

The rework itself, step by step:

<Gallery
  id="iic-fix"
  images={[
    {
      src: iicFix1,
      alt: 'The board before rework, SDA/SCL soldermask still intact over the crossed traces',
      caption: '1. Remove the soldermask to expose the two SDA/SCL routes.',
    },
    {
      src: iicFix2,
      alt: 'The two exposed copper routes, now cut',
      caption: '2. Cut the routes.',
    },
    {
      src: iicFix3,
      alt: 'Two crossed jumper wires soldered in place of the cut routes',
      caption: '3. Cross the routes with two wires.',
    },
    {
      src: iicFix4,
      alt: 'The rework covered in a blob of hot glue for protection',
      caption: '4. Cover the fix with hot glue/resin to protect it.',
    },
  ]}
/>

## CommandService — a text-command interface, and two bugs it surfaced

With both boards now capable of reading the battery gauge and (on `lia_v1`) the IMU, a text-command interface (`GPS`, `BATTERY`, `IMU ON`/`OFF`, `CHG ON`/`OFF`, `STB ON`/`OFF`, `HELP`, later `LED ON`/`OFF`) replaced one-way notifications with something interactive. Building and testing it on real hardware surfaced two more real bugs:

- **Direct messages were being silently dropped.** The private-channel design above worked fine for broadcasts, but a direct message sent through the official app is commonly PKI-encrypted — a mechanism that bypasses the channel/PSK system entirely and reports a channel value that doesn't mean what it looks like it means. The fix: also accept any message addressed directly to the device, regardless of that value, since being addressed directly already requires knowing the device in the first place.
- **The battery gauge always reported ~0%,** even after fixing an initial suspicion (that reading the gauge right after resetting it was catching it before it settled). A standalone, Meshtastic-free test project (`firmware/tools/battery_test/`) built specifically to isolate this compared two independent read paths side by side — they agreed with each other exactly, and neither improved over time, which ruled out the reset theory. What they agreed on was a real, low cell voltage, independently confirmed with a multimeter. Not a bug at all — a genuinely low battery.

The command syntax itself iterated a couple of times in response to how people actually typed commands — from underscores (`LED_ON`) to no separator (`LEDON`) to, finally, a plain space (`LED ON`), after real usage showed people naturally typing "Led off" and expecting it to just work.

## Dropping the private channel for direct addressing

The private-channel design worked, but it asked for something people kept getting wrong in practice: a specifically-named channel (`Test`) had to exist and be shared out-of-band before anything LIA-specific would do anything at all, and getting that wrong meant messages silently failing closed with no obvious signal why. Given that direct messages were already being special-cased to work around PKI encryption (see above), the channel lookup was doing less and less real work — a DM to a specific node already requires knowing/pairing with that node, and the official app's PKI encryption to that node's identity key isn't a weaker bar than possessing a channel's PSK. The channel concept (and its supporting `ChannelLookup` lookup-by-name helper) was removed entirely in favor of addressing everything — position broadcasts, charge-status messages, and all `CommandService` traffic — as a direct message to a single predefined target node (`MeshTargets.h`'s `kLiaTargetNode`, derived from that node's MAC address).

## What's next

See the [Roadmap](https://github.com/JGAguado/LIA#roadmap) in the main README for where things stand at a glance, and [`firmware/docs/phase-status.md`](https://github.com/JGAguado/LIA/blob/main/firmware/docs/phase-status.md) for the detailed, evidence-quoted version of everything above.

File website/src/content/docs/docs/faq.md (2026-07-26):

---
title: FAQ
description: Frequently asked questions about LIA.
---

## Does LIA need a subscription?

No. LIA has no cloud backend and no recurring fee. Location data travels over the Meshtastic mesh, which is community-operated and free to use.

## Does LIA work anywhere?

Only where there's LoRa mesh coverage — either your own nodes or nearby community nodes on the same region/channel. In areas with no Meshtastic nodes at all, LIA can still log GPS fixes locally, but it can't relay them anywhere.

## Is LIA waterproof?

The enclosure is still under design, with the aim to have with a gasket seal on future revisions. However at the moment, and for development purposes the enclosure has pockets to easily access the BMS switch and external antennas — see [Enclosure](/LIA/docs/hardware/enclosure/) and [Assembly](/LIA/docs/hardware/assembly/).

## Can I build my own?

Yes — that's the point. All hardware, firmware, and CAD files are published in this repository under [CC BY-NC-SA 4.0](/LIA/docs/license/). See [Downloads](/LIA/docs/downloads/) for the design files and [Getting Started](/LIA/docs/getting-started/) for firmware setup.

## Can I sell LIA devices I build?

Not without permission — the license is non-commercial. See [License](/LIA/docs/license/).

## How do I get help?

Open an issue on [GitHub](https://github.com/JGAguado/LIA/issues), or check [Troubleshooting](/LIA/docs/troubleshooting/) first.

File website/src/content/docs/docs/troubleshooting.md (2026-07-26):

---
title: Troubleshooting
description: Common problems and how to diagnose them.
---

## Device won't power on

- Confirm the 18650 cell is seated with correct polarity.
- Check the cell's voltage independently — over-discharged protected cells can latch off until charged.
- Try charging over the magnetic pogo connector for a few minutes before assuming a hardware fault.

## Device flashes but never boots past the first second or two

Seen on the `lia_v1` custom build (not stock Meshtastic) on the first
assembled board: serial output stops right after CPU frequency is set, before
LoRa/GPS initialize. See
[Building the Firmware — Known issues](/LIA/docs/firmware/building-the-firmware/#known-issues-on-first-hardware)
for what's been ruled out so far (not Bluetooth-related) and the leading
suspect (an I2C bus lockup during Meshtastic's sensor scan — check `SDA`/`SCL`
pull-ups and whether the IMU/fuel gauge are actually populated on your board).

## No GPS fix

- See [GPS](/LIA/docs/firmware/gps/) — most "no fix" reports are actually a cold fix taking longer than expected, or testing indoors.
- Confirm the GNSS antenna connector is fully seated.

## Not visible on the mesh

- Confirm the [region](/LIA/docs/firmware/lora/) is set — an unset region silently disables the radio.
- Check that at least one other Meshtastic node is within range and on the same channel/region.
- Confirm the node role is set to `TRACKER` — see [Meshtastic Configuration](/LIA/docs/firmware/meshtastic-configuration/).

## Battery drains faster than expected

- Review the broadcast interval and duty cycle in [Power Management](/LIA/docs/firmware/power-management/) — frequent position broadcasts cost real battery life.
- Confirm deep sleep is actually being entered (some debug/logging builds keep peripherals awake).

:::tip
If none of this helps, open an issue on [GitHub](https://github.com/JGAguado/LIA/issues) with your firmware version, region setting, and a description of what you're seeing.
:::

See also: [FAQ](/LIA/docs/faq/).

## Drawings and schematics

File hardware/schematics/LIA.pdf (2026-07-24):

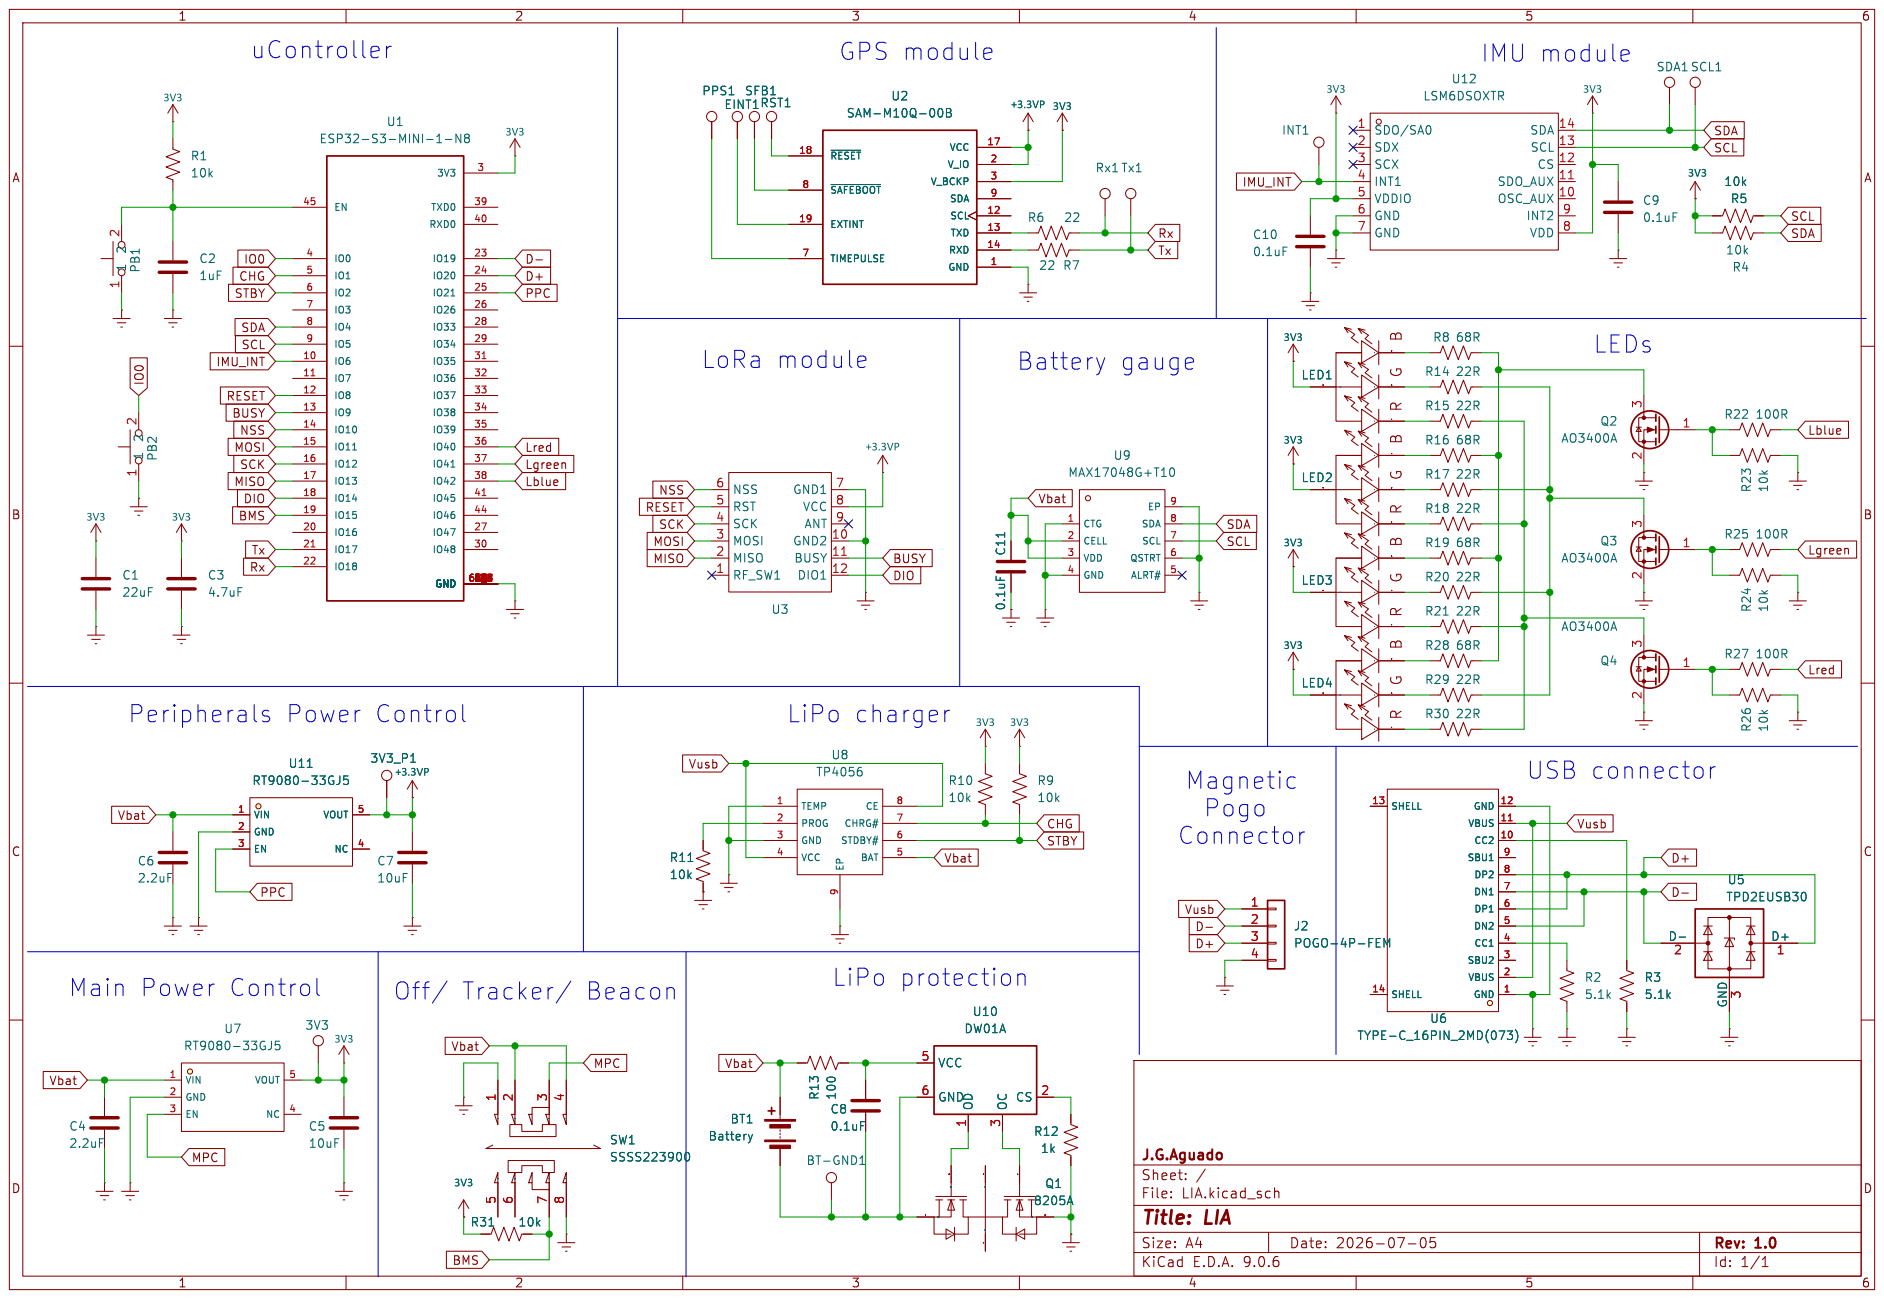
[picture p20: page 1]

9 CE 8 CHRG# 7 STDBY# 6 BAT 5 U8 TP4056
10k SW1 SSSS223900

File: LIA.kicad_sch Sheet: / J.G.Aguado

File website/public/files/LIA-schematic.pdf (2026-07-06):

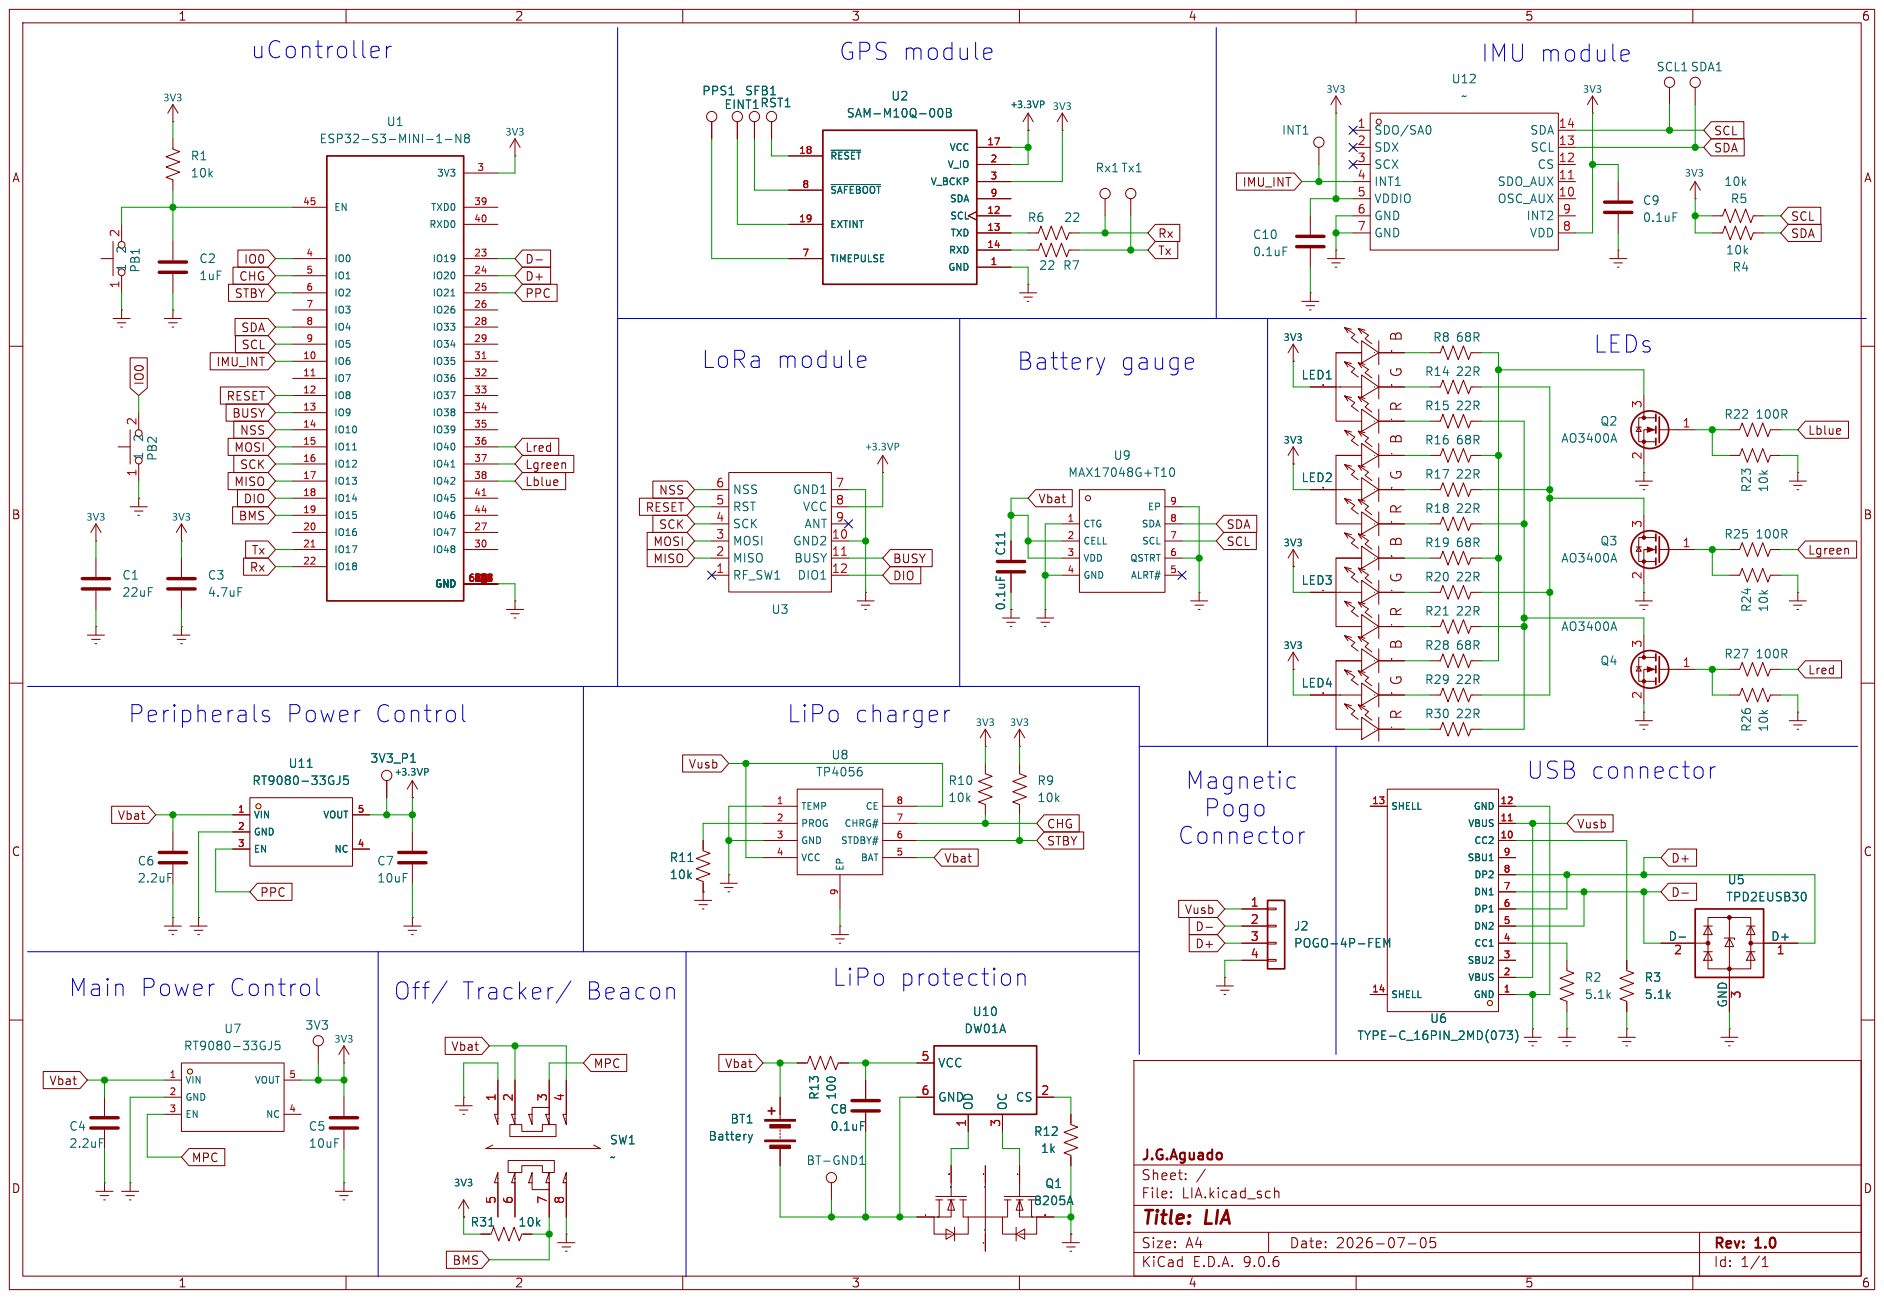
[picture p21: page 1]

9 CE 8 CHRG# 7 STDBY# 6 BAT 5 U8 TP4056
Vusb MPC

File: LIA.kicad_sch Sheet: / J.G.Aguado

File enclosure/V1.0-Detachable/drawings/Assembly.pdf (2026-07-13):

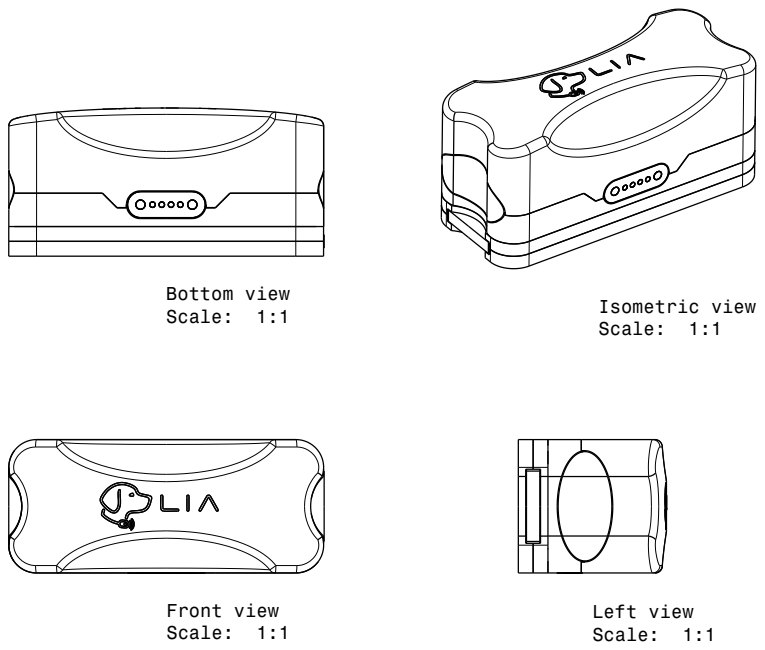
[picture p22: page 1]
Front view Scale: 1:1; Left view Scale: 1:1; Bottom view; Scale: 1:1; Isometric view

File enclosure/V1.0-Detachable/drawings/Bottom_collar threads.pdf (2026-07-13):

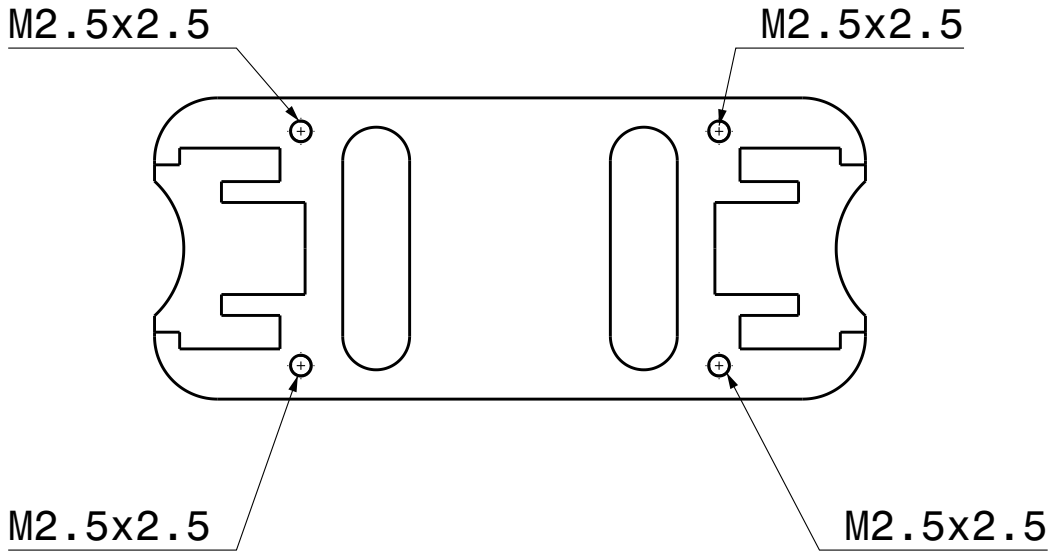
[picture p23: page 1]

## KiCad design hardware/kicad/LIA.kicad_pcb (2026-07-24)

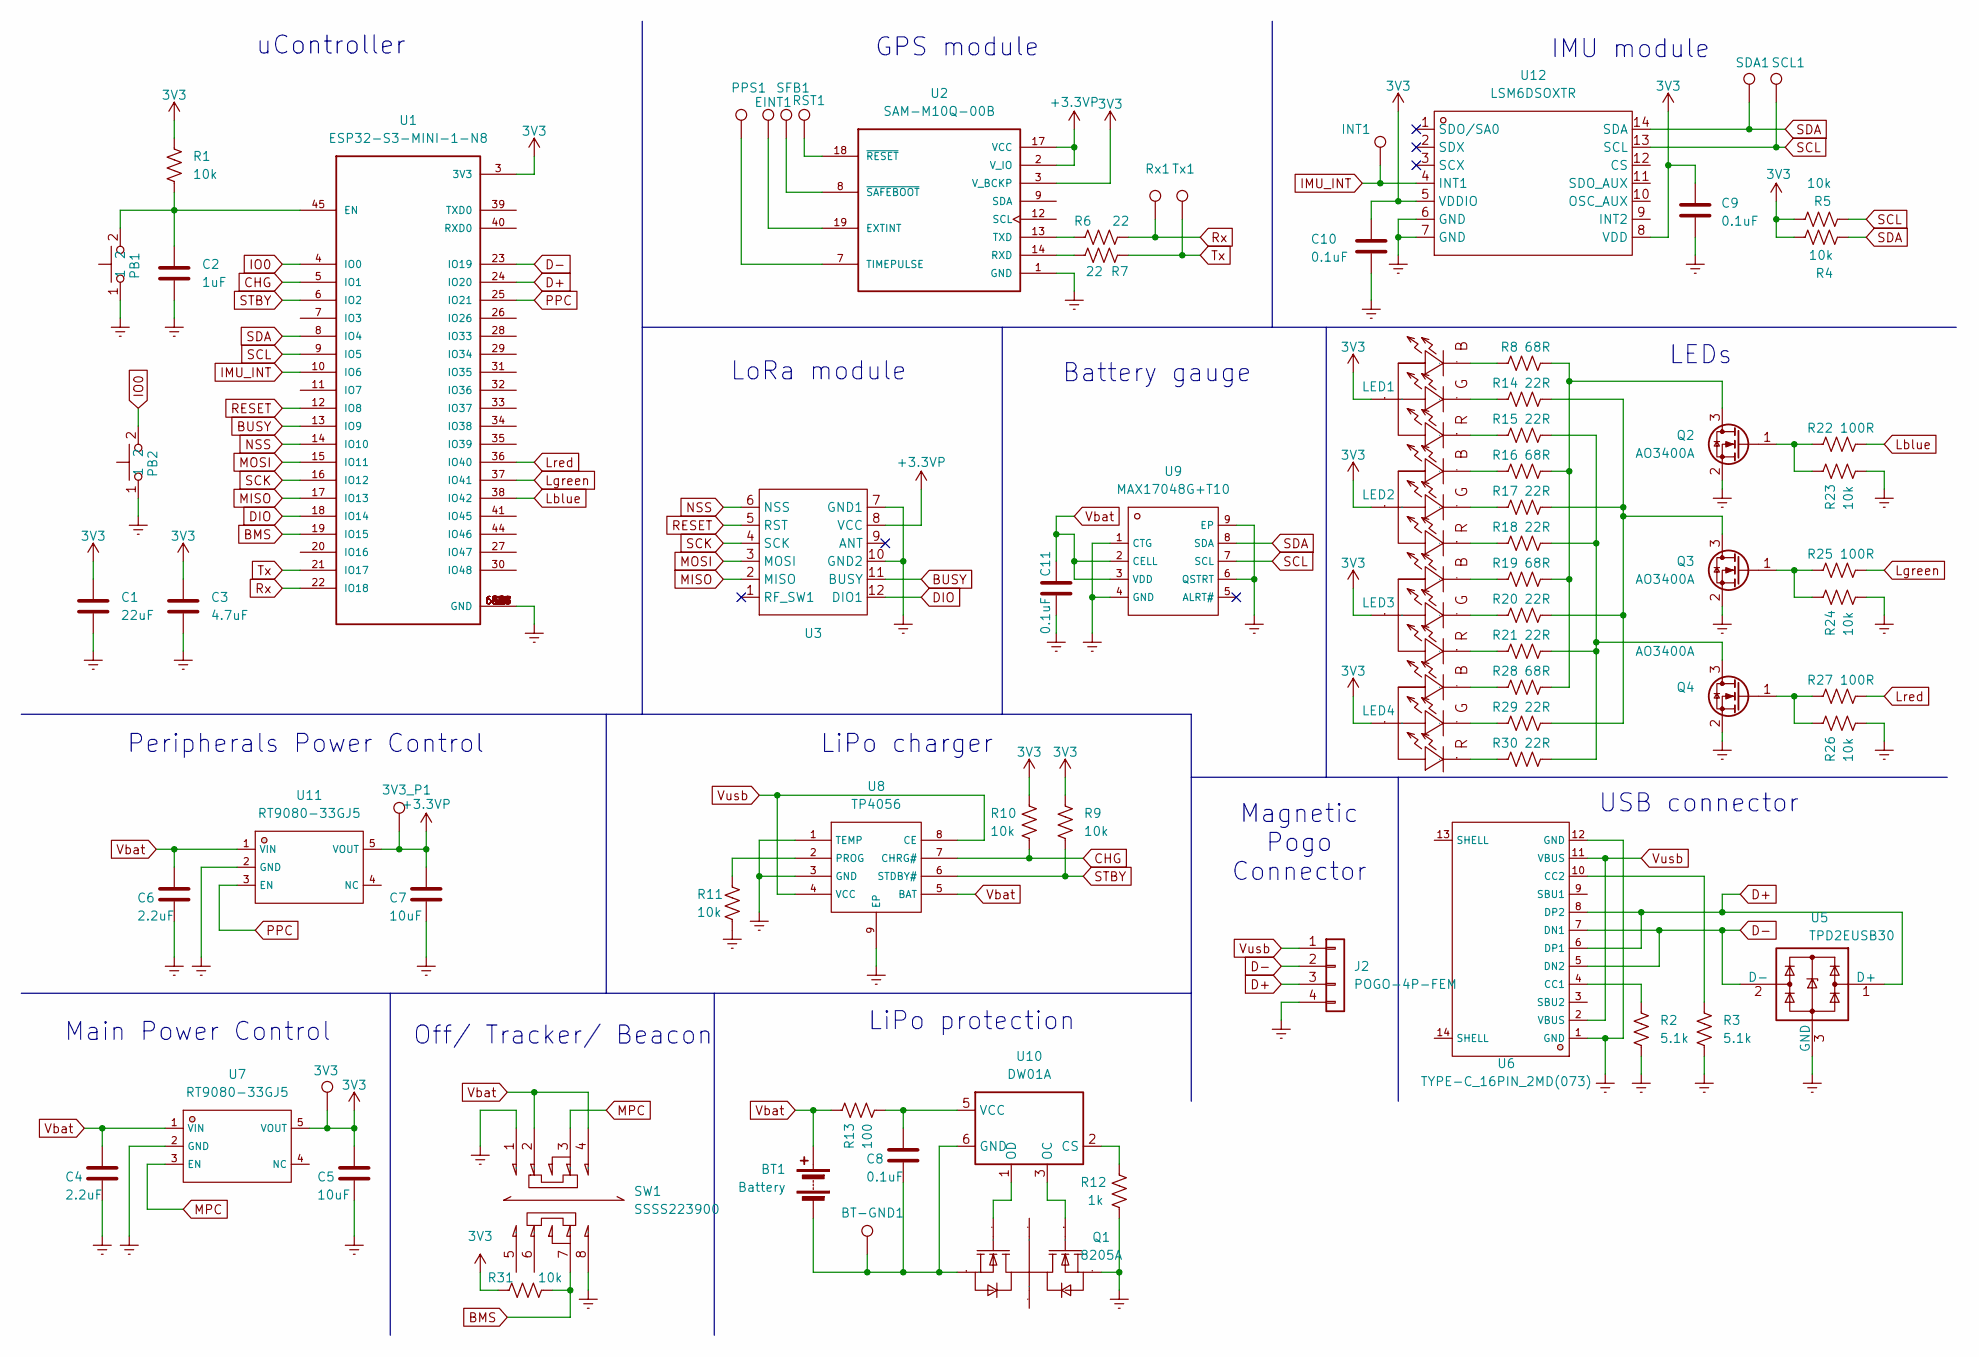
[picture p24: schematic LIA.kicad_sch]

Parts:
3V3, 3V3_P1: TestPoint; TestPoint_Pad_D1.0mm
BT1: Battery; BatteryClip_Keystone_54_D16-19mm
BT-GND1: TestPoint; TestPoint_Pad_D1.0mm
C1: 22uF; C_0805_2012Metric
C2: 1uF; C_0201_0603Metric
C3: 4.7uF; C_0201_0603Metric
C4, C6: 2.2uF; C_0201_0603Metric
C5, C7: 10uF; C_0603_1608Metric
C8, C9, C10, C11: 0.1uF; C_0201_0603Metric
EINT1: TestPoint; TestPoint_Pad_D1.0mm
INT1: TestPoint; TestPoint_Pad_D1.0mm
J2: POGO-4P-FEM; POGO-MAG-4P-FEM
LED1, LED2, LED3, LED4: MHS110CRGBCT; LED-SMD_4P-L3.2-W1.1_TJ-S3210SW5TCGLC2R2G-A5; Manufacturer Part MHS110CRGBCT; LCSC Part Name RGB三色 侧贴
PB1: TS-1088-AR02016; SW-SMD_L3.9-W3.0-P4.45; LCSC C318884
PB2: TS-1088-AR02016; SW-SMD_L3.9-W3.0-P4.45; LCSC C115357
PPS1: TestPoint; TestPoint_Pad_D1.0mm
Q1: 8205A; SOT-23-6_L2.9-W1.6-P0.95-LS2.8-BL; Manufacturer Part 8205A SOT23-6-VB; LCSC C351449
Q2, Q3, Q4: AO3400A; SOT-23
R1, R4, R5, R9, R10, R11, R23, R24, R26, R31: 10k; R_0201_0603Metric
R2, R3: 5.1k; R_0201_0603Metric
R6, R7: 22; R_0201_0603Metric
R8, R16, R19, R28: 68R; R_0201_0603Metric
R12: 1k; R_0201_0603Metric
R13: 100; R_0201_0603Metric
R14, R15, R17, R18, R20, R21, R29, R30: 22R; R_0201_0603Metric
R22, R25, R27: 100R; R_0201_0603Metric
RST1: TestPoint; TestPoint_Pad_D1.0mm
Rx1: TestPoint; TestPoint_Pad_D1.0mm
SCL1: TestPoint; TestPoint_Pad_D1.0mm
SDA1: TestPoint; TestPoint_Pad_D1.0mm
SFB1: TestPoint; TestPoint_Pad_D1.0mm
SW1: SSSS223900; SW-TH_SSSS223900; Manufacturer Part SSSS223900; LCSC Part Name SSSS223900
Tx1: TestPoint; TestPoint_Pad_D1.0mm
U1: ESP32-S3-MINI-1-N8; XCVR_ESP32-S3-MINI-1-N8; PARTREV v0.6; LCSC C2913206
U2: SAM-M10Q-00B; XCVR_SAM-M10Q-00B; PARTREV R03
U3: Wio-SX1262; MODULE12P-1.27-11X11.6MM
U5: TPD2EUSB30; Texas_DRT-3
U6: TYPE-C_16PIN_2MD(073); USB-C-SMD_TYPE-C-6PIN-2MD-073; LCSC C2765186
U7, U11: RT9080-33GJ5; TSOT-23-5_L2.9-W1.6-P0.95-LS2.8-BL; LCSC C841192
U8: TP4056; ESOP-8_L4.9-W3.9-P1.27-LS6.0-BL-EP; LCSC C16581
U9: MAX17048G+T10; DFN-8_L2.0-W2.0-P0.50-BL-EP; LCSC C2682616
U10: DW01A; SOT-23-6
U12: LSM6DSOXTR; LGA-14L_L3.0-W2.5-P0.50-TL; Manufacturer Part LSM6DSOXTR; LCSC C481766

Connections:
3V3: 3V3.1, C1.2, C3.2, C5.2, C9.2, C10.2, LED1.1 (+), LED2.1 (+), LED3.1 (+), LED4.1 (+), R1.1, R4.1, R5.1, R9.1, R10.1, R31.1, U1.3 (3V3), U2.3 (V_BCKP), U7.5 (VOUT), U12.5 (VDDIO), U12.8 (VDD)
+3.3VP: 3V3_P1.1, C7.2, U2.2 (V_IO), U2.17 (VCC), U3.8 (VCC), U11.5 (VOUT)
BMS: R31.2, SW1.7, U1.19 (IO15)
BUSY: U1.13 (IO9), U3.11 (BUSY)
CHG: R10.2, U1.5 (IO1), U8.7 (CHRG#)
D+: J2.3, U1.24 (IO20), U5.1 (D+), U6.6 (DP1), U6.8 (DP2)
D-: J2.2, U1.23 (IO19), U5.2 (D-), U6.5 (DN2), U6.7 (DN1)
DIO: U1.18 (IO14), U3.12 (DIO1)
GND: C1.1, C2.1, C3.1, C4.1, C5.1, C6.1, C7.1, C9.1, C10.1, C11.1, J2.4, PB1.1, PB2.1, Q1.3 (S), Q2.2 (S), Q3.2 (S), Q4.2 (S), R2.2, R3.2, R11.2, R12.2, R23.2, R24.2, R26.2, SW1.1, SW1.8, U1.1 (GND), U1.2 (GND), U1.42 (GND), U1.43 (GND), U1.46 (GND), U1.47 (GND), U1.48 (GND), U1.49 (GND), U1.50 (GND), U1.51 (GND), U1.52 (GND), U1.53 (GND), U1.54 (GND), U1.55 (GND), U1.56 (GND), U1.57 (GND), U1.58 (GND), U1.59 (GND), U1.60 (GND), U1.61 (GND), U1.61_1 (GND), U1.61_2 (GND), U1.61_3 (GND), U1.61_4 (GND), U1.61_5 (GND), U1.61_6 (GND), U1.61_7 (GND), U1.61_8 (GND), U1.62 (GND), U1.63 (GND), U1.64 (GND), U1.65 (GND), U2.1 (GND), U2.4 (GND), U2.5 (GND), U2.6 (GND), U2.10 (GND), U2.11 (GND), U2.15 (GND), U2.16 (GND), U2.20 (GND), U3.7 (GND1), U3.10 (GND2), U5.3 (GND), U6.1 (GND), U6.12 (GND), U7.2 (GND), U8.1 (TEMP), U8.3 (GND), U8.9 (EP), U9.1 (CTG), U9.4 (GND), U9.6 (QSTRT), U9.9 (EP), U11.2 (GND), U12.6 (GND), U12.7 (GND)
IMU_INT: INT1.1, U1.10 (IO6), U12.4 (INT1)
IO0: PB2.2, U1.4 (IO0)
Lblue: R22.2, U1.38 (IO42)
Lgreen: R25.2, U1.37 (IO41)
Lred: R27.2, U1.36 (IO40)
MISO: U1.17 (IO13), U3.2 (MISO)
MOSI: U1.15 (IO11), U3.3 (MOSI)
MPC: SW1.3, U7.3 (EN)
NSS: U1.14 (IO10), U3.6 (NSS)
unnamed: BT1.2 (-), BT-GND1.1, C8.1, Q1.1 (S), U10.6 (GND)
unnamed: LED1.2 (-), R8.1
unnamed: LED1.3 (-), R14.1
unnamed: LED1.4 (-), R15.1
unnamed: LED2.2 (-), R16.1
unnamed: LED2.3 (-), R17.1
unnamed: LED2.4 (-), R18.1
unnamed: LED3.2 (-), R19.1
unnamed: LED3.3 (-), R20.1
unnamed: LED3.4 (-), R21.1
unnamed: LED4.2 (-), R28.1
unnamed: LED4.3 (-), R29.1
unnamed: LED4.4 (-), R30.1
unnamed: Q2.3 (D), R8.2, R16.2, R19.2, R28.2
unnamed: Q2.1 (G), R22.1, R23.1
unnamed: Q3.3 (D), R14.2, R17.2, R20.2, R29.2
unnamed: Q3.1 (G), R24.1, R25.1
unnamed: Q4.3 (D), R15.2, R18.2, R21.2, R30.2
unnamed: Q4.1 (G), R26.1, R27.1
unnamed: C2.2, PB1.2, R1.2, U1.45 (EN)
unnamed: EINT1.1, U2.19 (EXTINT)
unnamed: R7.2, U2.14 (RXD)
unnamed: PPS1.1, U2.7 (TIMEPULSE)
unnamed: R6.1, U2.13 (TXD)
unnamed: RST1.1, U2.18 (~RESET)
unnamed: SFB1.1, U2.8 (~SAFEBOOT)
unnamed: R2.1, U6.4 (CC1)
unnamed: R3.1, U6.10 (CC2)
unnamed: R11.1, U8.2 (PROG)
unnamed: R12.1, U10.2 (CS)
unnamed: Q1.4 (G), U10.3 (OC)
unnamed: Q1.6 (G), U10.1 (OD)
unnamed: C8.2, R13.2, U10.5 (VCC)
PPC: U1.25 (IO21), U11.3 (EN)
RESET: U1.12 (IO8), U3.5 (RST)
Rx: R6.2, Rx1.1, U1.22 (IO18)
SCK: U1.16 (IO12), U3.4 (SCK)
STBY: R9.2, U1.6 (IO2), U8.6 (STDBY#)
Tx: R7.1, Tx1.1, U1.21 (IO17)
Vbat: BT1.1 (+), C4.2, C6.2, C11.2, R13.1, SW1.2, SW1.4, U7.1 (VIN), U8.5 (BAT), U9.2 (CELL), U9.3 (VDD), U11.1 (VIN)
Vusb: J2.1, U6.2 (VBUS), U6.11 (VBUS), U8.4 (VCC), U8.8 (CE)

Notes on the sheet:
Battery gauge
Off/ Tracker/ Beacon
LoRa module
Main Power Control
LiPo protection
IMU module
uController
Magnetic Pogo Connector
USB connector
LiPo charger
GPS module
Peripherals Power Control
LEDs

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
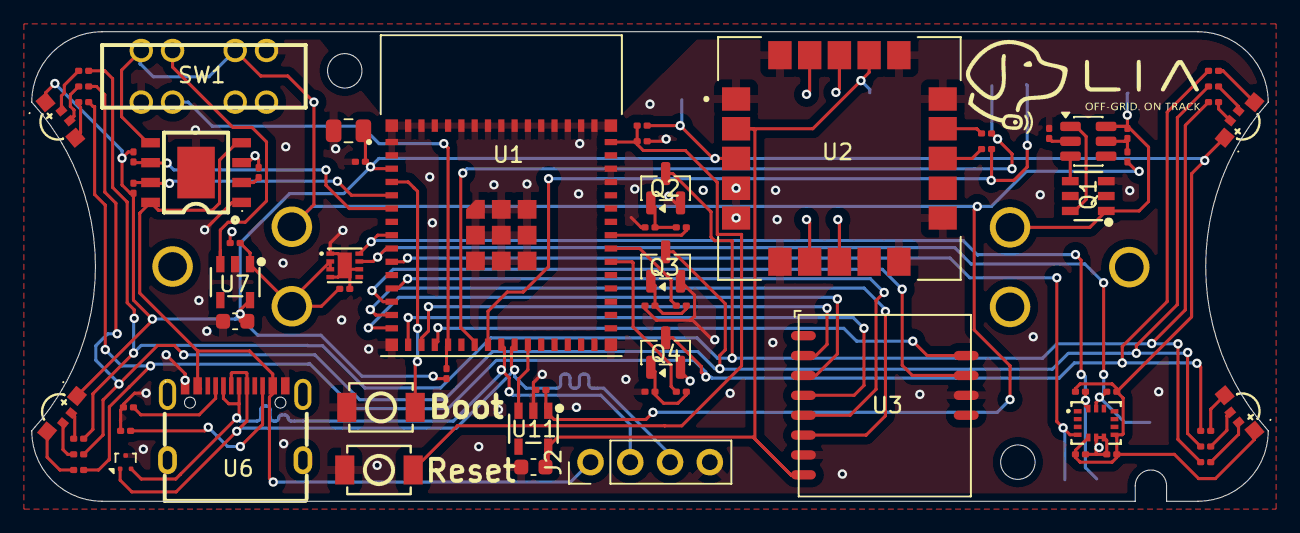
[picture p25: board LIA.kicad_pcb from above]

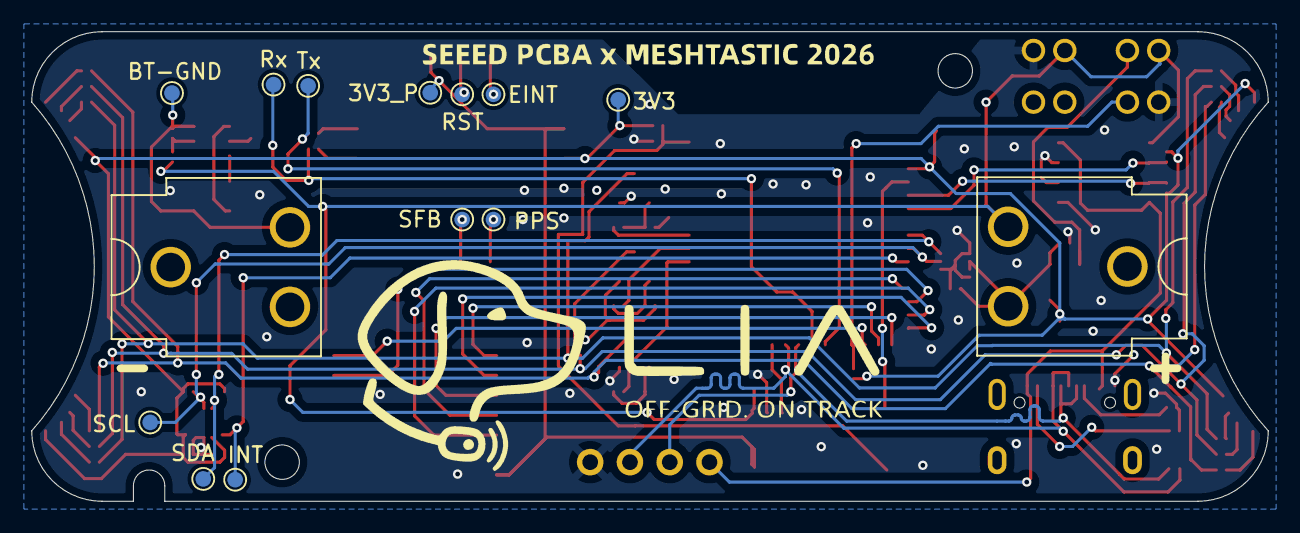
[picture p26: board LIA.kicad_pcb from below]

Board: 2 copper layers, 79.0 x 30.0 mm, 78 parts (13 on the bottom side), 61 nets.

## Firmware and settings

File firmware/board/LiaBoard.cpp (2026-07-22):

#include "LiaBoard.h"

#include "configuration.h"
#include "sleep.h"

namespace
{
constexpr int kRedLedLedcChannel = 7; // Arbitrary channel, unused elsewhere in this build.
constexpr int kRedLedFreqHz = 1000;
constexpr int kRedLedResolutionBits = 8;
} // namespace

LiaBoard &LiaBoard::instance()
{
    static LiaBoard board;
    return board;
}

void LiaBoard::begin()
{
    if (began_)
        return;
    began_ = true;

    pinMode(LIA_PIN_PPC, OUTPUT);
    disablePeripherals();

    pinMode(LIA_PIN_BMS, INPUT);
    pinMode(LIA_PIN_CHG, INPUT_PULLUP);
    pinMode(LIA_PIN_STBY, INPUT_PULLUP);

#if ESP_IDF_VERSION >= ESP_IDF_VERSION_VAL(5, 0, 0)
    ledcAttach(LIA_PIN_LED_RED, kRedLedFreqHz, kRedLedResolutionBits);
#else
    ledcSetup(kRedLedLedcChannel, kRedLedFreqHz, kRedLedResolutionBits);
    ledcAttachPin(LIA_PIN_LED_RED, kRedLedLedcChannel);
#endif
    setRedLed(0);
}

void LiaBoard::armDeepSleepHook()
{
    deepSleepObserver_.observe(&notifyDeepSleep);
}

void LiaBoard::enablePeripherals()
{
    digitalWrite(LIA_PIN_PPC, HIGH);
    peripheralsEnabled_ = true;
}

void LiaBoard::disablePeripherals()
{
    digitalWrite(LIA_PIN_PPC, LOW);
    peripheralsEnabled_ = false;
}

void LiaBoard::setRedLed(uint8_t brightness)
{
    // Was assumed common-anode (channel lights when driven LOW, so inverted
    // the duty cycle) -- real hardware showed the opposite: with BMS read
    // LOW, TrackerService calls setRedLed(0) intending OFF, but the LED was
    // observed ON (2026-07-22). The channel actually lights when driven
    // HIGH, so no inversion.
#if ESP_IDF_VERSION >= ESP_IDF_VERSION_VAL(5, 0, 0)
    ledcWrite(LIA_PIN_LED_RED, brightness);
#else
    ledcWrite(kRedLedLedcChannel, brightness);
#endif
}

bool LiaBoard::isCharging() const
{
    return digitalRead(LIA_PIN_CHG) == LOW;
}

bool LiaBoard::isChargeComplete() const
{
    return digitalRead(LIA_PIN_STBY) == LOW;
}

bool LiaBoard::isBmsHigh() const
{
    return digitalRead(LIA_PIN_BMS) == HIGH;
}

int LiaBoard::onDeepSleep(void *)
{
    // Cuts power to both the SX1262 and SAM-M10Q together (shared PPC rail --
    // this board has no way to sleep one without the other). Meshtastic only
    // fires notifyDeepSleep when shouldLoraWake() is false, which is only
    // true for ROUTER roles, so this always runs for LIA's TRACKER role.
    disablePeripherals();
    return 0;
}

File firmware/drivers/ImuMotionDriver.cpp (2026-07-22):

#include "ImuMotionDriver.h"

#include "configuration.h"

#include <Adafruit_LSM6DSOX.h>
#include <esp_attr.h>

namespace
{
// Confirmed via the boot-time I2C scan log ("QMI8658 found at address
// 0x6b") -- not this sensor family's 0x6A default address.
constexpr uint8_t kImuI2cAddress = 0x6B;
constexpr uint8_t kWakeDurationSamples = 1;
constexpr uint8_t kWakeThreshold = 20;

Adafruit_LSM6DSOX sensor;
} // namespace

volatile bool ImuMotionDriver::activityPending_ = false;

void IRAM_ATTR ImuMotionDriver::onInterrupt()
{
    activityPending_ = true;
}

bool ImuMotionDriver::begin()
{
    if (began_)
        return true;

    if (!sensor.begin_I2C(kImuI2cAddress))
        return false;

    sensor.setAccelRange(LSM6DS_ACCEL_RANGE_2_G);
    sensor.enableWakeup(true, kWakeDurationSamples, kWakeThreshold);
    sensor.configInt1(false, false, false, false, true); // route the wake-up event to INT1

    pinMode(LIA_PIN_IMU_INT, INPUT);
    began_ = true;
    setInterruptEnabled(true);
    return true;
}

void ImuMotionDriver::setInterruptEnabled(bool enabled)
{
    if (!began_)
        return;

    if (enabled) {
        activityPending_ = false;
        attachInterrupt(digitalPinToInterrupt(LIA_PIN_IMU_INT), onInterrupt, RISING);
    } else {
        detachInterrupt(digitalPinToInterrupt(LIA_PIN_IMU_INT));
    }
}

bool ImuMotionDriver::consumeActivityDetected()
{
    if (!activityPending_)
        return false;

    activityPending_ = false;
    sensor.awake(); // Reading WAKEUP_SRC clears the sensor's own latch.
    return true;
}

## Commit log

2026-07-06 Add hardware first revision
    [LIA.kicad_pcb, LIA.kicad_sch, LIA_PCB.step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]
2026-07-13 Add enclosure first design review
    [Bottom_collar.stl, Bottom_collar.stp, Bottom_enclosure.stl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]
2026-07-19 Add LIA v1 Meshtastic firmware (Phases 0-3.5)
    PlatformIO board variant, LiaBoard hardware abstraction (PPC/LED/charger/BMS),
    and TrackerService periodic mesh sender. Verified end-to-end on real hardware:
    clean boot, PPC-gated peripherals powering the SX1262 and SAM-M10Q, and the
    target node receiving "LIA Radio Test" over LoRa.
2026-07-19 Phase 4/5: GPS position reporting via TrackerService
    Phase 4 needed no new code -- stock Meshtastic already auto-detects the
    SAM-M10Q (GNSS_MODEL_UBLOX10) and handles NMEA/UBX via the Phase 0 pin
    config. Phase 5: TrackerService now sends a real meshtastic_Position
    packet instead of the fixed test payload, built from localPosition the
    same way stock PositionModule does, skipping the send when there's no
    fix yet. Verified on hardware: real over-the-air TX/RX against a live
    39-node mesh, correct skip behavior with no GPS fix.
2026-07-19 Phase 6: BMS-driven tracker/beacon state machine
    Resolves the BMS polarity per AGENTS.md (authoritative over MOD.md's
    opposite naming): BMS HIGH is continuous mode (RED LED solid, 30s send
    cadence, never sleeps); BMS LOW is the sleep-cycle mode (send, then deep
    sleep ~60s via doDeepSleep, wake via RTC timer, repeat). Mirrors stock
    PositionModule's own tracker-role sleep pattern rather than inventing new
    sleep logic, since PowerFSM explicitly defers sleep to modules for TRACKER
    roles. LiaBoard now cuts PPC via a notifyDeepSleep observer before any
    deep sleep. Verified on hardware: BMS-HIGH path runs cleanly with the
    correct cadence and no crash; BMS-LOW path builds clean but still needs
    the p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
    [LiaBoard.cpp]
2026-07-19 Add standalone GPS bring-up test tool
    firmware/tools/gps_test/: no Meshtastic, no LoRa, no LED -- just powers
    the SAM-M10Q (PPC high) and prints whatever TinyGPSPlus decodes over
    native-USB serial every 10s. Verified on hardware: clean UART link
    (steady charsProcessed, zero failedChecksum), UTC time sync, and a
    real position fix acquired outdoors.
    [main.cpp]
2026-07-20 Fix deep-sleep observer ordering, add channel-targeted position sending
    LiaBoard registered its notifyDeepSleep observer in begin() (called from
    earlyInitVariant(), before the radio/GPS are initialized), cutting PPC
    before RadioInterface and GPS could gracefully command their hardware to
    standby -- crashed with SX126x RadioLib err=-707 on a real deep sleep.
    Split registration into armDeepSleepHook(), called from lateInitVariant()
    instead, after both of those register their own observers. Verified fixed
    across two complete sleep/wake cycles on hardware.
    TrackerService now sends position packets only on the channel named "Test"
    (resolved by name at send time, not a hardcoded index) instead of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
    [LiaBoard.cpp, variant.cpp]
2026-07-22 Phase 7: report charging status as mesh text messages
    AGENTS.md originally specified RED LED breathing/off for charge status,
    but TrackerService already owns the RED LED for BMS-mode indication
    (Phase 6), and explicit instruction (2026-07-22) asked for text messages
    to the target node instead: "Charging" when CHG is detected, "Device
    charged" when STBY reads HIGH.
    Added ChargeStatusService (SinglePortModule + OSThread, same shape as
    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
2026-07-22 Phase 8: BMS/USB deep-sleep wake sources, fix RED LED polarity bug
    Added an ext0 (CHG, active-low) and ext1 (BMS, active-high) RTC-IO wake
    source pair, armed from a variant_shutdown() override called right before
    every cpuDeepSleep(). Without this, the sleep-cycle branch only woke on its
    60s RTC timer, so flipping the BMS switch or plugging in a charger while
    the board was mid-sleep would sit unnoticed for up to that long. No
    separate VBUS-sense pin exists on this board, so CHG (asserted while the
    TP4056 is actively charging) is used as the closest available proxy for
    "USB connected".
    Also fixes a RED LED polarity bug found during Phase 8 live testing:
    setRedLed() assumed common-anode wirin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
    [LiaBoard.cpp, variant.cpp]
2026-07-22 Fix stale CHG/STBY/LED polarity comments in lia_v1/variant.h
    These pin-definition comments still described the original datasheet
    assumptions (open-drain active-low CHG/STBY, common-anode LED) that Phase
    7/8's real-hardware testing overturned for STBY and the LED. LiaBoard.cpp
    and board/README.md were already updated; this file was missed.
    [variant.h]
2026-07-22 Fix STBY polarity: charge-complete is active-low, not active-high
    The user provided the actual TP4056/board wiring: STBY is pulled HIGH by
    an external resistor while charging, then pulled LOW by an internal
    N-channel MOSFET once the charge cycle completes (CHG behaves the same
    way, just active-low during charging instead). An earlier Phase 7
    instruction to treat STBY-HIGH as "charge complete" had it backwards;
    that reading passed its live test, likely because the test's
    charge-complete state happened to coincide with conditions where either
    polarity looked plausible. isChargeComplete() now reads STBY == LOW to
    match the real wiring, with isCharging()'s CHG read unchanged.
    [LiaBoard.cpp, variant.h]
2026-07-22 Enable I2C on lia_v1 after SDA/SCL rework fixes IMU wiring defect
    The LSM6DSOXTR IMU's SDA/SCL were crossed as manufactured, causing bus
    errors -- this is why lia_v1's variant.h previously forbade I2C entirely.
    A solder rework crossing them back on this unit fixes that, so I2C_SDA/
    I2C_SCL (GPIO4/5) are now defined directly on lia_v1, same as lia_v2.
    No LIA-specific code needed: Meshtastic's stock Wire.begin() + ScanI2C
    already detects both parts. Confirmed on real hardware: clean boot, no
    crash, "MAX17048 found at address 0x36" and "QMI8658 found at address
    0x6b" (0x6C WHO_AM_I -- the LSM6DSOX family's chip ID; ScanI2C resolves
    this address/ID combination to its QMI8658 label rather than L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
    [variant.h]
2026-07-22 Add CommandService: text commands for GPS/battery/IMU/charge notifications
    lia_v1 only (IMU_ON/IMU_OFF need the LSM6DSOXTR that lia_v2 removed).
    Commands (case-insensitive): GPS, BATTERY, IMU_ON, IMU_OFF, CHG_ON,
    CHG_OFF, STB_ON, STB_OFF, HELP. Accepts a command on the private "Test"
    channel or as a direct message addressed to us, whichever way it arrives.
    Added ImuMotionDriver (firmware/drivers/, a new directory per AGENTS.md's
    layout) to talk to the LSM6DSOXTR directly via Adafruit_LSM6DSOX: stock
    Meshtastic's AccelerometerThread never drives this sensor, since ScanI2C
    resolves its WHO_AM_I (0x6C) to the QMI8658 device type, which
    AccelerometerThread has no case for. IMU_ON arms a real GP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
    [CommandService.cpp, ImuMotionDriver.cpp, variant.cpp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]
2026-07-24 Add LED_ON/OFF command; confirm battery gauge reading is correct
    TrackerService gains setManualLed() (reached via a new self-registering
    instance(), same pattern as ChargeStatusService) so CommandService's new
    LED_ON/LED_OFF commands can override the RED LED. Once set, runOnce()
    stops driving the LED from BMS state for the rest of that boot -- there's
    no "back to automatic" command, matching the other ON/OFF toggles'
    persist-until-changed semantics.
    BATTERY still read ~0-1% after the earlier no-reset fix. Built a
    standalone firmware/tools/battery_test/ project (no Meshtastic) to compare
    the no-reset raw register read against the stock Adafruit_MAX17048
    library side by side. Both agreed exac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
    [CommandService.cpp, main.cpp, variant.cpp]
2026-07-24 Use space instead of underscore for ON/OFF commands
    IMU_ON/IMU_OFF/CHG_ON/CHG_OFF/STB_ON/STB_OFF/LED_ON/LED_OFF become
    "IMU ON"/"IMU OFF"/etc, per explicit instruction to sound more natural.
    Real usage already showed the mismatch: a capture from testing the
    underlying LED_OFF -> LEDOFF rename showed the user naturally typing
    "Led off" with a space, which the underscore/concatenated forms both
    missed silently.
    handleReceived() now also trims leading whitespace and collapses internal
    whitespace runs to a single space before matching, so "led off" or a
    stray tab between words still resolves to the same command.
    Confirmed on real hardware: "Led on"/"Led off" (natural spacing, mixed
    case) both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
    [CommandService.cpp]
2026-07-24 SDA/SCL corrected on IMU
    [LIA.kicad_pcb, LIA.kicad_sch]
2026-07-26 Refresh documentation for current firmware; reorganize enclosure into 3 versions
    Documentation was well behind the actual firmware -- several pages still
    described a pre-implementation, speculative state (a nonexistent
    provision.py tool, "boot currently stalls," a three-state BMS switch, an
    RGB LED that's actually RED-only and active-high not common-anode). Brings
    every firmware doc page in line with what's actually implemented and
    confirmed on real hardware: the lia_v1/lia_v2 board split, the BMS state
    machine, charge-status messages, the battery gauge (including the reset
    and read-ordering bugs found and fixed), the IMU driver (including why
    stock Meshtastic doesn't drive it), the RED LED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
    [Antenna_elbow.stl, Bottom_collar.stl, Bottom_collar.stp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]
2026-07-26 Fix documentation review items, switch to DM-only addressing, add repo infra
    - Redirect firmware flashing to the build guide (web flasher doesn't support lia_v1)
    - Correct docs claiming two firmware variants; V1.0/V1.1 run identical lia_v1 firmware
    - Convert admonitions to Starlight-native directives so they render styled
    - Add alternative omnidirectional 868/915MHz antenna option
    - Rename enclosure versions (V1.0-Detachable/V1.0-Fixed/V1.1-Fixed) and fix
    STL viewer WebGL context exhaustion
    - Replace private-channel addressing with direct-message-only addressing to a
    predefined target node, across firmware (CommandService, TrackerService,
    ChargeStatusService, MeshTargets.h) and docs
    -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
    [Antenna_elbow.stl, Bottom_collar.stl, Bottom_collar.stp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]
2026-07-26 Commit hardware/pcb/bom/, required by the website build
    astro.config.mjs's syncGeneratedAssets() hard-requires hardware/pcb/bom/ at
    build time (cpSync into public/generated/bom for the BOM page's interactive
    embed) -- it was left untracked as an unrelated cleanup deferral, which
    worked locally (the file was already on disk) but broke CI's checkout,
    which has nothing there at all.
    hardware/kicad/bom/, hardware/kicad/production/, and hardware/datasheets/
    remain untracked -- nothing in the website references them at build time.
2026-07-26 Fix broken links surfaced by lychee now that --root-dir actually resolves
    Real content bugs:
    - downloads.md/manufacturing.md linked to the old flat enclosure/step/ and
    enclosure/stl/ paths, stale since the enclosure reorg into three
    per-version folders (V1.0-Detachable/V1.0-Fixed/V1.1-Fixed) -- updated to
    link each version's own step/stl exports.
    - schematics.mdx linked to hardware/schematics/references/, which is
    gitignored on purpose (third-party reference material, not published) --
    reworded to stop linking to a path that will never resolve on GitHub.
    - getting-started.mdx linked to meshtastic.org/docs/software/apps/, which
    Meshtastic's own docs restructured away from -- updat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
2026-07-26 Move demo video from docs index to the marketing homepage (Hero.astro)
    The video belongs on https://jgaguado.github.io/LIA (the actual landing
    page), not https://jgaguado.github.io/LIA/docs -- moved the autoplay
    YouTubeFacade embed into Hero.astro in place of the static header photo,
    using that same photo as the poster/fallback. docs/index.mdx no longer
    embeds any components, so renamed it back to .md.
2026-07-29 Add missing hardware files
    [LIA_PCB.stl, bom.csv, designators.csv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]
2026-07-29 Illustrate the docs with build photos: flip-card features, IIC fix, gallery
    - FeatureGrid: each feature card now flips on hover (tap on touch devices)
    to reveal a matching photo on the back -- Meshtastic Powered/Beacon Mode
    LED/GPS Tracking/Open Source map directly to the four Features/ photos.
    - development-history.mdx (renamed from .md to embed images): the I2C
    rework paragraph now has a 4-photo Gallery walking through the actual
    fix -- expose the routes, cut them, cross them with wire, seal with hot
    glue -- using the existing Gallery.astro click-to-enlarge component
    (prev/next navigation scoped to its own image group).
    - Added a second Gallery ("build gallery") with the remain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

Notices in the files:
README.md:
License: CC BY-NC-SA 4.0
